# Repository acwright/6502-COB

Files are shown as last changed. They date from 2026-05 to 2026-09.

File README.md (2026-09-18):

6502-COB
========

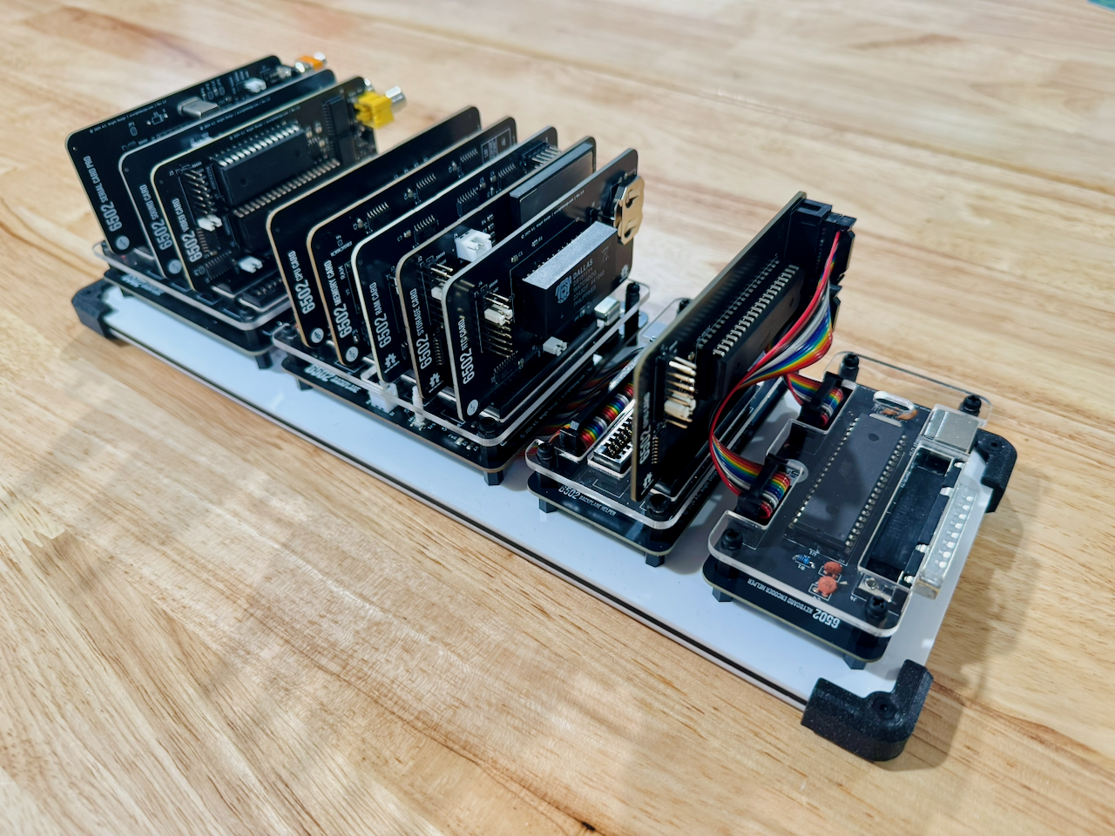
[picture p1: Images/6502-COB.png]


An **AC6502** retro-style 8-bit computer based on the **65C02** microprocessor.

> 📖 **Guide:** [AC6502 Documentation](https://acwright.github.io/6502-DOCS/) — the user's and programmer's guide for the whole family.
> See [COB's page in the family appendix](https://acwright.github.io/6502-DOCS/family/cob).

---

## Table of Contents

- [Overview](#overview)
- [Architecture](#architecture)
- [Systems](#systems)
- [Software](#software)
- [Hardware](#hardware)
  - [Backplanes](#backplanes)
  - [Cards](#cards)
  - [Helpers](#helpers)
- [Firmware](#firmware)
  - [KEH Controller](#keh-controller)
  - [PS2 Keyboard Controller](#ps2-keyboard-controller)
  - [STP Controller](#stp-controller)
- [CAD](#cad)
- [Production](#production)
- [Schematics](#schematics)
- [Libraries](#libraries)
- [Bill of Materials](#bill-of-materials)
  - [Backplane](#backplane)
  - [Backplane Helper](#backplane-helper)
  - [Backplane Pro](#backplane-pro)
  - [Blinkenlights Card](#blinkenlights-card)
  - [Breadboard Helper](#breadboard-helper)
  - [Clock Helper](#clock-helper)
  - [CPU Card](#cpu-card)
  - [CPU Card Pro](#cpu-card-pro)
  - [DB25 Helper](#db25-helper)
  - [GPIO Breadboard Helper](#gpio-breadboard-helper)
  - [GPIO Card](#gpio-card)
  - [GPIO Helper](#gpio-helper)
  - [Joystick Helper](#joystick-helper)
  - [Keyboard Encoder Helper](#keyboard-encoder-helper)
  - [Keyboard Helper](#keyboard-helper)
  - [LCD Board](#lcd-board)
  - [LCD Card](#lcd-card)
  - [Mega Helper](#mega-helper)
  - [Memory Card](#memory-card)
  - [Prototype Card](#prototype-card)
  - [PS2 Helper](#ps2-helper)
  - [RAM Card](#ram-card)
  - [RTC Card](#rtc-card)
  - [Serial Card](#serial-card)
  - [Serial Card Pro](#serial-card-pro)
  - [Sound Card](#sound-card)
  - [Storage Card](#storage-card)
  - [Storage Card Pro](#storage-card-pro)
  - [VERA Helper](#vera-helper)
  - [VGA Card](#vga-card)
  - [VGA Card Pro](#vga-card-pro)
  - [Video Card](#video-card)
  - [Video Card Pro](#video-card-pro)
- [Purchase](#purchase)
- [License](#license)

---

## Overview

The AC6502 ecosystem is a family of open-source, 65C02-based computers sharing a common architecture, memory map, and [BIOS](https://github.com/acwright/6502-BIOS). Each computer in the family is purpose-built for a different use case but runs the same software and firmware.

The **COB** (Computer on a Backplane) is a full-featured modular desktop computer. It features a real 65C02 CPU, a backplane architecture with expandable card slots, up to 544KB RAM, composite or VGA video output, CompactFlash or SD storage, a real-time clock, and support for PS/2 keyboards, matrix keyboards, and Atari 2600-compatible joysticks.

## Architecture

All AC6502 computers share:

- **CPU**: 65C02 (or accurate emulation)
- **Memory**: 32KB RAM + 32KB ROM, with optional banked RAM expansion
- **Memory Map**: Standardized across the ecosystem — zero page, stack, I/O space ($8000–$9FFF), system ROM, and interrupt vectors at $FFFA–$FFFF
- **Bus**: 16-bit address bus, 8-bit bidirectional data bus, standard 65C02 control signals (RW, PHI2, RESET, IRQ, NMI, RDY, SYNC)
- **BIOS**: A common [BIOS](https://github.com/acwright/6502-BIOS) provides the kernel, monitor, and BASIC interpreter across all systems

## Systems

| Project | Description |
|---|---|
| [6502-ACE](https://github.com/acwright/6502-ACE) | All-in-one Computer Experience — A single board computer |
| [6502-COB](https://github.com/acwright/6502-COB) | Computer On a Backplane — Modular desktop computer with expandable card slots (YOU ARE HERE) |
| [6502-DEV](https://github.com/acwright/6502-DEV) | Development Environment Vehicle — Emulation-based dev system |
| [6502-KIM](https://github.com/acwright/6502-KIM) | Keypad Input Monitor - KIM-1 inspired minimal computer |
| [6502-VCS](https://github.com/acwright/6502-VCS) | Video Computer System — Cartridge-based retro gaming console |

## Software

| Project | Description |
|---|---|
| [6502-BIOS](https://github.com/acwright/6502-BIOS) | The shared BIOS (kernel, monitor, BASIC) for all AC6502 computers |
| [6502-EMULATOR](https://github.com/acwright/6502-EMULATOR) | Emulator for the whole family — desktop app, browser build, and a command line for scripted runs |
| [6502-PRG](https://github.com/acwright/6502-PRG) | Template project for writing assembly language programs |
| [6502-CRT](https://github.com/acwright/6502-CRT) | Template project for writing assembly language cartridges |
| [6502-ASM](https://github.com/acwright/6502-ASM) | Assembly language example programs and demos |
| [6502-BAS](https://github.com/acwright/6502-BAS) | BASIC program listings |
| [6502-WOZMON](https://github.com/acwright/6502-WOZMON) | Wozmon as a standalone ROM |
| [6502-NOP](https://github.com/acwright/6502-NOP) | An all-NOP ROM, for probing a board during bring-up |
| [6502-DOCS](https://github.com/acwright/6502-DOCS) | The documentation site — the guide, the printable reference cards, branding and label artwork |
| [cffs](https://github.com/acwright/cffs) | Builds CompactFlash disk images for the BIOS filesystem |
| [bastok](https://github.com/acwright/bastok) | Tokenizes BASIC listings into `.prg` images, and back |
| [bin2woz](https://github.com/acwright/bin2woz) | Converts a binary into a Wozmon serial upload |

## Hardware

This repository contains KiCad 7.0+ PCB designs for the backplanes, cards, and helpers that make up the COB system.

### Backplanes

**`Hardware/Backplane/`** — Passive backplane providing 5 card slots with full bus interconnect across all slots.

**`Hardware/Backplane Pro/`** — Enhanced backplane with integrated clock generation, reset circuitry, and power distribution plus 5 card slots. Rev 1.1 moves to entirely through-hole components and adds an onboard power switch and DC barrel jack input.

**`Hardware/Backplane Helper/`** — Adds additional card slots to expand the total backplane configuration up to 12 slots.

### Cards

**`Hardware/CPU Card/`** — Hosts the 65C02 CPU in a card form factor for backplane-based COB systems.

**`Hardware/CPU Card Pro/`** — Hosts a 65816 16-bit CPU (backward-compatible with 65C02). *(Untested)*

**`Hardware/Memory Card/`** — Provides 32KB SRAM and 32KB EEPROM with address decoding logic for COB systems using the CPU Card.

**`Hardware/RAM Card/`** — 512KB banked RAM expansion organized as two 256KB banks with 256 × 1KB windows each.

**`Hardware/RTC Card/`** — Real-time clock via Dallas DS1511Y with battery backup and 256 bytes of battery-backed SRAM.

**`Hardware/GPIO Card/`** — General-purpose I/O via 65C22 VIA supporting keyboards, joysticks, timers, and custom devices.

**`Hardware/Serial Card/`** — RS-232 serial communication via 65C51 ACIA and MAX232 level shifter.
Female DB-9 wired as **DCE**, so a straight-through cable reaches a PC. `DCD` and `DSR` are tied to
ground; `DTR` is not connected. The `CTS EN` jumper (J4) picks whether the ACIA's `CTS` comes from
ground or from the cable — **ground is the default**, which leaves the transmitter always free to
send.

**`Hardware/Serial Card Pro/`** — Enhanced serial card with full modem control signals (DTR, DCD, DSR).
Male DB-9 wired as **DTE**, like a PC, so reaching a laptop needs a **null-modem** cable — unlike the
plain Serial Card. `CTS`, `DSR` and `DTR` always reach the cable; the `DCD EN` jumper picks ground or
the cable for `DCD` — **ground is the default**.

**The handshake lines are not decoration.** On a real R6551, measured on a KIM in 2026: `CTS` high
stops the transmitter dead, and `DCD` high stops the receiver and the arriving byte is lost. A card
jumpered to take either from the cable, plugged into something that does not assert them, looks like
a dead board — no banner, no echo — until the line comes back. Ground is the default for exactly
that reason.

**`Hardware/VGA Card/`** — VGA 640×480 video output via Raspberry Pi Pico running [Pico9918](https://github.com/visrealm/pico9918) with TMS9918A-compatible graphics modes.

**`Hardware/VGA Card Pro/`** — Fully programmable VGA output using Pi Pico with custom firmware. *(Untested)*

**`Hardware/Video Card/`** — Composite video output via TMS9918A Video Display Processor with 16KB video RAM.

**`Hardware/Video Card Pro/`** — Enhanced composite video card. *(Untested)*

**`Hardware/Sound Card/`** — 3-voice SID audio output via ARMSID module with RCA line-level output.

**`Hardware/Storage Card/`** — CompactFlash storage interface supporting up to 128GB via IDE-compatible protocol.

**`Hardware/Storage Card Pro/`** — SD card (up to 32GB) and 16MB onboard SPI flash storage interface. *(Untested, experimental — the stock BIOS has no driver for it; see [STP Controller](#stp-controller))*

**`Hardware/LCD Card/`** — 16×2 character LCD display via 65C22 VIA in 4-bit or 8-bit mode.

**`Hardware/Blinkenlights Card/`** — Visual bus monitoring with LEDs showing address bus (16), data bus (8), and control signals (8) in real time.

**`Hardware/Prototype Card/`** — Blank prototyping area with integrated breadboard and full bus access headers.

### Helpers

**`Hardware/Keyboard Encoder Helper/`** — ATmega1284p-based dual keyboard encoder supporting PS/2 keyboard and 8×8 matrix keyboard simultaneously via 65C22 VIA.

**`Hardware/PS2 Helper/`** — ATmega328p-based PS/2 keyboard bridge that drives an MT8808 analog crosspoint switch to emulate a matrix keyboard. Its output is a raw 8×8 matrix and feeds the matrix inputs of a Keyboard Encoder Helper, which is what talks to the 65C22 VIA — not the VIA directly.

**`Hardware/Keyboard Helper/`** — 64-key matrix keyboard with Atari 2600-compatible joystick support.

**`Hardware/GPIO Helper/`** — 8 buttons and 8 LEDs for testing and debugging GPIO Card connections.

**`Hardware/GPIO Breadboard Helper/`** — Breadboard interface adapter for the GPIO Card.

**`Hardware/Joystick Helper/`** — Atari 2600-style dual joystick connector and interface board.

**`Hardware/Clock Helper/`** — Manual clock control providing single-step, free-run, and halt modes for debugging real CPU systems.

**`Hardware/DB25 Helper/`** — GPIO to DB25 connector adapter for external device interfacing.

**`Hardware/Breadboard Helper/`** — Exposes the full AC6502 bus to a breadboard for prototyping and experimentation.

**`Hardware/Mega Helper/`** — Arduino Mega 2560 interface adapter for the AC6502 bus.

**`Hardware/LCD Board/`** — 320×240 TFT LCD display (ILI9341) interfaced via 65C22 VIA. *(Untested)*

**`Hardware/VERA Helper/`** — VERA FPGA video module adapter for the AC6502 bus.

## Firmware

This repository contains [PlatformIO](https://platformio.org/)-based firmware for the COB system's microcontroller helpers.

### KEH Controller
`Firmware/KEH Controller/`

Firmware for the ATmega1284p on the Keyboard Encoder Helper. Provides:

- Simultaneous PS/2 keyboard and 8×8 matrix keyboard scanning
- ASCII conversion with modifier key support (Shift, Ctrl)
- Buffered, debounced input handling
- Parallel I/O to the AC6502 bus via 65C22 VIA

See [Firmware/KEH Controller/README.md](./Firmware/KEH%20Controller/README.md) for setup and usage instructions.

### PS2 Keyboard Controller
`Firmware/PS2 Keyboard Controller/`

Firmware for the ATmega328p on the PS2 Helper. Provides:

- Interrupt-driven PS/2 keyboard scan code reading
- MT8808 analog crosspoint switch matrix control
- Make/break detection and extended scan code support
- Function key emulation via FN key combinations

The MT8808 closes row/column contacts in place of physical key switches, so this
card connects to the **matrix inputs of a Keyboard Encoder Helper**, not to a
65C22 VIA. The encoder does the scanning and ASCII conversion; wired straight to
a VIA the card produces nothing, as the BIOS has no matrix-scanning code.

See [Firmware/PS2 Keyboard Controller/README.md](./Firmware/PS2%20Keyboard%20Controller/README.md) for setup and usage instructions.

### STP Controller
`Firmware/STP Controller/`

Firmware for the ATmega328p on the Storage Card Pro. Provides:

- Memory-mapped SPI controller for 6502 bus access
- Support for SD card, 16MB SPI flash, and external SPI devices
- Dual-speed SPI (4 MHz normal operation, 400 kHz initialization)
- PHI2-synchronized interface for reliable 6502 communication

⚠️ **Experimental.** The Storage Card Pro is not part of the default I/O set the
BIOS probes for, and no COB machine is built around it today. The BIOS storage
slot expects eight True IDE CompactFlash registers at `$8C00–$8C07`; this card
presents two SPI registers instead, so a stock BIOS reports `NO DEVICE` for every
storage path. Using it needs a modified BIOS or software that drives the two
registers directly.

See [Firmware/STP Controller/README.md](./Firmware/STP%20Controller/README.md) for setup and usage instructions.

## CAD
`CAD/`

3D-printable enclosure parts and laser-cut top panels for the COB system.

## Production
`Production/`

JLCPCB-ready Gerber files and BOM/CPL for PCB fabrication and assembly.

## Schematics
`Schematics/`

PDF schematics for each board.

## Libraries
`Libraries/`

Shared KiCad symbol and footprint libraries used across all AC6502 hardware projects.

## Bill of Materials

### Backplane

| Reference | Qty | Value | Description | DigiKey | Mouser |
|---|-----|---|---|---|---|
| J1–J5 | 5 | 6502 Card Connector | Card Edge 2×20 | [A31723-ND](https://www.digikey.com/en/products/filter?keywords=A31723-ND) | [571-5-5530843-4](https://www.mouser.com/ProductDetail/571-5-5530843-4) |
| J6, J7 | 2 | 6502 Bus | Bus Connector 2×20 | [732-5401-ND](https://www.digikey.com/en/products/filter?keywords=732-5401-ND) | |

### Backplane Helper

| Reference | Qty | Value | Description | DigiKey | Mouser |
|---|-----|---|---|---|---|
| J1, J2 | 2 | 6502 Card Connector | Card Edge 2×20 | [A31723-ND](https://www.digikey.com/en/products/filter?keywords=A31723-ND) | [571-5-5530843-4](https://www.mouser.com/ProductDetail/571-5-5530843-4) |
| J3 | 1 | 6502 Bus | Bus Connector 2×20 | [732-5401-ND](https://www.digikey.com/en/products/filter?keywords=732-5401-ND) | |

### Backplane Pro

#### Rev 1.1

| Reference | Qty | Value | Description | Mouser |
|---|-----|---|---|---|
| C1, C3 | 2 | 10uF | Polarized capacitor | |
| C2 | 1 | 100nF | Unpolarized capacitor | |
| D1 | 1 | LED | Power LED 3mm | |
| J1 | 1 | 5V DC | DC Barrel Jack | [640-DCJ200-10-A-K1-K](https://www.mouser.com/ProductDetail/640-DCJ200-10-A-K1-K) |
| J2–J4, J7, J8 | 5 | 6502 Card Connector | Card Edge 2×20 | [571-5-5530843-4](https://www.mouser.com/ProductDetail/571-5-5530843-4) |
| J5 | 1 | CLOCK ENBL SW | Pin Header 1×2 | |
| J6 | 1 | RESET SW | Pin Header 1×2 | |
| J9 | 1 | 6502 Bus | Bus Connector 2×20 | |
| JP1 | 1 | Solder Jumper | Solder Jumper 2-pole | |
| Q1 | 1 | 2N3904 | NPN Transistor TO-92 | |
| R1 | 1 | 330 | Resistor | |
| R2 | 1 | 1M | Resistor | |
| R3 | 1 | 47k | Resistor | |
| R4 | 1 | 10k | Resistor | |
| R5 | 1 | 1k | Resistor | |
| SW1 | 1 | POWER | SPDT Power Switch | [612-400MSP1R6BLKM6QE](https://www.mouser.com/ProductDetail/612-400MSP1R6BLKM6QE) |
| SW2 | 1 | RESET | Tact Push Button 5mm | |
| U1 | 1 | LM555 | Timer SOIC-8 | |
| X1 | 1 | OCXO-14 | Crystal Oscillator DIP-14 | |

#### Rev 1.0

| Reference | Qty | Value | Description | LCSC | DigiKey | Mouser |
|---|-----|---|---|---|---|---|
| C1, C3–C14 | 13 | 100nF | Unpolarized capacitor | [C49678](https://www.lcsc.com/search?q=C49678) | | |
| C2 | 1 | 10uF | Polarized capacitor | [C7171](https://www.lcsc.com/search?q=C7171) | | |
| D1 | 1 | 1N5819 | Schottky Diode SOD-323F | [C191023](https://www.lcsc.com/search?q=C191023) | | |
| D2 | 1 | LED | LED 0805 | [C2297](https://www.lcsc.com/search?q=C2297) | | |
| J1 | 1 | PWR_SW | JST XH 1×2 | | [455-2247-ND](https://www.digikey.com/en/products/filter?keywords=455-2247-ND) | |
| J2 | 1 | USB-C | USB 2.0 Type-C Receptacle | [C2988369](https://www.lcsc.com/search?q=C2988369) | | |
| J3 | 1 | RESET_SW | JST XH 1×2 | | [455-2247-ND](https://www.digikey.com/en/products/filter?keywords=455-2247-ND) | |
| J4 | 1 | CLOCK_ENBL_SW | JST XH 1×2 | | [455-2247-ND](https://www.digikey.com/en/products/filter?keywords=455-2247-ND) | |
| J5–J9 | 5 | 6502 Card Connector | Card Edge 2×20 | | [A31723-ND](https://www.digikey.com/en/products/filter?keywords=A31723-ND) | [571-5-5530843-4](https://www.mouser.com/ProductDetail/571-5-5530843-4) |
| J10 | 1 | 6502 Bus | Bus Connector 2×20 | | | |
| Q1 | 1 | SS8050 | NPN Transistor SOT-23 | [C2150](https://www.lcsc.com/search?q=C2150) | | |
| R1 | 1 | 1M | Resistor | [C17514](https://www.lcsc.com/search?q=C17514) | | |
| R2 | 1 | 47k | Resistor | [C17713](https://www.lcsc.com/search?q=C17713) | | |
| R3 | 1 | 1k | Resistor | [C17513](https://www.lcsc.com/search?q=C17513) | | |
| R4 | 1 | 10k | Resistor | [C17414](https://www.lcsc.com/search?q=C17414) | | |
| R5, R6 | 2 | 5.1k | Resistor | [C27834](https://www.lcsc.com/search?q=C27834) | | |
| R7 | 1 | 330 | Resistor | [C17630](https://www.lcsc.com/search?q=C17630) | | |
| SW1 | 1 | Reset | Push Button | [C318884](https://www.lcsc.com/search?q=C318884) | | |
| U1 | 1 | LM555xM | Timer SOIC-8 | [C7593](https://www.lcsc.com/search?q=C7593) | | |
| X1 | 1 | OCXO-14 | Crystal Oscillator DIP-14 | | | |

### Blinkenlights Card

| Reference | Qty | Value | Description | LCSC |
|---|-----|---|---|---|
| C1–C4 | 4 | 100nF | Unpolarized capacitor | [C49678](https://www.lcsc.com/search?q=C49678) |
| D1–D25 | 25 | LED | LED 0805 | [C2297](https://www.lcsc.com/search?q=C2297) |
| D26, D27 | 2 | LED | LED 0805 | [C2295](https://www.lcsc.com/search?q=C2295) |
| D28–D30 | 3 | LED | LED 0805 | [C2296](https://www.lcsc.com/search?q=C2296) |
| D31, D32 | 2 | LED | LED 0805 | [C2293](https://www.lcsc.com/search?q=C2293) |
| R1–R32 | 32 | 330 | Resistor | [C17630](https://www.lcsc.com/search?q=C17630) |
| U1, U2, U4 | 3 | 74HC573 | 8-bit Latch SOIC-20 | [C5608](https://www.lcsc.com/search?q=C5608) |
| U3 | 1 | 74HC04 | Hex Inverter SOIC-14 | [C5590](https://www.lcsc.com/search?q=C5590) |

### Breadboard Helper

| Reference | Qty | Value | Description | DigiKey |
|---|-----|---|---|---|
| J1 | 1 | 6502 Bus | Bus Connector 2×20 | [732-5401-ND](https://www.digikey.com/en/products/filter?keywords=732-5401-ND) |
| J2, J3 | 2 | Pin Header | Pin Header 1×20 | |

### Clock Helper

| Reference | Qty | Value | Description |
|---|-----|---|---|
| C1 | 1 | 100nF | Capacitor |
| D1, D2 | 2 | LED | LED 3mm |
| J1 | 1 | IO | Pin Header 1×5 |
| R1–R5 | 5 | 1k | Resistor |
| R6–R8 | 3 | 330 | Resistor |
| SW1, SW2 | 2 | XKB5858-Z | DPDT Toggle Switch |
| SW3 | 1 | XKB5858-W | DPDT Toggle Switch |
| U1 | 1 | 74HC74 | Dual D Flip-flop DIP-14 |

### CPU Card

| Reference | Qty | Value | Description | LCSC |
|---|-----|---|---|---|
| C1 | 1 | 100nF | Unpolarized capacitor | [C49678](https://www.lcsc.com/search?q=C49678) |
| J2 | 1 | Pin Header | Pin Header 1×2 | |
| J3 | 1 | EXP | Pin Header 2×5 | |
| R1–R6 | 6 | 10k | Resistor | [C2930231](https://www.lcsc.com/search?q=C2930231) |
| U1 | 1 | 65C02 | CPU DIP-40 | |

#### Revision History

**Rev 1.1**

- Pull-up resistors changed from 1kΩ to 10kΩ.

**Rev 1.0**

- Initial release.

### CPU Card Pro

| Reference | Qty | Value | Description | LCSC |
|---|-----|---|---|---|
| C1–C4 | 4 | 100nF | Unpolarized capacitor | [C49678](https://www.lcsc.com/search?q=C49678) |
| J2 | 1 | BANK ADDR | Pin Header 2×5 | |
| J3 | 1 | EXP | Pin Header 2×4 | |
| R1–R6 | 6 | 1k | Resistor | [C17513](https://www.lcsc.com/search?q=C17513) |
| U1 | 1 | 65C816 | CPU DIP-40 | |
| U2 | 1 | 74HC00 | Quad NAND SOIC-14 | [C5586](https://www.lcsc.com/search?q=C5586) |
| U3 | 1 | 74HC245 | Octal Bus Transceiver TSSOP-20 | [C5626](https://www.lcsc.com/search?q=C5626) |
| U4 | 1 | 74HC573 | 8-bit Latch SOIC-20 | [C5608](https://www.lcsc.com/search?q=C5608) |

### DB25 Helper

| Reference | Qty | Value | Description | DigiKey |
|---|-----|---|---|---|
| J1 | 1 | PORT A | GPIO Connector 2×6 | |
| J2 | 1 | PORT B | GPIO Connector 2×6 | |
| J3 | 1 | KEYBOARD | DB-25 Connector (Male) | [609-1505-ND](https://www.digikey.com/en/products/filter?keywords=609-1505-ND) |

### GPIO Breadboard Helper

| Reference | Qty | Value | Description |
|---|-----|---|---|
| J1 | 1 | PORT A | GPIO Connector 2×6 |
| J2 | 1 | PORT A | Pin Header 1×12 |
| J3 | 1 | PORT B | Pin Header 1×12 |
| J4 | 1 | PORT B | GPIO Connector 2×6 |

### GPIO Card

| Reference | Qty | Value | Description | LCSC |
|---|-----|---|---|---|
| C1, C2 | 2 | 100nF | Unpolarized capacitor | [C49678](https://www.lcsc.com/search?q=C49678) |
| D1 | 1 | Schottky Diode | Schottky Diode DO-35 | |
| J2 | 1 | IO SELECT | Pin Header 2×8 | |
| J3 | 1 | PORT A | GPIO Connector 2×6 | |
| J4 | 1 | PORT B | GPIO Connector 2×6 | |
| U1 | 1 | 74HC138 | Decoder SOIC-16 | [C5602](https://www.lcsc.com/search?q=C5602) |
| U2 | 1 | 65C22 | VIA DIP-40 | |

### GPIO Helper

| Reference | Qty | Value | Description | DigiKey |
|---|-----|---|---|---|
| D1–D8 | 8 | LED | LED 3mm | |
| J1 | 1 | PORT A | GPIO Connector 2×6 | |
| J2 | 1 | PORT B | GPIO Connector 2×6 | |
| R1–R8 | 8 | 1k | Resistor | |
| R9–R16 | 8 | 330 | Resistor | |
| SW1–SW8 | 8 | Push Button | Push Button 6mm | [2223-TS02-66-50-BK-160-LCR-D-ND](https://www.digikey.com/en/products/filter?keywords=2223-TS02-66-50-BK-160-LCR-D-ND) |

### Joystick Helper

| Reference | Qty | Value | Description | DigiKey |
|---|-----|---|---|---|
| J1 | 1 | PORT | GPIO Connector 2×6 | |
| J2 | 1 | DB-9 Male | DB-9 Connector (Male) | [609-1481-ND](https://www.digikey.com/en/products/filter?keywords=609-1481-ND) |
| R1–R8 | 8 | 1k | Resistor | |

### Keyboard Encoder Helper

| Reference | Qty | Value | Description | DigiKey |
|---|-----|---|---|---|
| C1, C4 | 2 | 100nF | Capacitor | |
| C2, C3 | 2 | 22pF | Capacitor | |
| J1 | 1 | PORT B | GPIO Connector 2×6 | |
| J2 | 1 | PORT A | GPIO Connector 2×6 | |
| J3 | 1 | PS/2 KEYBOARD | 6-pin Mini-DIN | |
| J4 | 1 | KEYBOARD | DB-25 Connector (Male) | [609-1505-ND](https://www.digikey.com/en/products/filter?keywords=609-1505-ND) |
| R1 | 1 | 1k | Resistor | |
| U1 | 1 | ATmega1284-P | MCU DIP-40 | |
| Y1 | 1 | 16 MHz | Crystal HC49-U | [3155-16M20P2/49US-ND](https://www.digikey.com/en/products/filter?keywords=3155-16M20P2/49US-ND) |

### Keyboard Helper

| Reference | Qty | Value | Description | DigiKey |
|---|-----|---|---|---|
| J1, J2 | 2 | JOYSTICK | DB-9 Connector (Male) | [609-1481-ND](https://www.digikey.com/en/products/filter?keywords=609-1481-ND) |
| J3, J4 | 2 | JOYSTICK | GPIO Connector 2×6 | |
| J5, J6 | 2 | PORT | GPIO Connector 2×6 | |
| J7 | 1 | KEYBOARD | DB-25 Connector (Male) | [609-1505-ND](https://www.digikey.com/en/products/filter?keywords=609-1505-ND) |
| R1–R16 | 16 | 1k | Resistor | |
| SW1–SW67 | 67 | Cherry MX | Key Switch | |

### LCD Board

| Reference | Qty | Value | Description |
|---|-----|---|---|
| C1–C4 | 4 | 100nF | Capacitor |
| D1, D2 | 2 | Schottky Diode | Schottky Diode DO-35 |
| J1 | 1 | 6502 Bus | Bus Connector 2×20 |
| J2 | 1 | IO SELECT | Pin Header 2×8 |
| J3 | 1 | HVSYNC | Pin Header 1×1 |
| R1 | 1 | 10k | Resistor |
| U1 | 1 | 65C22 | VIA DIP-40 |
| U2 | 1 | Adafruit 2.8" TFT | TFT LCD Module |
| U3 | 1 | 74HC138 | Decoder DIP-16 |

### LCD Card

| Reference | Qty | Value | Description | LCSC |
|---|-----|---|---|---|
| C1, C2 | 2 | 100nF | Unpolarized capacitor | [C49678](https://www.lcsc.com/search?q=C49678) |
| D1 | 1 | Schottky Diode | Schottky Diode DO-35 | |
| J2 | 1 | GPIO | Pin Header 1×7 | |
| J3 | 1 | IO SELECT | Pin Header 2×8 | |
| R1 | 1 | R | Resistor | |
| U1 | 1 | 65C22 | VIA DIP-40 | |
| U2 | 1 | LCD-16X2 | 16×2 Character LCD | |
| U3 | 1 | 74HC138 | Decoder SOIC-16 | [C5602](https://www.lcsc.com/search?q=C5602) |
| VR1 | 1 | 10k | Potentiometer | |

### Mega Helper

| Reference | Qty | Value | Description |
|---|-----|---|---|
| A1 | 1 | Arduino Mega 2560 | Arduino Mega 2560 R3 Shield |
| J1 | 1 | 6502 Bus | Bus Connector 2×20 |

### Memory Card

| Reference | Qty | Value | Description | LCSC |
|---|-----|---|---|---|
| C1–C5 | 5 | 100nF | Unpolarized capacitor | [C49678](https://www.lcsc.com/search?q=C49678) |
| J2 | 1 | Pin Header | Pin Header 2×2 | |
| J3 | 1 | Pin Header | Pin Header 1×2 | |
| R1, R2 | 2 | 1k | Resistor | [C17513](https://www.lcsc.com/search?q=C17513) |
| U1, U2, U5 | 3 | 74HC00 | Quad NAND SOIC-14 | [C5586](https://www.lcsc.com/search?q=C5586) |
| U3 | 1 | AS6C62256 | SRAM DIP-28 | |
| U4 | 1 | AT28C256 | EEPROM DIP-28 | |

### Prototype Card

| Reference | Qty | Value | Description | LCSC |
|---|-----|---|---|---|
| C1–C3 | 3 | 100nF | Unpolarized capacitor | [C49678](https://www.lcsc.com/search?q=C49678) |
| J2 | 1 | Bus Header | Pin Socket 2×20 | |
| J3 | 1 | EXP | Pin Header 2×4 | |
| U1 | 1 | 74HC138 | Decoder SOIC-16 | [C5602](https://www.lcsc.com/search?q=C5602) |

### PS2 Helper

| Reference | Qty | Value | Description |
|---|-----|---|---|
| C1–C3 | 3 | 100nF | Disc Capacitor |
| C4, C5 | 2 | 22pF | Disc Capacitor |
| J1 | 1 | PORT A | GPIO Connector 2×6 |
| J2 | 1 | PORT B | GPIO Connector 2×6 |
| J3 | 1 | PS/2 | Mini-DIN 6-pin |
| J4 | 1 | JOYSTICK | GPIO Connector 2×6 |
| R1–R9 | 9 | 1k | Resistor |
| U1 | 1 | MT8808 | Analog Matrix Switch DIP-28 |
| U2 | 1 | ATmega328 | MCU DIP-28 |
| Y1 | 1 | 16 MHz | Crystal |

### RAM Card

| Reference | Qty | Value | Description | LCSC |
|---|-----|---|---|---|
| C1–C7 | 7 | 100nF | Unpolarized Capacitor | [C49678](https://www.lcsc.com/search?q=C49678) |
| J2 | 1 | LATCH EN | Pin Header 1×2 | |
| J3 | 1 | Conn_02x08 | Pin Header 2×8 | |
| J4 | 1 | BANK ADDR | Pin Header 2×5 | |
| R1, R2 | 2 | 10k | Resistor | [C17414](https://www.lcsc.com/search?q=C17414) |
| U1 | 1 | AS6C4008 | SRAM DIP-32 | |
| U2 | 1 | 74HC573 | Octal Latch SOIC-20 | [C5608](https://www.lcsc.com/search?q=C5608) |
| U3, U6 | 2 | 74HC00 | Quad NAND SOIC-14 | [C5586](https://www.lcsc.com/search?q=C5586) |
| U4 | 1 | 74HC21 | Dual 4-input AND SOIC-14 | [C75398](https://www.lcsc.com/search?q=C75398) |
| U5 | 1 | 74HC30 | 8-input NAND SOIC-14 | [C19818870](https://www.lcsc.com/search?q=C19818870) |
| U7 | 1 | 74HC138 | Decoder SOIC-16 | [C5602](https://www.lcsc.com/search?q=C5602) |

### RTC Card

| Reference | Qty | Value | Description | LCSC | DigiKey |
|---|-----|---|---|---|---|
| BT1 | 1 | BAT-HLD-001-THM | Coin Cell Battery Holder | | |
| C1–C3 | 3 | 100nF | Unpolarized Capacitor | [C49678](https://www.lcsc.com/search?q=C49678) | |
| D1 | 1 | Schottky Diode | Schottky Diode DO-35 | | |
| J2 | 1 | AUX | Pin Header 1×6 | | |
| J3 | 1 | INT Select | Pin Header 1×3 | | |
| J4 | 1 | Conn_02x08 | Pin Header 2×8 | | |
| R1 | 1 | 1k | Resistor | [C17513](https://www.lcsc.com/search?q=C17513) | |
| U1 | 1 | DS1511Y | RTC DIP-28 | | [DS1511Y+-ND](https://www.digikey.com/en/products/filter?keywords=DS1511Y+-ND) |
| U2, U3 | 2 | 74HC138 | Decoder SOIC-16 | [C5602](https://www.lcsc.com/search?q=C5602) | |

### Serial Card

| Reference | Qty | Value | Description | LCSC | DigiKey |
|---|-----|---|---|---|---|
| C1, C6, C8 | 3 | 100nF | Unpolarized Capacitor | [C49678](https://www.lcsc.com/search?q=C49678) | |
| C2–C5 | 4 | 1uF | Unpolarized Capacitor | [C28323](https://www.lcsc.com/search?q=C28323) | |
| C7 | 1 | 22pF | Unpolarized Capacitor | [C1804](https://www.lcsc.com/search?q=C1804) | |
| D1 | 1 | Schottky Diode | Schottky Diode DO-35 | | |
| J2 | 1 | DB9 FEMALE (DCE) | DB-9 Connector (Female) | | [609-1487-ND](https://www.digikey.com/en/products/filter?keywords=609-1487-ND) |
| J3 | 1 | Conn_02x08 | Pin Header 2×8 | | |
| J4 | 1 | CTS EN | Pin Header 1×3 | | |
| R1 | 1 | 1M | Resistor | [C103906](https://www.lcsc.com/search?q=C103906) | |
| U1 | 1 | MAX232 | RS-232 Driver/Receiver | [C59824](https://www.lcsc.com/search?q=C59824) | |
| U2 | 1 | 74HC138 | Decoder SOIC-16 | [C5602](https://www.lcsc.com/search?q=C5602) | |
| U3 | 1 | 6551 | ACIA DIP-28 | | |
| Y1 | 1 | 1.8432 MHz | Crystal | | |

### Serial Card Pro

| Reference | Qty | Value | Description | LCSC | DigiKey |
|---|-----|---|---|---|---|
| C1, C2, C11, C13 | 4 | 100nF | Unpolarized Capacitor | [C49678](https://www.lcsc.com/search?q=C49678) | |
| C3–C10 | 8 | 1uF | Unpolarized Capacitor | [C28323](https://www.lcsc.com/search?q=C28323) | |
| C12 | 1 | 22pF | Unpolarized Capacitor | [C1804](https://www.lcsc.com/search?q=C1804) | |
| D1 | 1 | Schottky Diode | Schottky Diode DO-35 | | |
| J2 | 1 | DB9 MALE (DTE) | DB-9 Connector (Male) | | [609-1481-ND](https://www.digikey.com/en/products/filter?keywords=609-1481-ND) |
| J3 | 1 | Conn_02x08 | Pin Header 2×8 | | |
| J4 | 1 | DCD Select | Pin Header 1×3 | | |
| R1 | 1 | 1M | Resistor | [C103906](https://www.lcsc.com/search?q=C103906) | |
| U1, U2 | 2 | MAX232 | RS-232 Driver/Receiver | [C59824](https://www.lcsc.com/search?q=C59824) | |
| U3 | 1 | 74HC138 | Decoder SOIC-16 | [C5602](https://www.lcsc.com/search?q=C5602) | |
| U4 | 1 | 6551 | ACIA DIP-28 | | |
| Y1 | 1 | 1.8432 MHz | Crystal | | |

### Sound Card

| Reference | Qty | Value | Description | LCSC | DigiKey |
|---|-----|---|---|---|---|
| C1, C2 | 2 | 2.2nF | Unpolarized Capacitor | [C28260](https://www.lcsc.com/search?q=C28260) | |
| C3, C5 | 2 | 100nF | Unpolarized Capacitor | [C49678](https://www.lcsc.com/search?q=C49678) | |
| C4 | 1 | 1uF | Unpolarized Capacitor | [C28323](https://www.lcsc.com/search?q=C28323) | |
| J2 | 1 | VDD | JST XH 1×2 | | |
| J3 | 1 | AUDIO | RCA Connector | | [PJRAN1X1U02X](https://www.digikey.com/en/products/detail/switchcraft-inc/PJRAN1X1U02X/1832412) |
| J5 | 1 | Conn_02x08 | Pin Header 2×8 | | |
| R1 | 1 | 1k | Resistor | [C17513](https://www.lcsc.com/search?q=C17513) | |
| U1 | 1 | 6581 | SID Chip DIP-28 | | |
| U2 | 1 | 74HC138 | Decoder SOIC-16 | [C5602](https://www.lcsc.com/search?q=C5602) | |

### Storage Card

| Reference | Qty | Value | Description | LCSC |
|---|-----|---|---|---|
| C1, C2 | 2 | 100nF | Unpolarized Capacitor | [C49678](https://www.lcsc.com/search?q=C49678) |
| D1 | 1 | LED | Activity LED 0805 | [C2297](https://www.lcsc.com/search?q=C2297) |
| J2 | 1 | Conn_02x08 | Pin Header 2×8 | |
| J3 | 1 | Compact Flash | CompactFlash Connector | [C444350](https://www.lcsc.com/search?q=C444350) |
| J4 | 1 | ACT LED | JST XH 1×2 | |
| R1–R4 | 4 | 1k | Resistor | [C17513](https://www.lcsc.com/search?q=C17513) |
| R5, R6 | 2 | 330 | Resistor | [C17630](https://www.lcsc.com/search?q=C17630) |
| U1 | 1 | 74HC00 | Quad NAND SOIC-14 | [C5586](https://www.lcsc.com/search?q=C5586) |
| U2 | 1 | 74HC138 | Decoder SOIC-16 | [C5602](https://www.lcsc.com/search?q=C5602) |

### Storage Card Pro

| Reference | Qty | Value | Description | LCSC | DigiKey |
|---|-----|---|---|---|---|
| C1–C4, C7, C8 | 6 | 100nF | Unpolarized Capacitor | [C49678](https://www.lcsc.com/search?q=C49678) | |
| C5, C6 | 2 | 22pF | Disc Capacitor | [C107114](https://www.lcsc.com/search?q=C107114) | |
| C9, C10 | 2 | 1uF | Unpolarized Capacitor | [C28323](https://www.lcsc.com/search?q=C28323) | |
| D1 | 1 | LED | Activity LED 0805 | [C2297](https://www.lcsc.com/search?q=C2297) | |
| J1 | 1 | ACT LED | JST XH 1×2 | | |
| J3 | 1 | SPI | Pin Header 1×6 | | |
| J4 | 1 | SD CARD | SD Card Connector | [C569097](https://www.lcsc.com/search?q=C569097) | |
| J5 | 1 | Conn_02x08 | Pin Header 2×8 | | |
| R1, R2 | 2 | 330 | Resistor | [C17630](https://www.lcsc.com/search?q=C17630) | |
| R3, R4 | 2 | 1k | Resistor | [C17513](https://www.lcsc.com/search?q=C17513) | |
| U1 | 1 | TXS0108EPW | Level Shifter TSSOP-20 | [C17206](https://www.lcsc.com/search?q=C17206) | |
| U2 | 1 | ATmega328 | MCU DIP-28 | | |
| U3 | 1 | W25Q128JVS | Flash Memory SOIC-8 | [C97521](https://www.lcsc.com/search?q=C97521) | |
| U4 | 1 | 74HC138 | Decoder SOIC-16 | [C5602](https://www.lcsc.com/search?q=C5602) | |
| U5 | 1 | LP2985-3.3 | LDO Regulator 3.3V SOT-23-5 | [C95414](https://www.lcsc.com/search?q=C95414) | |
| Y1 | 1 | 16 MHz | Crystal | | [3155-16M20P2/49US-ND](https://www.digikey.com/en/products/filter?keywords=3155-16M20P2/49US-ND) |

### VERA Helper

| Reference | Qty | Value | Description | DigiKey |
|---|-----|---|---|---|
| C1, C2 | 2 | 100nF | Disc Capacitor | |
| D1 | 1 | Schottky Diode | Schottky Diode DO-35 | |
| J1 | 1 | 6502 Bus | Bus Connector 2×20 | |
| J2 | 1 | VERA Module | Pin Header 2×12 | |
| J3 | 1 | Audio L | RCA Connector | [PJRAN1X1U02X](https://www.digikey.com/en/products/detail/switchcraft-inc/PJRAN1X1U02X/1832412) |
| J4 | 1 | Audio R | RCA Connector | [PJRAN1X1U03X](https://www.digikey.com/en/products/detail/switchcraft-inc/PJRAN1X1U03X/1832413) |
| J5 | 1 | INT Select | Pin Header 1×3 | |
| J6 | 1 | Conn_02x08 | Pin Header 2×8 | |
| U1, U2 | 2 | 74HC138 | Decoder DIP-16 | |

### VGA Card

| Reference | Qty | Value | Description | LCSC |
|---|-----|---|---|---|
| C1, C2 | 2 | 100nF | Unpolarized Capacitor | [C49678](https://www.lcsc.com/search?q=C49678) |
| D1 | 1 | Schottky Diode | Schottky Diode DO-35 | |
| J2 | 1 | INT Select | Pin Header 1×3 | |
| J3 | 1 | Conn_02x08 | Pin Header 2×8 | |
| U1 | 1 | Pico9918A | VDP Module DIP-40 | |
| U2, U3 | 2 | 74HC138 | Decoder SOIC-16 | [C5602](https://www.lcsc.com/search?q=C5602) |

### VGA Card Pro

| Reference | Qty | Value | Description | LCSC |
|---|-----|---|---|---|
| C1–C6 | 6 | 100nF | Unpolarized Capacitor | [C49678](https://www.lcsc.com/search?q=C49678) |
| D1 | 1 | Schottky Diode | Schottky Diode DO-35 | |
| J2 | 1 | VGA | DB-15 VGA Connector (Female) | |
| J3 | 1 | INT Select | Pin Header 1×3 | |
| J4 | 1 | Conn_02x08 | Pin Header 2×8 | |
| Q1 | 1 | BSS138 | N-Channel MOSFET SOT-23 | [C78284](https://www.lcsc.com/search?q=C78284) |
| R1, R2, R4, R7 | 4 | 1k | Resistor | [C17513](https://www.lcsc.com/search?q=C17513) |
| R3, R6 | 2 | 2.2k | Resistor | [C17520](https://www.lcsc.com/search?q=C17520) |
| R5, R8 | 2 | 470 | Resistor | [C17710](https://www.lcsc.com/search?q=C17710) |
| R9 | 1 | 820 | Resistor | [C17837](https://www.lcsc.com/search?q=C17837) |
| R10 | 1 | 390 | Resistor | [C17655](https://www.lcsc.com/search?q=C17655) |
| R11, R12 | 2 | 22 | Resistor | [C17561](https://www.lcsc.com/search?q=C17561) |
| U1 | 1 | SN74LVC4245APWR | Octal Bus Transceiver TSSOP-24 | [C7859](https://www.lcsc.com/search?q=C7859) |
| U2 | 1 | 74LVC245 | Octal Bus Transceiver TSSOP-20 | [C6082](https://www.lcsc.com/search?q=C6082) |
| U3 | 1 | Raspberry Pi Pico | MCU Module | |
| U4 | 1 | 74HC138 | Decoder SOIC-16 | [C5602](https://www.lcsc.com/search?q=C5602) |
| U5 | 1 | 74LVC138 | Decoder SOIC-16 | [C6061](https://www.lcsc.com/search?q=C6061) |

### Video Card

| Reference | Qty | Value | Description | LCSC | Mouser | DigiKey |
|---|-----|---|---|---|---|---|
| C1, C2 | 2 | 32pF | Disc Capacitor | [C107114](https://www.lcsc.com/search?q=C107114) | | |
| C3–C10 | 8 | 100nF | Unpolarized Capacitor | [C49678](https://www.lcsc.com/search?q=C49678) | | |
| D1 | 1 | Schottky Diode | Schottky Diode DO-35 | | | |
| FB1 | 1 | BLM41PG600SN1L | Ferrite Bead 1806 | [C85844](https://www.lcsc.com/search?q=C85844) | | |
| J1 | 1 | INT Select | Pin Header 1×3 | | | |
| J3 | 1 | Conn_02x08 | Pin Header 2×8 | | | |
| J4 | 1 | VIDEO | RCA Connector | | | [PJRAN1X1U04X](https://www.digikey.com/en/products/detail/switchcraft-inc/PJRAN1X1U04X/969899) |
| Q1 | 1 | 2N4401 | NPN BJT TO-92 | | | |
| R1 | 1 | 470 | Resistor | [C17710](https://www.lcsc.com/search?q=C17710) | | |
| R2 | 1 | 75 | Resistor | [C17820](https://www.lcsc.com/search?q=C17820) | | |
| U1 | 1 | TMS9918A | VDP DIP-40 | | | |
| U2, U5, U6 | 3 | 74HCT574 | 8-bit Register SOIC-20 | [C6001](https://www.lcsc.com/search?q=C6001) | | |
| U3, U4 | 2 | 74HC138 | Decoder SOIC-16 | [C5602](https://www.lcsc.com/search?q=C5602) | | |
| U7 | 1 | AS6C62256 | SRAM DIP-28 | | | |
| U8 | 1 | 74HCT04 | Hex Inverter SO-14 | [C672096](https://www.lcsc.com/search?q=C672096) | | |
| Y1 | 1 | 10.738635 MHz | Crystal | | [774-MP107-E](https://www.mouser.com/ProductDetail/774-MP107-E) | |

### Video Card Pro

| Reference | Qty | Value | Description | LCSC | Mouser | DigiKey |
|---|-----|---|---|---|---|---|
| C1, C2 | 2 | 20pF | Disc Capacitor | [C105173](https://www.lcsc.com/search?q=C105173) | | |
| C3–C10 | 8 | 100nF | Unpolarized Capacitor | [C49678](https://www.lcsc.com/search?q=C49678) | | |
| D1 | 1 | Schottky Diode | Schottky Diode DO-35 | | | |
| FB1 | 1 | BLM41PG600SN1L | Ferrite Bead 1806 | [C85844](https://www.lcsc.com/search?q=C85844) | | |
| J1 | 1 | VIDEO | RCA Connector | | | [PJRAN1X1U04X](https://www.digikey.com/en/products/detail/switchcraft-inc/PJRAN1X1U04X/969899) |
| J2 | 1 | SERIAL | Pin Header 1×4 | | | |
| J3 | 1 | INT Select | Pin Header 1×3 | | | |
| J5 | 1 | Conn_02x08 | Pin Header 2×8 | | | |
| Q1 | 1 | 2N4401 | NPN BJT TO-92 | | | |
| R1, R2 | 2 | 4.7k | Resistor | | | |
| R3 | 1 | 470 | Resistor | [C17710](https://www.lcsc.com/search?q=C17710) | | |
| R4 | 1 | 75 | Resistor | [C17820](https://www.lcsc.com/search?q=C17820) | | |
| R5 | 1 | 1k | Resistor | | | |
| U1, U4 | 2 | 74HC157 | Quad 2-to-1 Mux SOIC-16 | [C6823](https://www.lcsc.com/search?q=C6823) | | |
| U2, U5 | 2 | 74HC166 | Shift Register SOIC-16 | [C473363](https://www.lcsc.com/search?q=C473363) | | |
| U3 | 1 | ATmega1284-P | MCU DIP-40 | | | |
| U6 | 1 | 74HC138 | Decoder SOIC-16 | [C5602](https://www.lcsc.com/search?q=C5602) | | |
| VR1, VR2 | 2 | 10k | Potentiometer | | | |
| Y1 | 1 | 14.31818 MHz | Crystal | | [774-MP107-E](https://www.mouser.com/ProductDetail/774-MP107-E) | |

## Purchase

I have a few PCBs available on Tindie for those interested in building their own AC6502 system without ordering from a fab directly.



## License

Hardware designs are released under the [CERN Open Hardware Licence Version 2 – Permissive](https://ohwr.org/cern_ohl_p_v2.txt).  
Firmware is released under the MIT License — [KEH Controller](./Firmware/KEH%20Controller/LICENSE), [PS2 Keyboard Controller](./Firmware/PS2%20Keyboard%20Controller/LICENSE), [STP Controller](./Firmware/STP%20Controller/LICENSE).

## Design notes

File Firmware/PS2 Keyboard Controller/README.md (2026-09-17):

# PS2 Keyboard Controller

## Overview

This firmware runs on an ATmega328/ATmega328P microcontroller and acts as a bridge between a PS/2 keyboard and a custom keyboard matrix interface. It reads PS/2 scan codes from a standard PS/2 keyboard and translates them to control an MT8808 analog crosspoint switch, closing the same row/column contacts a physical key switch would.

> ⚠️ **This card feeds a keyboard encoder, not a VIA directly.** The MT8808
> output is a *raw 8×8 matrix* — it takes the place of the key switches, not of
> the encoder that scans them. Wire the PS2 Helper's PORT A / PORT B headers to
> the **matrix inputs of a Keyboard Encoder Helper** (see
> [KEH Controller](../KEH%20Controller/README.md)), which does the scanning,
> debouncing and ASCII conversion, and hands a finished byte plus a `CB1` strobe
> to the 65C22 VIA.
>
> Wired straight to a VIA this card produces nothing. The BIOS has no
> matrix-scanning code anywhere; its keyboard path expects a completed ASCII byte
> on PORT B with a `CB1` strobe, which is what the KEH provides and this card
> does not.

## Features

- **PS/2 Keyboard Interface**: Reads scan codes from PS/2 keyboards using interrupt-driven communication
- **Make/Break Detection**: Handles both key press (make) and key release (break) events
- **Extended Scan Codes**: Supports extended PS/2 scan codes (E0 prefix) for special keys
- **Function Key Emulation**: Maps F1-F10 function keys to FN + number key combinations
- **Buffered Input**: Uses a 16-byte circular buffer to prevent scan code loss
- **MT8808 Control**: Drives an 8×8 analog crosspoint switch matrix via 3-bit X/Y addressing
- **Matrix Emulation**: Presents itself to a keyboard encoder as a physical 8×8 key matrix, not as a byte-wide port

## Hardware Requirements

### Microcontroller
- ATmega328 or ATmega328P (DIP28 package)
- 16 MHz crystal oscillator recommended for accurate timing

### External Components
- **MT8808**: 8×8 analog crosspoint switch IC
- **PS/2 Keyboard**: Standard PS/2 keyboard with clock and data lines
- **Keyboard encoder**: The MT8808 matrix output (PORT A = rows, PORT B = columns)
  connects to the matrix inputs of a Keyboard Encoder Helper running
  [KEH Controller](../KEH%20Controller/README.md). The encoder scans this matrix
  and is what talks to the 65C22 VIA — the crosspoint switch never drives the VIA
  itself.

### Pin Mapping

| Function | ATmega328 Pin | Arduino Pin |
|---|---|---|
| PS2 CLK  | PD2 (INT0) | D2 |
| PS2 DATA | PD3 (INT1) | D3 |
| AX0 | PC0 (A0) | A0/D14 |
| AX1 | PC1 (A1) | A1/D15 |
| AX2 | PC2 (A2) | A2/D16 |
| AY0 | PC3 (A3) | A3/D17 |
| AY1 | PC4 (A4) | A4/D18 |
| AY2 | PC5 (A5) | A5/D19 |
| DATA | PB3 | D11 |
| STROBE | PB4 | D12 |
| RESET | PB5 | D13 |

## Keyboard Matrix Layout

The firmware maps PS/2 scan codes to an 8×8 matrix layout:

```
      PB0    PB1    PB2    PB3    PB4    PB5    PB6    PB7
PA0:  `      1      2      3      4      5      6      7
PA1:  8      9      0      -      =      BS     ESC    TAB
PA2:  q      w      e      r      t      y      u      i
PA3:  o      p      [      ]      \      INS    CAPS   a
PA4:  s      d      f      g      h      j      k      l
PA5:  ;      '      ENTER  DEL    SHIFT  z      x      c
PA6:  v      b      n      m      ,      .      /      UP
PA7:  CTRL   GUI    ALT    SPACE  FN     LEFT   DOWN   RIGHT
```

### Special Keys
- **Backspace**: 0x08
- **Escape**: 0x1B
- **Tab**: 0x09
- **Insert**: 0x1A
- **Delete**: 0x7F
- **Enter**: 0x0D
- **Arrow Keys**: UP (0x1E), LEFT (0x1C), DOWN (0x1F), RIGHT (0x1D)
- **Function Keys**: F1-F10 mapped as FN + number keys 1-0

## How It Works

### PS/2 Communication Protocol

The firmware uses interrupt-driven PS/2 communication:

1. **Interrupt Handler**: Triggered on falling edge of PS/2 CLK line
2. **Data Reception**: Reads 11-bit frames (1 start, 8 data, 1 parity, 1 stop)
3. **Parity Checking**: Validates odd parity; discards invalid frames
4. **Buffering**: Stores valid scan codes in a 16-byte circular buffer
5. **Timeout Handling**: Resets state machine if >250ms between clock pulses

### Scan Code Translation

The main loop processes buffered scan codes:

1. **Prefix Detection**: Handles E0 (extended) and F0 (break) prefixes
2. **Extended Keys**: Maps navigation keys (arrows, insert, delete) and modifier keys
3. **Make/Break**: Sets matrix switches high (1) for key press, low (0) for key release
4. **Function Keys**: Simultaneously activates FN key + number key positions

### MT8808 Matrix Control

The `writeMatrix()` function controls the crosspoint switch:

1. Sets 3-bit X address (columns PB0-PB7)
2. Sets 3-bit Y address (rows PA0-PA7)
3. Sets DATA line (1 = close switch, 0 = open switch)
4. Pulses STROBE to latch the command
5. Each operation takes ~3ms with delays for signal stability

## Build Instructions

### Prerequisites

1. **PlatformIO**: Install PlatformIO IDE or PlatformIO Core
   ```bash
   # Install PlatformIO Core (if not using IDE)
   pip install platformio
   ```

2. **TL866 Programmer** (optional): For uploading via minipro
   ```bash
   # macOS
   brew install minipro
   
   # Linux
   sudo apt-get install minipro
   ```

### Building the Firmware

#### Using PlatformIO IDE

1. Open the project folder in VS Code with PlatformIO extension
2. Select the environment (atmega328p or atmega328)
3. Click **Build** from the PlatformIO toolbar (or press `Ctrl+Alt+B`)

#### Using PlatformIO Core

```bash
# Navigate to project directory
cd "/Users/acwright/Developer/6502/Firmware/PS2 Keyboard Controller"

# Build for ATmega328P
pio run -e atmega328p

# Build for ATmega328
pio run -e atmega328

# Clean build files
pio run --target clean
```

The compiled firmware will be located at:
- `.pio/build/atmega328p/firmware.hex` (for ATmega328P)
- `.pio/build/atmega328/firmware.hex` (for ATmega328)

### Build Environments

#### atmega328p
- **Platform**: Atmel AVR
- **Board**: ATmega328P
- **Framework**: Arduino
- **Clock**: 16 MHz (default)

#### atmega328
- **Platform**: Atmel AVR
- **Board**: ATmega328 (no "P" variant)
- **Framework**: Arduino
- **Clock**: 16 MHz (default)

### Dependencies

The firmware requires the following library (automatically installed by PlatformIO):
- **CircularBuffer** v1.4.0 by Roberto Lo Giacco

## Upload Instructions

### Using TL866 Programmer (minipro)

The project is configured to use a TL866 programmer by default:

```bash
# Upload to ATmega328P
pio run -e atmega328p --target upload

# Upload to ATmega328
pio run -e atmega328 --target upload
```

This command will:
1. Write the compiled firmware to the chip
2. Program the fuse bits from `fuses.cfg`

Lock bits are **not** programmed — the upload command passes `--fuses` only.

### Manual Upload with AVRdude

If using a different programmer:

```bash
# Using USBasp
avrdude -c usbasp -p m328p -U flash:w:.pio/build/atmega328p/firmware.hex:i

# Using Arduino as ISP
avrdude -c avrisp -p m328p -P /dev/ttyUSB0 -b 19200 \
        -U flash:w:.pio/build/atmega328p/firmware.hex:i
```

### Fuse Configuration

The `fuses.cfg` file contains the following settings:

```
lfuse = 0xFF  (Low power crystal oscillator 8.0-16.0 MHz, max startup time)
hfuse = 0xFF  (SPIEN enabled, bootloader disabled)
efuse = 0xFF  (Brown-out detection disabled)
lock  = 0xFF  (No memory lock — unprogrammed, never written)
```

**Note**: `lfuse = 0xFF` puts `CKSEL3:0` at `1111`, which selects the *Low Power*
crystal oscillator (8.0–16.0 MHz) — the right setting for the PS2 Helper's 16 MHz
crystal (`Y1`). Full Swing is a different setting (`CKSEL3:1 = 011`) and is not
used here.

**Note**: Lock bits are left unprogrammed on all of these boards. The upload
command writes fuses only (`--fuses`, no `--lock`), so the `lock` line above is
recorded for reference and never programmed.

## Configuration

### Adjusting the Buffer Size

To change the circular buffer size, modify the `BUFFER_SIZE` definition in [src/main.cpp](src/main.cpp):

```cpp
#define BUFFER_SIZE 16  // Change to desired size (must be power of 2)
```

### Customizing Key Mappings

Key mappings are defined in the `ps2ToMatrix()` function. To change a key mapping:

1. Find the PS/2 scan code in the switch statement
2. Modify the `writeMatrix(x, y, data)` call with new coordinates

Example - remapping the 'A' key from (7,3) to (4,2):

```cpp
case 0x1C:      // A
  writeMatrix(0x4, 0x2, release ? 0x0 : 0x1);  // Changed from (0x3, 0x7)
  break;
```

## Troubleshooting

### PS/2 Keyboard Not Responding
- Check PS/2 CLK and DATA connections
- Verify pull-up resistors on PS/2 lines (typically 10kΩ)
- Ensure PS/2 keyboard is receiving 5V power

### Keys Not Registering
- Verify MT8808 connections and power supply
- Check 3-bit address lines (AX0-AX2, AY0-AY2)
- Test DATA and STROBE signals with oscilloscope
- Ensure RESET line properly initializes MT8808

### No Keys Reach the Computer at All
- Check that the MT8808 output goes to a **keyboard encoder's matrix inputs**,
  not to a VIA. Wired straight to a VIA the card is silent — nothing scans the
  matrix. See the note in [Overview](#overview).
- Verify the encoder's matrix side is enabled (`CB2` low on the KEH)

### Incorrect Key Mapping
- Verify scan code mapping in `ps2ToMatrix()` function
- Check physical matrix wiring to the encoder's PORT A / PORT B
- Use serial debugging to monitor received scan codes

### Build Errors
- Ensure CircularBuffer library is installed
- Verify PlatformIO platform and framework are up to date
- Check that all required tools are in PATH

## Technical Details

### Timing Specifications

- **PS/2 Clock Frequency**: 10-16.7 kHz (typical)
- **PS/2 Timeout**: 250ms between clock pulses
- **Matrix Write Delay**: 1ms per signal transition
- **Total Key Event Time**: ~3ms per key press/release

### Memory Usage

- **Flash**: ~4KB (program memory)
- **SRAM**: ~200 bytes (including buffer)
- **EEPROM**: Not used

### Interrupt Safety

The firmware uses `CIRCULAR_BUFFER_INT_SAFE` to ensure thread-safe buffer operations between the interrupt handler and main loop.

## License

See the LICENSE file in the project root for licensing information.

## Author

A.C. Wright

## Version History

- **1.0.0**: Initial release with PS/2 to matrix translation

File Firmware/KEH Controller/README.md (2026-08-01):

# KEH Controller

## Overview

The KEH (Keyboard Encoder Helper) Controller is firmware for the ATMega1284P microcontroller that provides dual keyboard input support for 6502-based computer systems. It can simultaneously handle both PS/2 keyboard input and custom keyboard matrix input, converting keypresses to ASCII codes and outputting them through a 6522 VIA (Versatile Interface Adapter) interface.

## Features

- **Dual Input Support**: Handles both PS/2 keyboards and 8x8 keyboard matrix simultaneously
- **ASCII Conversion**: Converts PS/2 scancodes and matrix keypresses to ASCII characters
- **Always Uppercase Letters**: Letters are always output as uppercase ASCII regardless of modifiers
- **Modifier Keys**: Shift (symbols/numbers only) and Ctrl (control codes)
- **Buffered Input**: Uses circular buffers to prevent data loss during rapid typing
- **Debounced Matrix Scanning**: Hardware debouncing for reliable matrix keyboard operation
- **Enable/Disable Control**: Independent enable signals for PS/2 and matrix inputs
- **Shared Joystick Ports**: Releases PORT A / PORT B when disabled so the 6502 can read the two Atari 2600-compatible joysticks that share those ports

## Hardware Connections

### ATMega1284P Pin Assignments

#### VIA PORT A (Pins 24-31)
Used for row scanning (matrix mode) or ASCII output (PS/2 mode):
- PA0 (Pin 24) - VIA_PA0 / Row 0 / Data Bit 0
- PA1 (Pin 25) - VIA_PA1 / Row 1 / Data Bit 1
- PA2 (Pin 26) - VIA_PA2 / Row 2 / Data Bit 2
- PA3 (Pin 27) - VIA_PA3 / Row 3 / Data Bit 3
- PA4 (Pin 28) - VIA_PA4 / Row 4 / Data Bit 4
- PA5 (Pin 29) - VIA_PA5 / Row 5 / Data Bit 5
- PA6 (Pin 30) - VIA_PA6 / Row 6 / Data Bit 6
- PA7 (Pin 31) - VIA_PA7 / Row 7 / Data Bit 7

#### VIA PORT B (Pins 0-7)
Used for column scanning (matrix mode) or ASCII output (matrix output):
- PB0 (Pin 0) - VIA_PB0 / Column 0 / Data Bit 0
- PB1 (Pin 1) - VIA_PB1 / Column 1 / Data Bit 1
- PB2 (Pin 2) - VIA_PB2 / Column 2 / Data Bit 2
- PB3 (Pin 3) - VIA_PB3 / Column 3 / Data Bit 3
- PB4 (Pin 4) - VIA_PB4 / Column 4 / Data Bit 4
- PB5 (Pin 5) - VIA_PB5 / Column 5 / Data Bit 5
- PB6 (Pin 6) - VIA_PB6 / Column 6 / Data Bit 6
- PB7 (Pin 7) - VIA_PB7 / Column 7 / Data Bit 7

#### Control Signals
- Pin 8 (VIA_CA1) - PS/2 Data Ready strobe (output)
- Pin 9 (VIA_CA2) - PS/2 Enable (input, active low)
- Pin 10 (PS2CLK) - PS/2 Clock input
- Pin 11 (PS2DATA) - PS/2 Data input
- Pin 12 (VIA_CB1) - Matrix Data Ready strobe (output)
- Pin 13 (VIA_CB2) - Matrix Enable (input, active low)

### PS/2 Keyboard Interface

Connect a PS/2 keyboard to:
- **CLK**: Pin 10 (PS2CLK)
- **DATA**: Pin 11 (PS2DATA)
- **VCC**: +5V
- **GND**: Ground

### Keyboard Matrix Interface

The firmware supports an 8x8 keyboard matrix (64 keys maximum):
- **Rows**: Connected to PA0-PA7 (Pins 24-31)
- **Columns**: Connected to PB0-PB7 (Pins 0-7)

Each key connects a row to a column when pressed. The matrix is scanned with rows driven low and columns read with pull-ups.

### Joystick Interface

PORT A and PORT B are shared between this encoder and two Atari 2600-compatible
joysticks. The Keyboard Encoder Helper has no DB-9 connectors of its own — the
sticks arrive on the same 2×6 box headers that carry the VIA ports (`J1` PORT B,
`J2` PORT A), or across the `J4` DB-25 keyboard cable. Three helper boards reach
those lines:

- **Keyboard Helper** — the usual path. Its `J7` DB-25 takes the whole keyboard
  cable from KEH's `J4`, and the two DB-9s it carries (`J1` JOYSTICK A, `J2`
  JOYSTICK B) are those same port lines brought back out, with the 1kΩ pull-ups
  (`R1`–`R16`) fitted. Its `J3`/`J4` 2×6 headers are the same two sticks again.
- **Joystick Helper** — converts a single port header to a DB-9 with the 1kΩ
  pull-ups fitted, which is where Atari 2600 compatibility comes from.
- **GPIO Helper** — not a stick, but its `J1` PORT A side is eight push buttons
  to ground behind 1kΩ pull-ups, so it stands in for one electrically while
  testing.

The BIOS reads the two sticks through those same ports:

| BIOS routine | BASIC | VIA port | KEH header | Encoder released by |
|---|---|---|---|---|
| `ReadJoystick1` (`$A048`) | `JOY(1)` | PORT B | `J1` | `CB2` high — matrix encoder off |
| `ReadJoystick2` (`$A04B`) | `JOY(2)` | PORT A | `J2` | `CA2` high — PS/2 encoder off |

> Note the naming trap: the Keyboard Helper's *JOYSTICK A* connector is PORT A,
> which is `JOY(2)`, and *JOYSTICK B* is PORT B, which is `JOY(1)`.

Each read returns the port raw, as a bitmask:

```
Bit:  7   6   5   4   3   2   1   0
      R   L   D   U   Y   X   B   A
```

The ports are **active low** — every line is pulled high and grounded by the
stick's switch — so a held button reads `0` and an untouched stick reads `$FF`.

This is the firmware's obligation in the joystick path: when `CA2` or `CB2`
goes high, it releases the corresponding port within 100 µs so the 6502 can
read the stick directly — the same arrangement a C64 has with a CIA port.
`disablePS2()` releases PORT A and `disableMatrix()` releases PORT B, both by
returning the pins to `INPUT_PULLUP` rather than bare `INPUT`. That matters
here in particular, since a KEH port can legitimately have no external
pull-ups fitted at all — see the helper board list above.

The BIOS reads a stick as `KBDisable` → settle → read the port directly →
`KBEnable`. Nothing is transmitted over the shared lines, so there is nothing
for one stick to corrupt on the other's behalf — **both sticks read correctly
even when held at the same time.** An earlier design had the encoder push
joystick state to the 6502 as control bytes over the keyboard channel instead;
that could not report a held button on the port it was reporting over, and was
abandoned. See
[BIOS `PLAN.md` §2](https://github.com/acwright/6502-BIOS/blob/main/PLAN.md)
for the full account.

**Measured release latency: to be measured later.** This is the figure the
BIOS's `KBDisable` settle wait is sized against. Cycle-counting the compiled
firmware puts the worst-case code path at ~17 µs against a 100 µs budget, but
that excludes a PS/2 interrupt landing in the window and says nothing about how
long the bus takes to charge through a pull-up, so the published number comes
from a scope. See [PLAN.md](../../PLAN.md).

## Keyboard Matrix Layout

```
       PB0    PB1    PB2    PB3    PB4    PB5    PB6    PB7
PA0:    `      1      2      3      4      5      6      7
PA1:    8      9      0      -      =      BS     ESC    TAB
PA2:    Q      W      E      R      T      Y      U      I
PA3:    O      P      [      ]      \      INS    CAPS   A
PA4:    S      D      F      G      H      J      K      L
PA5:    ;      '    ENTER   DEL   SHIFT    Z      X      C
PA6:    V      B      N      M      ,      .      /      UP
PA7:  CTRL   MENU    ALT   SPACE   FN    LEFT   DOWN  RIGHT
```

**Special Keys:**
- BS = Backspace (0x08)
- ESC = Escape (0x1B)
- TAB = Tab (0x09)
- INS = Insert (0x1A)
- DEL = Delete (0x7F)
- ENTER = Enter (0x0D)
- Arrow keys: UP (0x1E), LEFT (0x1C), DOWN (0x1F), RIGHT (0x1D)

**Ignored Keys:**
- Caps Lock, Menu/GUI, Alt, Fn — produce no output and track no state

## Operation Modes

### PS/2 Mode
When VIA_CA2 (Pin 9) is pulled LOW:
- PS/2 keyboard is enabled
- Scancodes are converted to ASCII
- Output appears on PORT A (PA0-PA7)
- VIA_CA1 pulses low when data is ready

### Matrix Mode
When VIA_CB2 (Pin 13) is pulled LOW:
- Matrix keyboard is enabled
- Matrix is scanned every 10ms
- Keys are debounced (stable for 2 scans)
- Output appears on PORT B (PB0-PB7)
- VIA_CB1 pulses low when data is ready

### Dual Mode
Both keyboards can operate simultaneously if both enable signals are active.

### Joystick Reads
When an enable signal goes HIGH the firmware releases that port so the joystick
sharing it can be read by the 6502 — see [Joystick Interface](#joystick-interface).

## ASCII Character Mapping

### Modifier Priority

1. **Ctrl** — If held, produce control code. Shift is ignored.
2. **Shift** — If held (no Ctrl), produce shifted symbol. Letters unaffected.
3. **Base** — No modifier: produce base ASCII (letters always uppercase).

### Control Characters (Ctrl+Key)

- Ctrl+2 = 0x00 (NUL)
- Ctrl+A-Z = 0x01-0x1A
- Ctrl+[ = 0x1B (ESC)
- Ctrl+\ = 0x1C (FS)
- Ctrl+] = 0x1D (GS)
- Ctrl+6 = 0x1E (RS)
- Ctrl+- = 0x1F (US)

### Shifted Symbols

Shift only affects number and symbol keys (not letters):

| Base | Shifted | | Base | Shifted |
|---|---|-|---|---|
| 1 → ! | 2 → @ | | 3 → # | 4 → $ |
| 5 → % | 6 → ^ | | 7 → & | 8 → * |
| 9 → ( | 0 → ) | | - → _ | = → + |
| [ → { | ] → } | | \ → \| | ; → : |
| ' → " | , → < | | . → > | / → ? |
| ` → ~ | | | | |

### Printable Characters

Letters are always uppercase (A-Z). Numbers, symbols, space, and navigation keys follow standard ASCII.

## Build Instructions

### Prerequisites

1. **Install PlatformIO**
   ```bash
   # Using pip
   pip install platformio
   
   # Or install PlatformIO IDE extension for VS Code
   ```

2. **Install MiniPro Programmer Software** (for uploading)
   ```bash
   # macOS (using Homebrew)
   brew install minipro
   
   # Linux
   sudo apt-get install minipro
   
   # Or build from source: https://gitlab.com/DavidGriffith/minipro
   ```

### Building the Firmware

1. **Navigate to the project directory:**
   ```bash
   cd "Firmware/KEH Controller"
   ```

2. **Build the firmware:**
   ```bash
   # Build for ATMega1284P (default)
   pio run -e atmega1284p
   
   # Or build for ATMega1284
   pio run -e atmega1284
   ```

3. **Build output:**
   The compiled firmware will be located at:
   ```
   .pio/build/atmega1284p/firmware.hex
   ```

### Uploading the Firmware

The project uses a MiniPro TL866 programmer for uploading.

1. **Connect the MiniPro programmer** to your ATMega1284P chip

2. **Upload firmware and fuses:**
   ```bash
   # Upload to ATMega1284P
   pio run -e atmega1284p -t upload
   
   # Or upload to ATMega1284
   pio run -e atmega1284 -t upload
   ```

3. **Manual upload (if needed):**
   ```bash
   # Flash the program
   minipro -p "ATMEGA1284P@DIP40" -c code -w .pio/build/atmega1284p/firmware.hex
   
   # Flash the fuses
   minipro -p "ATMEGA1284P@DIP40" -c config -w fuses.cfg --fuses
   ```

## Fuse Configuration

The `fuses.cfg` file contains the ATMega1284P fuse settings:

```properties
lfuse = 0xff   # Low fuse
hfuse = 0xff   # High fuse  
efuse = 0xff   # Extended fuse
lock = 0xff    # Lock bits (unprogrammed, not written)
```

**Fuse Settings:**
- **Low Fuse (0xFF)**: Low power crystal oscillator (8.0–16.0 MHz) for the
  on-board 16 MHz crystal (`Y1`), slowly-rising-power start-up (16K CK + 65 ms),
  no clock divide (CKDIV8 off), clock output disabled
- **High Fuse (0xFF)**: Default settings
- **Extended Fuse (0xFF)**: Default settings
- **Lock Bits (0xFF)**: No memory lock protection

> **Note**: The low fuse selects a *crystal* oscillator, which is what this board
> needs — the Keyboard Encoder Helper carries a 16 MHz HC49-U crystal across
> XTAL1/XTAL2. Full Swing is a different setting (`CKSEL3:1 = 011`) and is not
> used here. The ACE board's `AB Controller` runs from a full-can oscillator
> module instead and therefore uses the *external clock* setting
> (`lfuse = 0xE0`); the two are not interchangeable.

> **Note**: Lock bits are left unprogrammed on all of these boards. The upload
> command writes fuses only (`--fuses`, no `--lock`), so the `lock` line above is
> recorded for reference and never programmed.

⚠️ **Warning**: Incorrect fuse settings can brick your microcontroller. Verify fuse values are appropriate for your hardware configuration before programming.

## Dependencies

The firmware requires the following library (automatically installed by PlatformIO):

- **CircularBuffer** (v1.4.0+) by Roberto Lo Giacco
  - Provides interrupt-safe circular buffers for keyboard data

## Project Structure

```
KEH Controller/
├── platformio.ini          # PlatformIO configuration
├── fuses.cfg              # AVR fuse configuration
├── src/
│   └── main.cpp           # Main firmware source code
├── include/               # Header files (if any)
├── lib/                   # Local libraries
└── test/                  # Unit tests
```

## Troubleshooting

### Build Issues

**Problem**: PlatformIO not found
```bash
# Solution: Install or update PlatformIO
pip install -U platformio
```

**Problem**: Library dependency errors
```bash
# Solution: Clean and rebuild
pio run -t clean
pio run
```

### Upload Issues

**Problem**: MiniPro not found
```bash
# Solution: Ensure minipro is installed and in PATH
which minipro
```

**Problem**: Chip not detected
- Check that the chip is properly seated in the programmer
- Verify you're using the correct chip model (ATMEGA1284P vs ATMEGA1284)
- Check for proper power supply to the programmer

### Runtime Issues

**Problem**: No keyboard response
- Verify enable signals (CA2/CB2) are at correct logic levels
- Check PS/2 clock and data connections
- Verify matrix keyboard connections
- Ensure VIA interface connections are correct

**Problem**: `JOY(1)`/`JOY(2)` return keystrokes or a stuck value
- Confirm the BIOS is v1.5 or later — older BIOS reads the port before the
  encoder has released it (see [Joystick Interface](#joystick-interface))
- Verify the stick's pull-ups are present (the Keyboard Helper and Joystick
  Helper carry them; a bare box-header connection does not)

**Problem**: Incorrect characters output
- Check for proper pull-up resistors on PS/2 lines
- Verify keyboard matrix wiring matches the defined layout
- Test with a known-good PS/2 keyboard

## License

See the main repository LICENSE file for licensing information.

## Contributing

This firmware is part of the 6502 computer project. Contributions and improvements are welcome through the main repository.

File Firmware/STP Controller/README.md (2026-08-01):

# STP Controller

An SPI Controller Peripheral for 6502-based computer systems. This firmware runs on an ATmega328P microcontroller and acts as a memory-mapped I/O device, providing the 6502 CPU with access to SPI peripherals including SD cards, Flash memory, and external SPI devices.

> ⚠️ **Experimental — the stock BIOS cannot see this card.** It is not part of
> the default I/O set the BIOS probes for, and no COB machine is built around it
> today.
>
> The BIOS's storage slot is IO 4 at `$8C00–$8C07`: eight registers of 8-bit True
> IDE CompactFlash — data, error/feature, sector count, four LBA bytes, and
> status/command. The boot probe checks BSY/RDY and issues Set Features (`$EF`).
> This card presents two registers instead (`DATA` at offset 0, `CTRL` at offset
> 1), so it answers nothing that probe expects: `HW_CF` stays clear and every
> storage path reports `NO DEVICE` (BASIC) or `I/O ERROR` (Monitor).
>
> Using it needs an SPI/SD driver that does not exist in the
> [BIOS](https://github.com/acwright/6502-BIOS) today — either a modified BIOS or
> software that drives the two registers directly.

## Features

- **Memory-Mapped I/O Interface**: Two registers accessible from 6502 address space (DATA and CTRL)
- **Multiple SPI Devices**: Support for up to 3 SPI slave devices via chip select lines
  - CS0: SD Card
  - CS1: Flash Memory
  - CS2: External SPI Header
- **Dual Clock Speeds**: 
  - Fast mode: 4 MHz (normal operation)
  - Slow mode: 400 kHz (SD card initialization)
- **Auto-Transmit Mode**: Automatically send dummy bytes when reading data, useful for consecutive reads
- **Status Monitoring**: Real-time monitoring of BUSY, Card Detect (CD), and Write Protect (WP) flags
- **6502 Synchronization**: PHI2-synchronized interrupt-driven interface for reliable communication

## Hardware Overview

### Microcontroller
- **MCU**: ATmega328P @ DIP28 package
- **Architecture**: AVR 8-bit
- **Framework**: Arduino

### Pin Connections

| Pin Group | ATmega328P Pins | Function |
|---|---|---|
| **6502 Data Bus** | PD0-PD7 (D0-D7) | Bidirectional 8-bit data bus |
| **6502 Control** | A0 (RS0) | Register select (0=DATA, 1=CTRL) |
| | A1 (PHI2) | 6502 clock - triggers interrupt |
| | A2 (CSB) | Chip select (active low) |
| | A3 (RWB) | Read/Write signal |
| **SD Card Status** | A4 (CD) | Card detect input (active low) |
| | A5 (WP) | Write protect input (active low) |
| **SPI Interface** | 11 (MOSI) | SPI Master Out Slave In |
| | 12 (MISO) | SPI Master In Slave Out |
| | 13 (SCK) | SPI Clock |
| **Chip Selects** | 8 (CS0) | SD Card chip select |
| | 9 (CS1) | Flash Memory chip select |
| | 10 (CS2) | External SPI header chip select |

## Register Map

The STP Controller presents two 8-bit registers to the 6502:

### DATA Register ($0)
**Address Offset**: 0  
**Access**: Read/Write

| Bit 7-0 | Description |
|---|---|
| DATA[7:0] | SPI data byte to transmit or last received byte |

**Write Operation**: Initiates an SPI transfer with the written byte  
**Read Operation**: Returns the last received SPI byte. If AUTO-TX is enabled, automatically starts a new transfer with dummy byte $FF

### CTRL Register ($1)
**Address Offset**: 1  
**Access**: Read/Write (some bits read-only)

| Bit | Name | R/W | Description |
|-----|---|-----|---|
| 7 | BUSY | R | SPI transfer in progress (1=busy, 0=idle) |
| 6 | CD | R | SD Card detected (1=card present, 0=no card) |
| 5 | WP | R | Write protect status (1=protected, 0=writable) |
| 4 | SS1 | R/W | Slave select bit 1 |
| 3 | SS0 | R/W | Slave select bit 0 |
| 2 | AUTO-TX | R/W | Auto-transmit on read (1=enabled, 0=disabled) |
| 1 | SLOW CLK | R/W | SPI clock speed (1=400kHz, 0=4MHz) |
| 0 | SELECT | R/W | Enable chip select (1=active, 0=inactive) |

**Slave Select Encoding** (SS1:SS0):
- `00`: CS0 - SD Card
- `01`: CS1 - Flash Memory
- `10`: CS2 - External SPI Header
- `11`: Reserved (no device selected)

## Building the Firmware

### Prerequisites

1. **PlatformIO**: Install PlatformIO Core or PlatformIO IDE
   ```bash
   # Via pip
   pip install platformio
   
   # Or via Homebrew (macOS)
   brew install platformio
   ```

2. **MiniPro Programmer**: Required for uploading firmware
   ```bash
   # macOS
   brew install minipro
   
   # Linux
   # Follow installation instructions at: https://gitlab.com/DavidGriffith/minipro
   ```

### Build Commands

```bash
# Build for ATmega328P (default)
pio run

# Build for ATmega328 (no 'P' variant)
pio run -e atmega328

# Clean build files
pio run --target clean

# Verbose build output
pio run -v
```

### Upload Firmware

The upload process programs both the firmware and fuse settings using a MiniPro programmer:

```bash
# Upload to ATmega328P
pio run --target upload

# Upload to ATmega328
pio run -e atmega328 --target upload
```

The upload command performs two operations:
1. Programs the compiled firmware to flash memory
2. Configures fuse bits from `fuses.cfg`

### Fuse Configuration

Fuse settings are defined in `fuses.cfg`:
```
lfuse = 0xFF  # Low power crystal oscillator 8.0-16.0 MHz, max startup time
hfuse = 0xFF  # High fuse
efuse = 0xFF  # Extended fuse
lock = 0xFF   # Lock bits (unprogrammed, not written)
```

**Note**: Lock bits are left unprogrammed on all of these boards. The upload
command writes fuses only (`--fuses`, no `--lock`), so the `lock` line above is
recorded for reference and never programmed.

**Note**: Verify fuse values match your hardware configuration before uploading. Incorrect fuse settings can brick your microcontroller.

## Usage Examples

### Example 1: Initialize SD Card

```assembly
; Set slow clock for SD card initialization
LDA #$03        ; SLOW_CLK=1, SELECT=1
STA CTRL        ; Enable CS0 (SD Card) with slow clock

; Send CMD0 (reset)
LDA #$40
JSR SPI_SEND
LDA #$00
JSR SPI_SEND
; ... (continue with initialization sequence)

; Switch to fast clock after initialization
LDA #$01        ; SLOW_CLK=0, SELECT=1
STA CTRL
```

### Example 2: Read Multiple Bytes with Auto-Transmit

```assembly
; Enable auto-transmit for faster consecutive reads
LDA #$05        ; AUTO_TX=1, SELECT=1
STA CTRL        ; CS0 active with auto-transmit

; First byte (manual trigger)
LDA #$FF
STA DATA        ; Start transfer

:WAIT1
LDA CTRL
AND #$80        ; Check BUSY flag
BNE :WAIT1

; Subsequent bytes (auto-triggered on read)
LDX #$00
:LOOP
LDA DATA        ; Reading DATA automatically sends next $FF
STA BUFFER,X    ; Store received byte
INX
CPX #$10        ; Read 16 bytes
BNE :LOOP

; Disable chip select
LDA #$00
STA CTRL
```

### Example 3: Select Flash Memory

```assembly
; Select Flash chip (CS1)
LDA #$09        ; SS1:SS0 = 01, SELECT=1
STA CTRL        ; Enable CS1 (Flash)

; Send command
LDA #$03        ; READ command
JSR SPI_SEND
; ... (continue with flash operations)
```

## Development Environment

This project is configured for development with:
- **Platform**: Atmel AVR
- **Framework**: Arduino
- **Board**: ATmega328P or ATmega328
- **Build System**: PlatformIO

## Project Structure

```
STP Controller/
├── src/
│   └── main.cpp          # Main firmware source
├── include/              # Header files (if any)
├── lib/                  # Project libraries
├── test/                 # Unit tests
├── platformio.ini        # PlatformIO configuration
├── fuses.cfg            # AVR fuse settings
├── SPI.txt              # SPI implementation notes
└── README.md            # This file
```

## Design Notes

The controller uses PHI2-synchronized interrupts to ensure proper timing with the 6502 bus. The data bus is configured as input with pull-ups by default and only switches to output mode when the 6502 performs a read operation.

SPI transfers are blocking and set the BUSY flag during operation. The 6502 software should check the BUSY flag before initiating new transfers.

The Card Detect (CD) and Write Protect (WP) inputs use internal pull-ups and are active-low, suitable for direct connection to SD card socket switches.

## References

- Inspired by the VERA SPI controller implementation (see `SPI.txt`)
- 6502 bus timing reference: [W65C02S Datasheet](http://www.westerndesigncenter.com/wdc/documentation/w65c02s.pdf)
- SD Card SPI Mode: [SD Specifications Part 1 Physical Layer Simplified Specification](https://www.sdcard.org/)

## License

See the main repository LICENSE file for details.

## Contributing

This is a personal project for a 6502-based computer system. Feel free to fork and adapt for your own hardware.

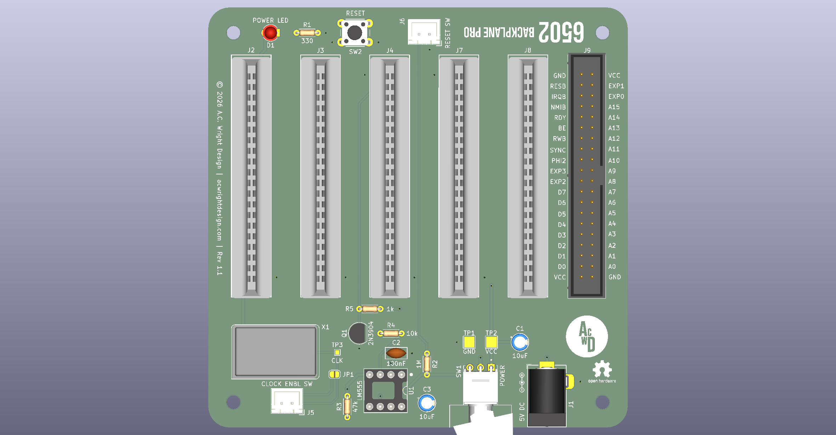
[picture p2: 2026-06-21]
CAD/Images/Backplane Pro/Rev 1.1/Front.png

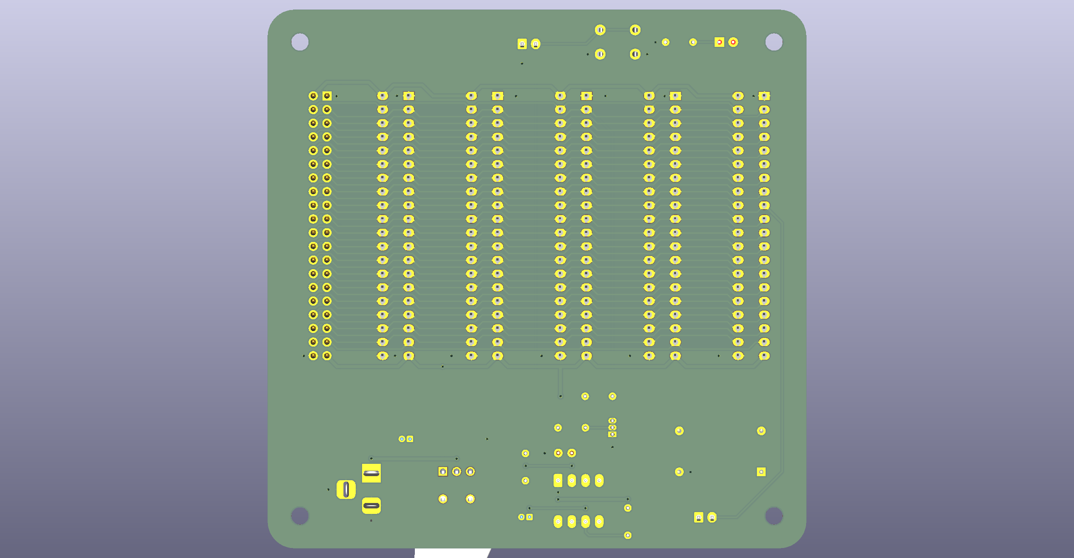
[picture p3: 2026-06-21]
CAD/Images/Backplane Pro/Rev 1.1/Back.png

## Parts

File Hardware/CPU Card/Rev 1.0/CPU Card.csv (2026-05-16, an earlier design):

Reference | Qty | Value | Description | Footprint | LCSC
C1 | 1 | 100nF | Unpolarized capacitor | Capacitor_SMD:C_0805_2012Metric | C49678
J2 | 1 | Conn_01x02 | Generic connector, single row, 01x02, script generated (kicad-library-utils/schlib/autogen/connector/) | Connector_PinHeader_2.54mm:PinHeader_1x02_P2.54mm_Vertical
J3 | 1 | EXP | Generic connector, double row, 02x05, odd/even pin numbering scheme (row 1 odd numbers, row 2 even numbers), script generated (kicad-library-utils/schlib/autogen/connector/) | Connector_PinHeader_2.54mm:PinHeader_2x05_P2.54mm_Vertical
R1,R2,R3,R4,R5,R6 | 6 | 1k | Resistor | Resistor_SMD:R_0805_2012Metric | C17513
U1 | 1 | 65C02 |  | Package_DIP:DIP-40_W15.24mm_Socket_LongPads

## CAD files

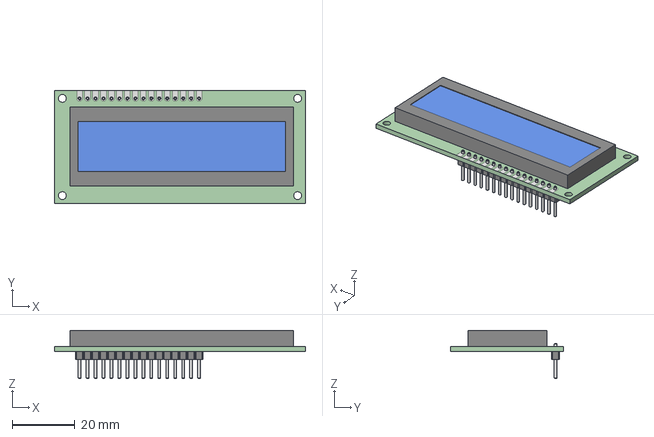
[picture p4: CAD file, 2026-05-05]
Models/LCD 16x2 HD44780 assembly.stp
80.0 x 36.0 x 15.3 mm
lcd 16_2 HD44780
dupont_pin_16

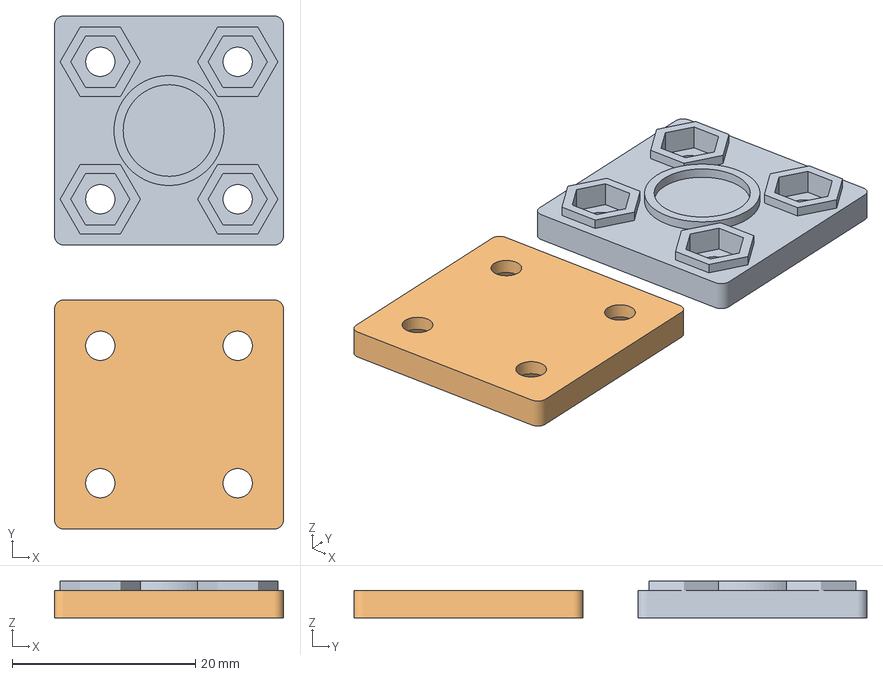
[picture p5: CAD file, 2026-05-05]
CAD/Bases/Center Support.3mf
25.0 x 56.0 x 4.00 mm
Center Support.stl
Center Support Retainer.stl

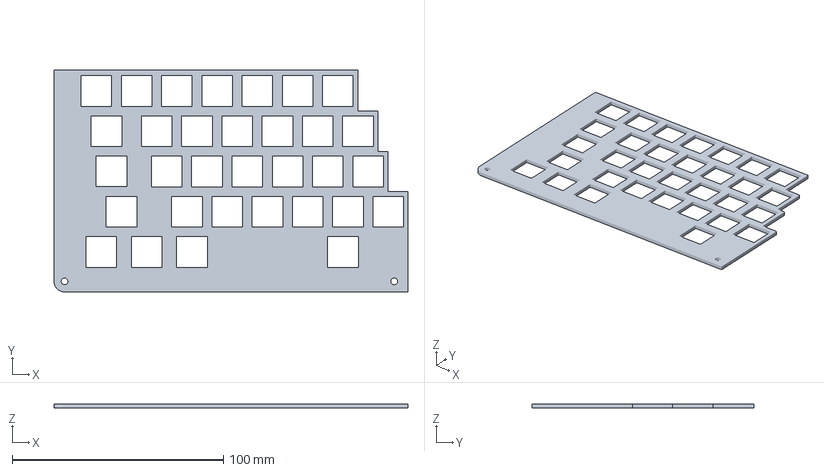
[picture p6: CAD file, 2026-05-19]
CAD/Jigs/Keyboard Helper Jig Left.3mf
167.5 x 105.0 x 2.00 mm

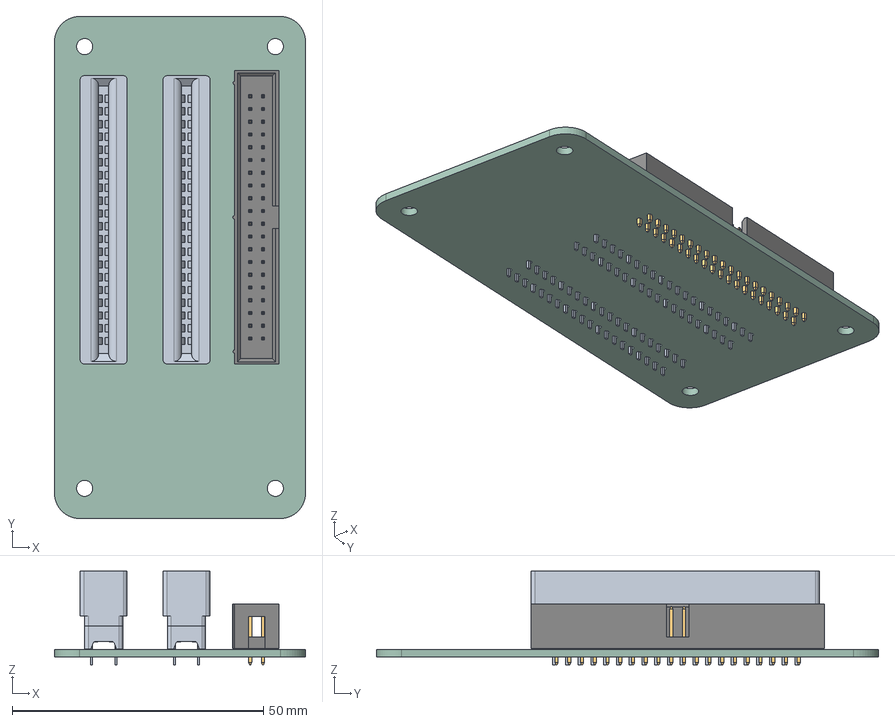
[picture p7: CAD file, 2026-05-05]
CAD/Models/Backplane Helper/Rev 1.0/Backplane Helper.step
50.0 x 100.0 x 18.7 mm
6120xx21621_PIN x 40
Backplane Helper_PCB

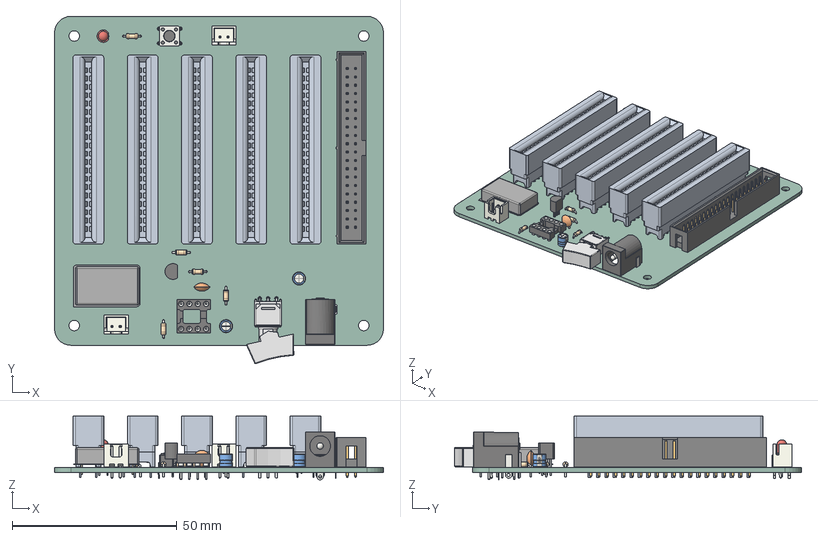
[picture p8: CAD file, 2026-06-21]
CAD/Models/Backplane Pro/Rev 1.1/Backplane Pro.step
100.0 x 105.6 x 19.4 mm
C-5-5530843-4 x 5
6120xx21621_PIN x 40
DIP_8_W762mm_Socket
JST_B2B_XH_A x 2
R_Axial_DIN0204_L36mm_D16mm_P508mm_Horizontal x 5
CP_Radial_D40mm_P150mm x 2
P:\E-Switch Secure\3D_MODELS_STP_FORMAT\400MSPxR6xxxM6xE.stp
LED_D3.0mm
TO-92_Inline_Narrow
BarrelJack_Horizontal
C_Disc_D50mm_W25mm_P250mm
SW_PUSH_6mm
Oscillator_DIP-14
Backplane Pro_PCB

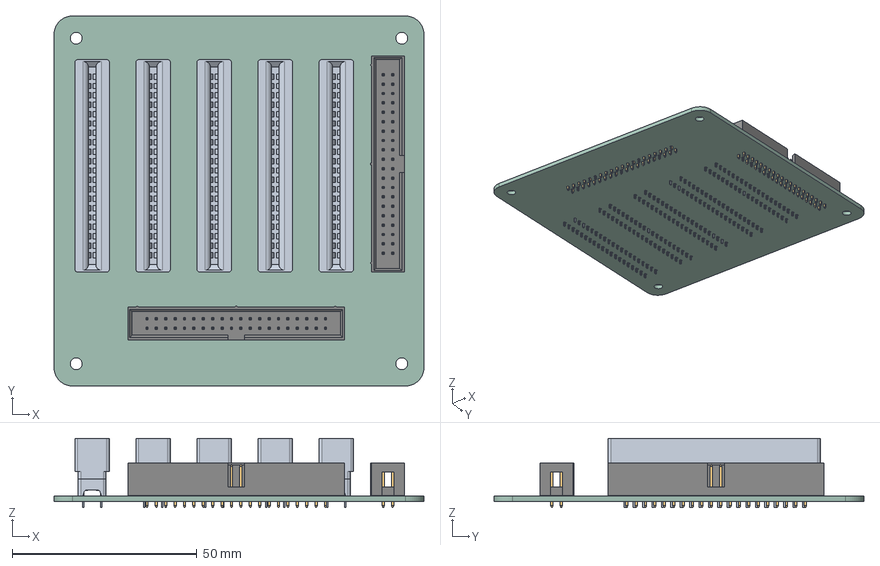
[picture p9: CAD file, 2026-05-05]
CAD/Models/Backplane/Rev 1.0/Backplane.step
100.0 x 100.0 x 18.7 mm
6120xx21621_PIN x 80
Backplane_PCB

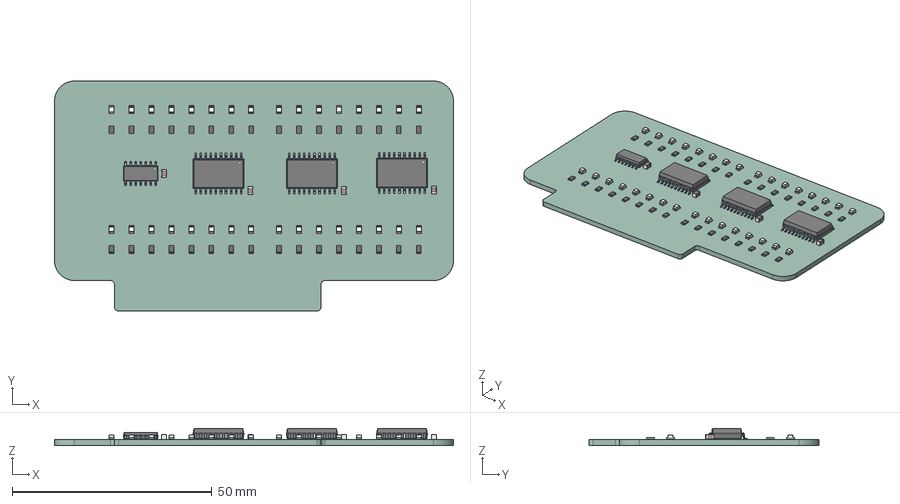
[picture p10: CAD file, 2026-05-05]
CAD/Models/Blinkenlights Card/Rev 1.0/Blinkenlights Card.step
100.0 x 57.6 x 4.34 mm
R_0805_2012Metric x 32
LED_0805_2012Metric x 32
C_0805_2012Metric x 4
SOIC-14_3.9x8.7mm_P1.27mm
SOIC-20W_7.5x12.8mm_P1.27mm x 3
Blinkenlights Card_PCB

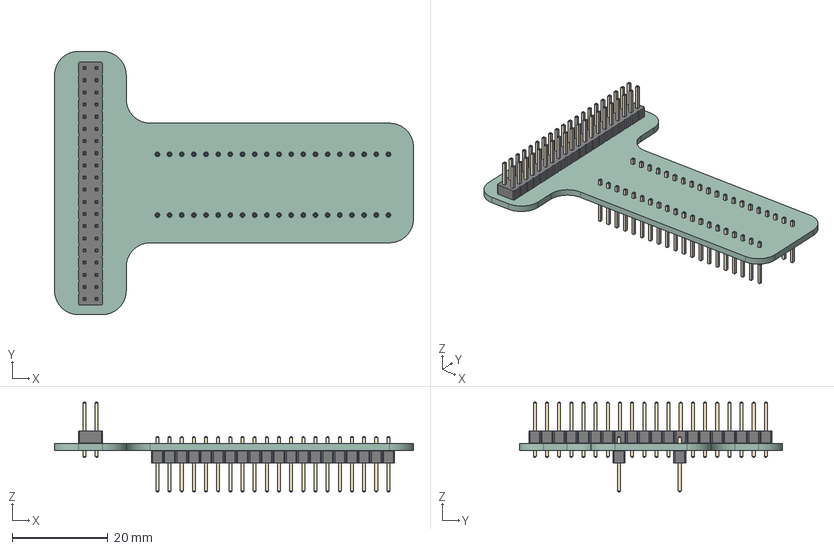
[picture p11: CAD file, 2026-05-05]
CAD/Models/Breadboard Helper/Rev 1.0/Breadboard Helper.step
75.0 x 55.0 x 18.8 mm
PinHeader_2x20_P2.54mm_Vertical
PinHeader_1x20_P2.54mm_Vertical x 2
Breadboard Helper_PCB

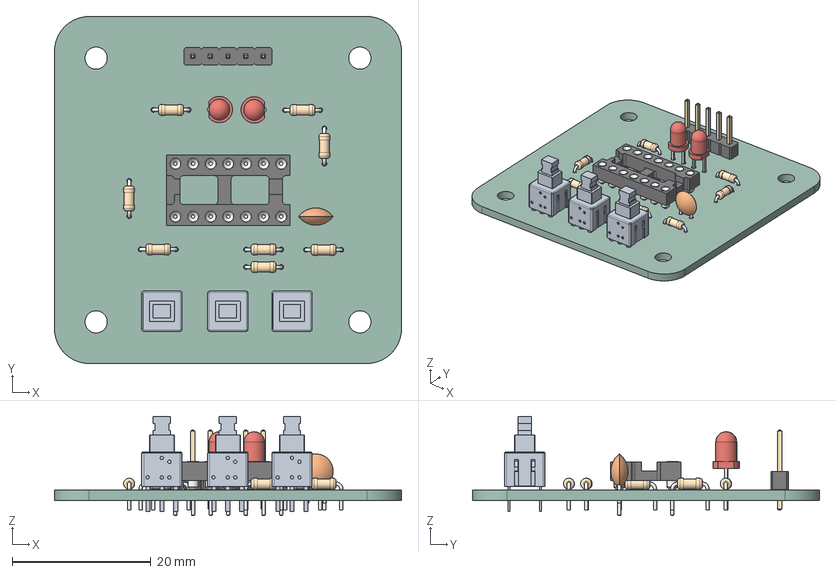
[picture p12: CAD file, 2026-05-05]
CAD/Models/Clock Helper/Rev 1.0/Clock Helper.step
50.0 x 50.0 x 14.3 mm
R_Axial_DIN0204_L3.6mm_D1.6mm_P5.08mm_Horizontal x 8
XKB5858 x 3
LED_D3.0mm x 2
C_Disc_D5.0mm_W2.5mm_P2.50mm
DIP-14_W7.62mm_Socket
PinHeader_1x05_P2.54mm_Vertical
Clock Helper_PCB

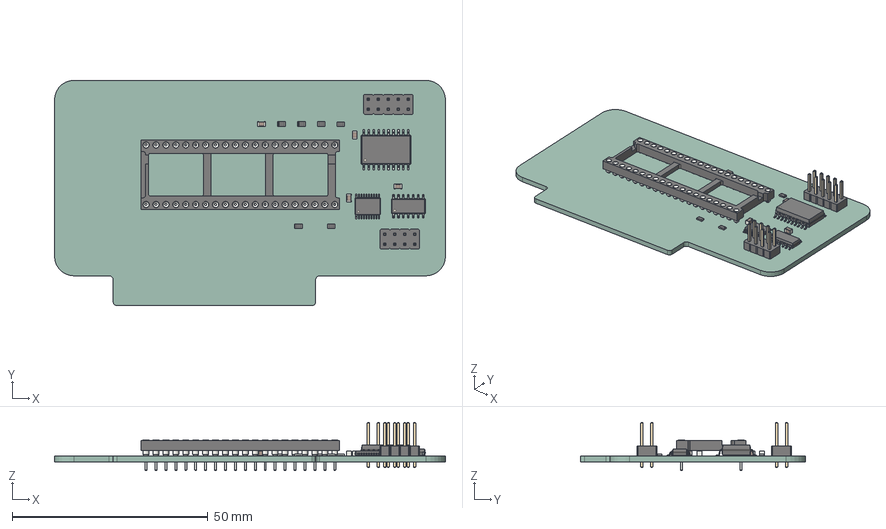
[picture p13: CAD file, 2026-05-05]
CAD/Models/CPU Card Pro/Rev 1.0/CPU Card Pro.step
100.0 x 57.6 x 12.3 mm
R_0805_2012Metric x 6
DIP-40_W15.24mm_Socket
C_0805_2012Metric x 4
SOIC-14_3.9x8.7mm_P1.27mm
PinHeader_2x05_P2.54mm_Vertical
SOIC-20W_7.5x12.8mm_P1.27mm
TSSOP-20_4.4x6.5mm_P0.65mm
PinHeader_2x04_P2.54mm_Vertical
CPU Card Pro_PCB

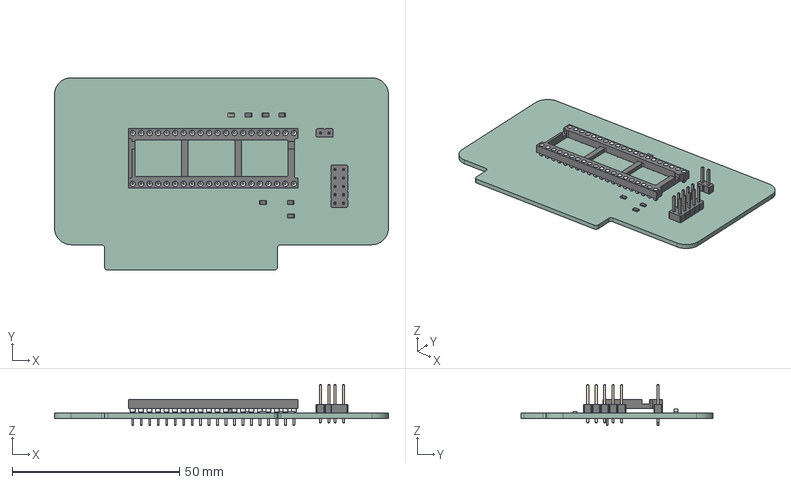
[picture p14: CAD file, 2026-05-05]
CAD/Models/CPU Card/Rev 1.1/CPU Card.step
100.0 x 57.6 x 12.3 mm
R_0805_2012Metric x 6
DIP-40_W15.24mm_Socket
C_0805_2012Metric
PinHeader_1x02_P2.54mm_Vertical
PinHeader_2x05_P2.54mm_Vertical
CPU Card_PCB

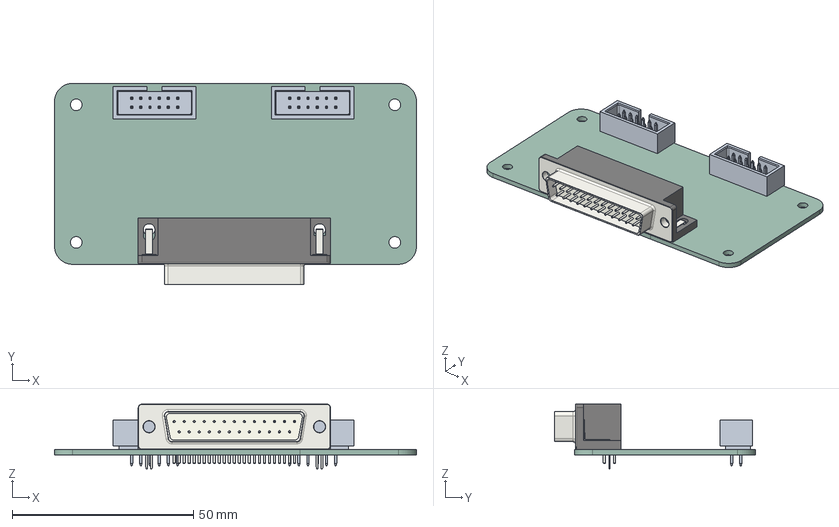
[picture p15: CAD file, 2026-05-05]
CAD/Models/DB25 Helper/Rev 1.0/DB25 Helper.step
100.0 x 55.6 x 17.9 mm
DSUB-25_Pins_Horizontal_P2.77x2.84mm_EdgePinOffset7.70mm_Housed_ MountingHolesOffset9.12mm
DB25 Helper_PCB

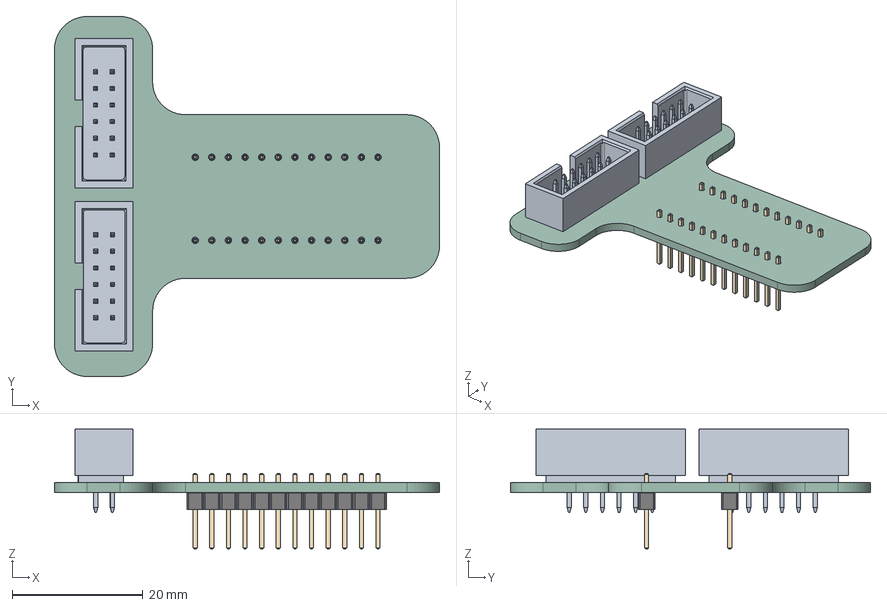
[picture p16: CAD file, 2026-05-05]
CAD/Models/GPIO Breadboard Helper/Rev 1.0/GPIO Breadboard Helper.step
58.8 x 55.0 x 18.3 mm
PinHeader_1x12_P2.54mm_Vertical x 2
GPIO Breadboard Helper_PCB

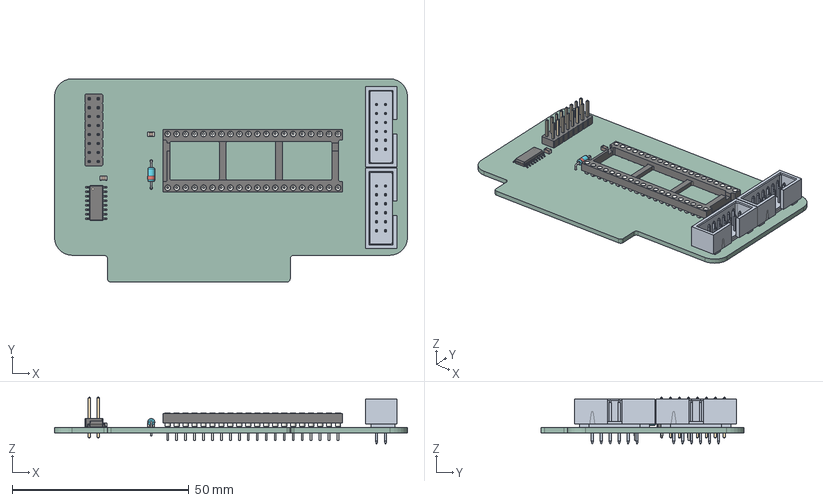
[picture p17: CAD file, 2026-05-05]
CAD/Models/GPIO Card/Rev 1.0/GPIO Card.step
100.0 x 57.6 x 13.2 mm
D_DO-35_SOD27_P7.62mm_Horizontal
SOIC-16_3.9x9.9mm_P1.27mm
DIP-40_W15.24mm_Socket
PinHeader_2x08_P2.54mm_Vertical
C_0805_2012Metric x 2
GPIO Card_PCB

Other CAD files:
CAD/Models/GPIO Helper/Rev 1.0/GPIO Helper.step
CAD/Models/Joystick Helper/Rev 1.0/Joystick Helper.step
CAD/Models/Keyboard Encoder Helper/Rev 1.0/Keyboard Encoder Helper.step
CAD/Models/Keyboard Helper/Rev 1.0/Keyboard Helper.step
CAD/Bases/Button.3mf
CAD/Bases/Button.stl
CAD/Bases/Center Support Retainer.stl
CAD/Bases/Center Support.stl
CAD/Bases/Corner.3mf
CAD/Bases/Corner.stl
CAD/Bases/Plate.stl
CAD/Jigs/Keyboard Helper Jig Left.stl
CAD/Jigs/Keyboard Helper Jig Right.3mf
CAD/Jigs/Keyboard Helper Jig Right.stl
CAD/Models/Backplane Pro/Rev 1.0/Backplane Pro.step
CAD/Models/LCD Board/Rev 1.0/LCD Board.step
CAD/Models/LCD Card/Rev 1.0/LCD Card.step
CAD/Models/Mega Helper/Rev 1.0/Mega Helper.step
CAD/Models/Memory Card/Rev 1.0/Memory Card.step
CAD/Models/PS2 Helper/Rev 1.0/PS2 Helper.step
CAD/Models/Prototype Card/Rev 1.0/Prototype Card.step
CAD/Models/RAM Card/Rev 1.0/RAM Card.step
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

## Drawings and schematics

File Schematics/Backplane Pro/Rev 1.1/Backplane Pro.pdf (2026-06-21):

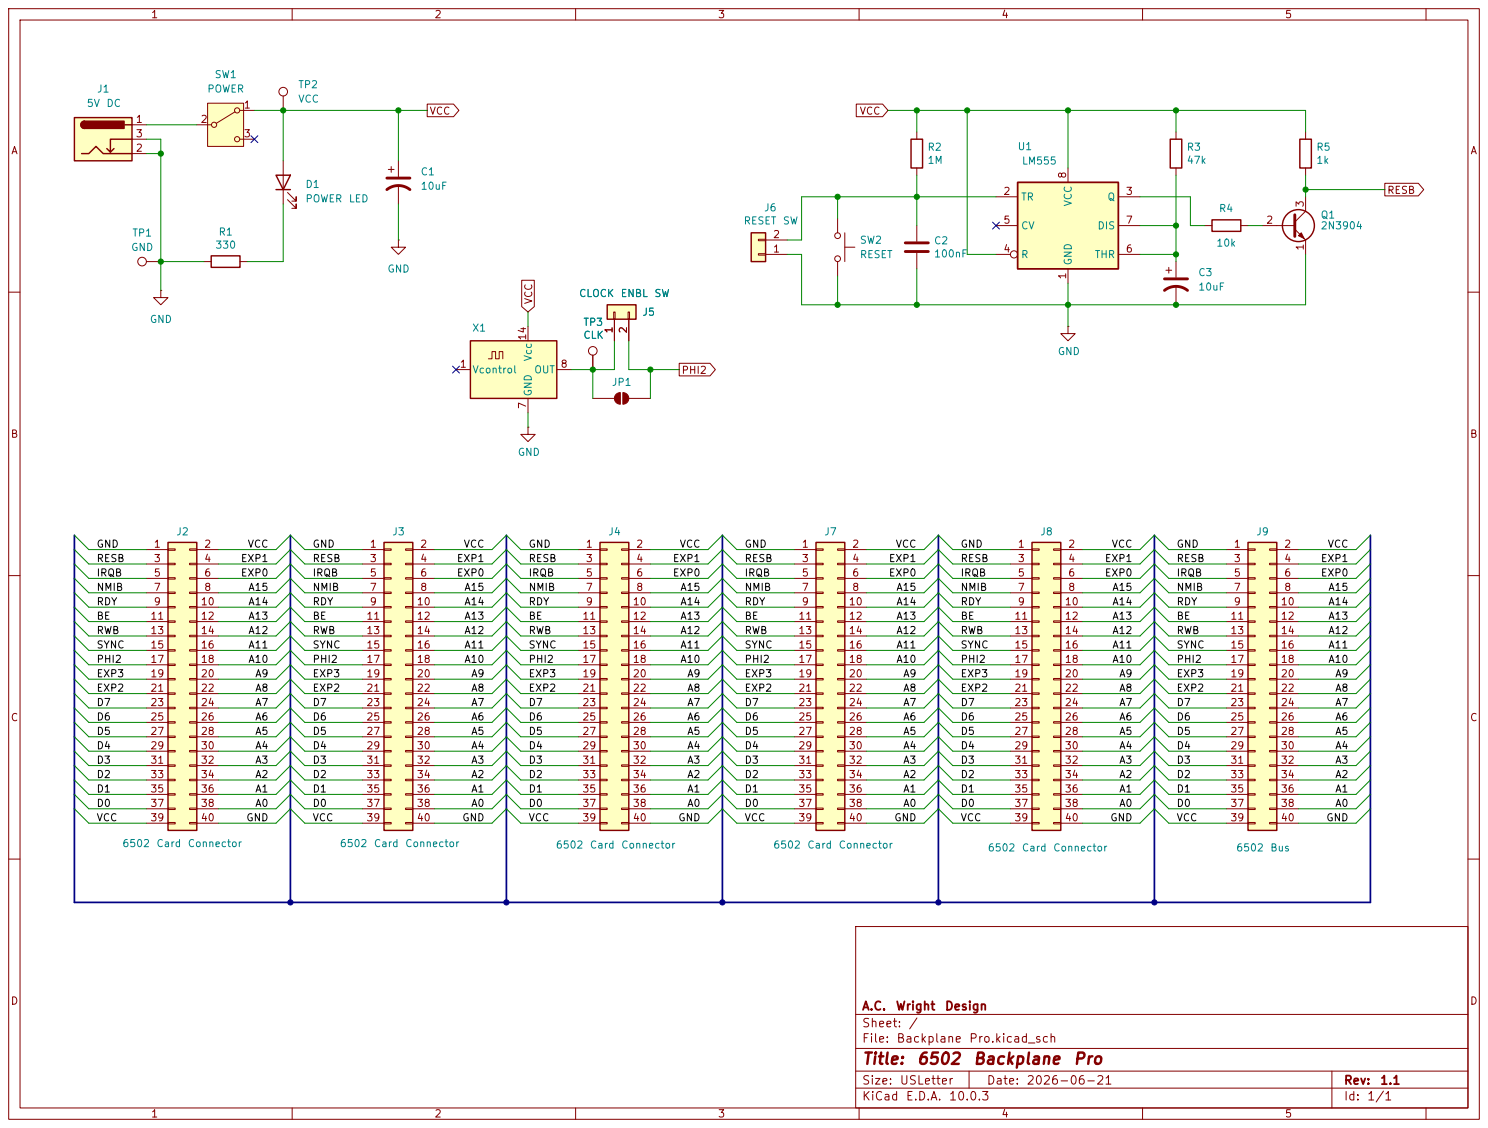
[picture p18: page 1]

Size: USLetter | Rev: 1.1
KiCad E.D.A. 10.0.3 | Id: 1/1

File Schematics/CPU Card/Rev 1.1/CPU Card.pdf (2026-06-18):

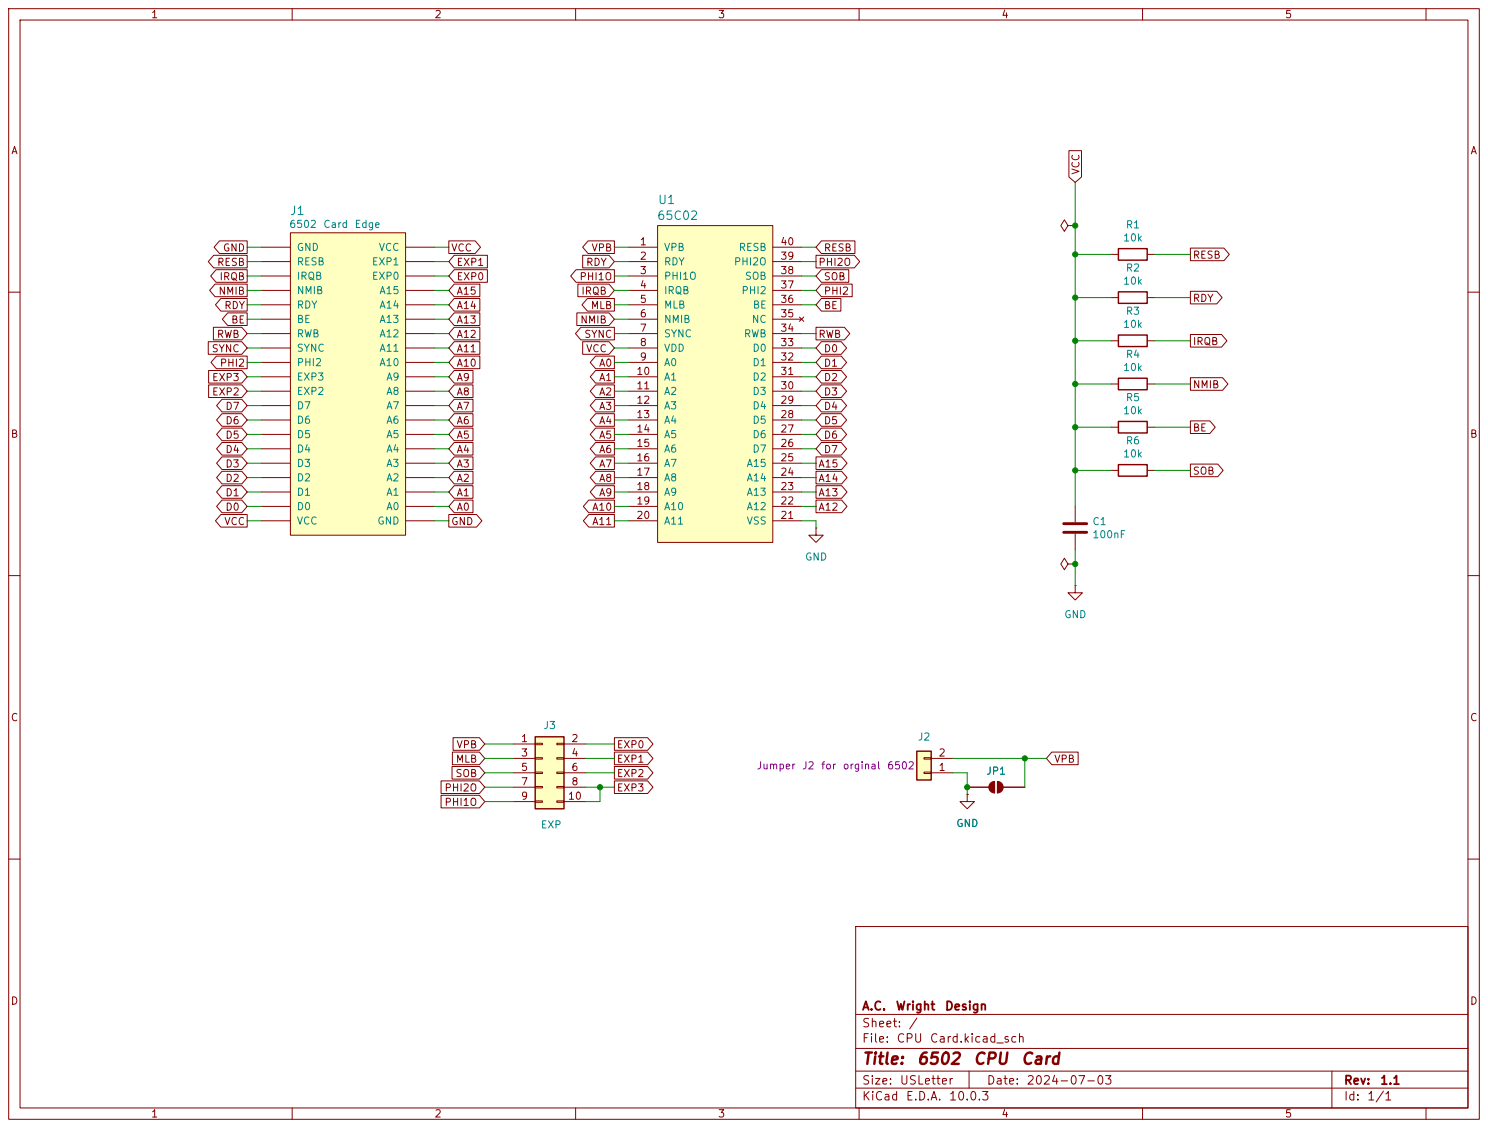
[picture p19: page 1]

Size: USLetter | Rev: 1.1
KiCad E.D.A. 10.0.3 | Id: 1/1

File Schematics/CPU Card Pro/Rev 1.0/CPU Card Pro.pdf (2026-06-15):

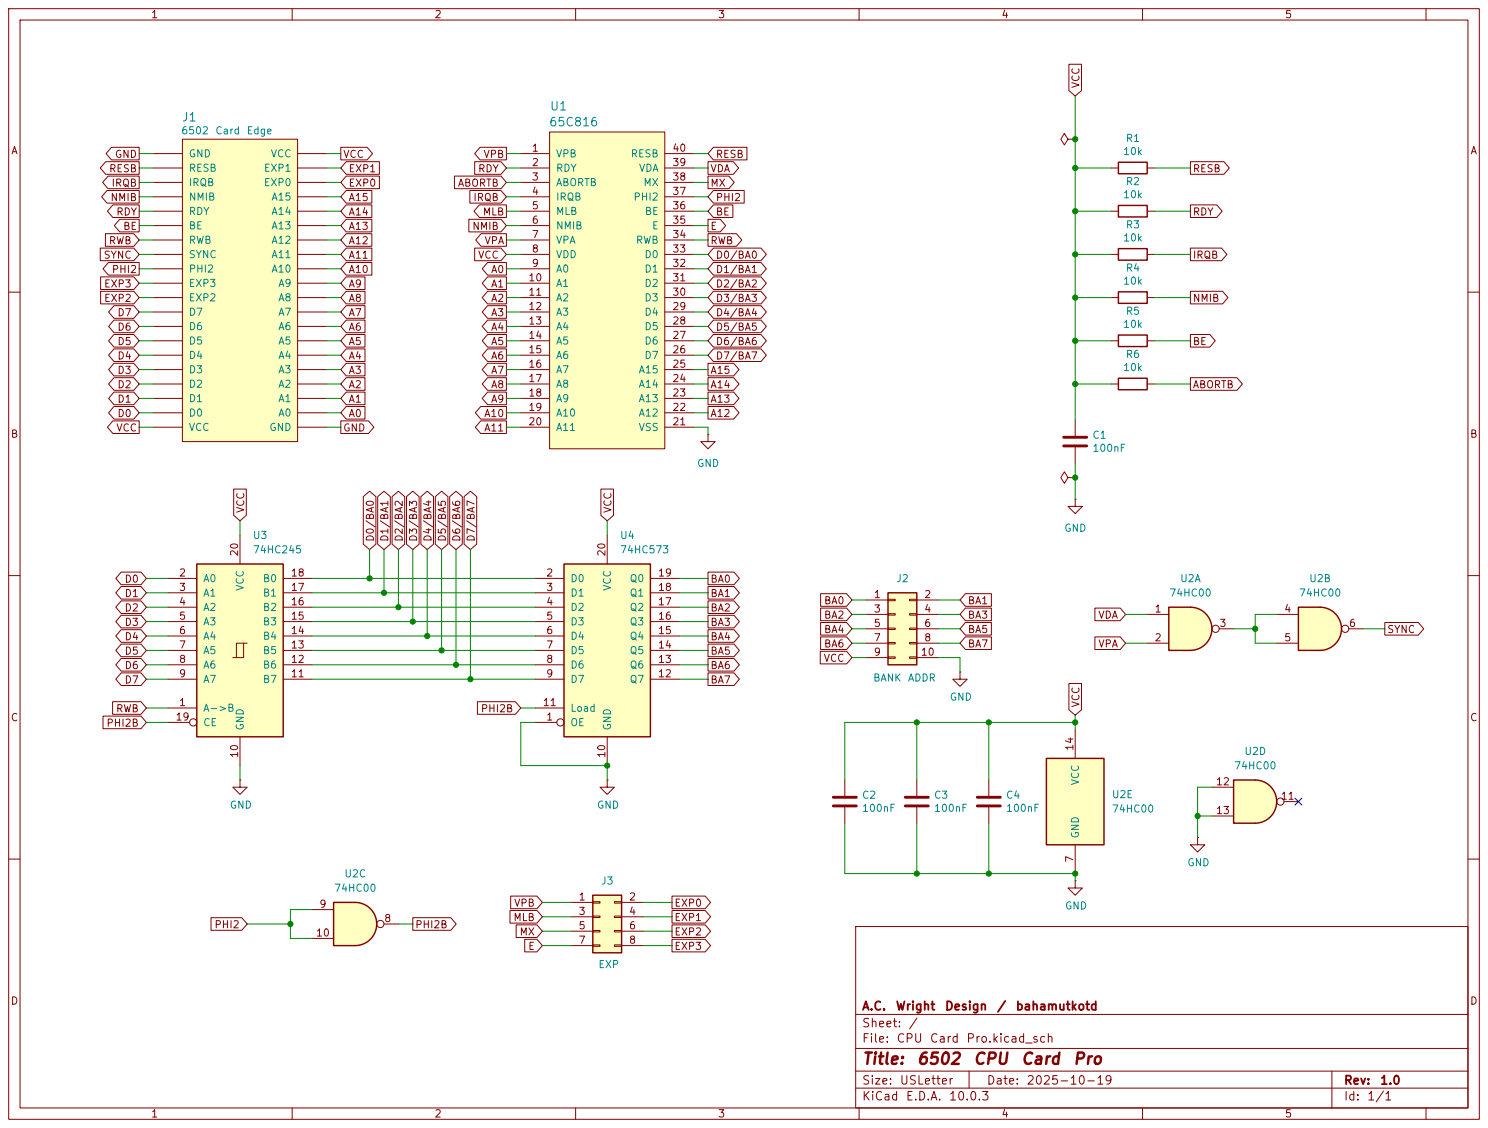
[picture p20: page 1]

A.C. Wright Design / bahamutkotd
Sheet: /
File: CPU Card Pro.kicad_sch
Title: 6502 CPU Card Pro

Size: USLetter | Rev: 1.0
KiCad E.D.A. 10.0.3 | Id: 1/1

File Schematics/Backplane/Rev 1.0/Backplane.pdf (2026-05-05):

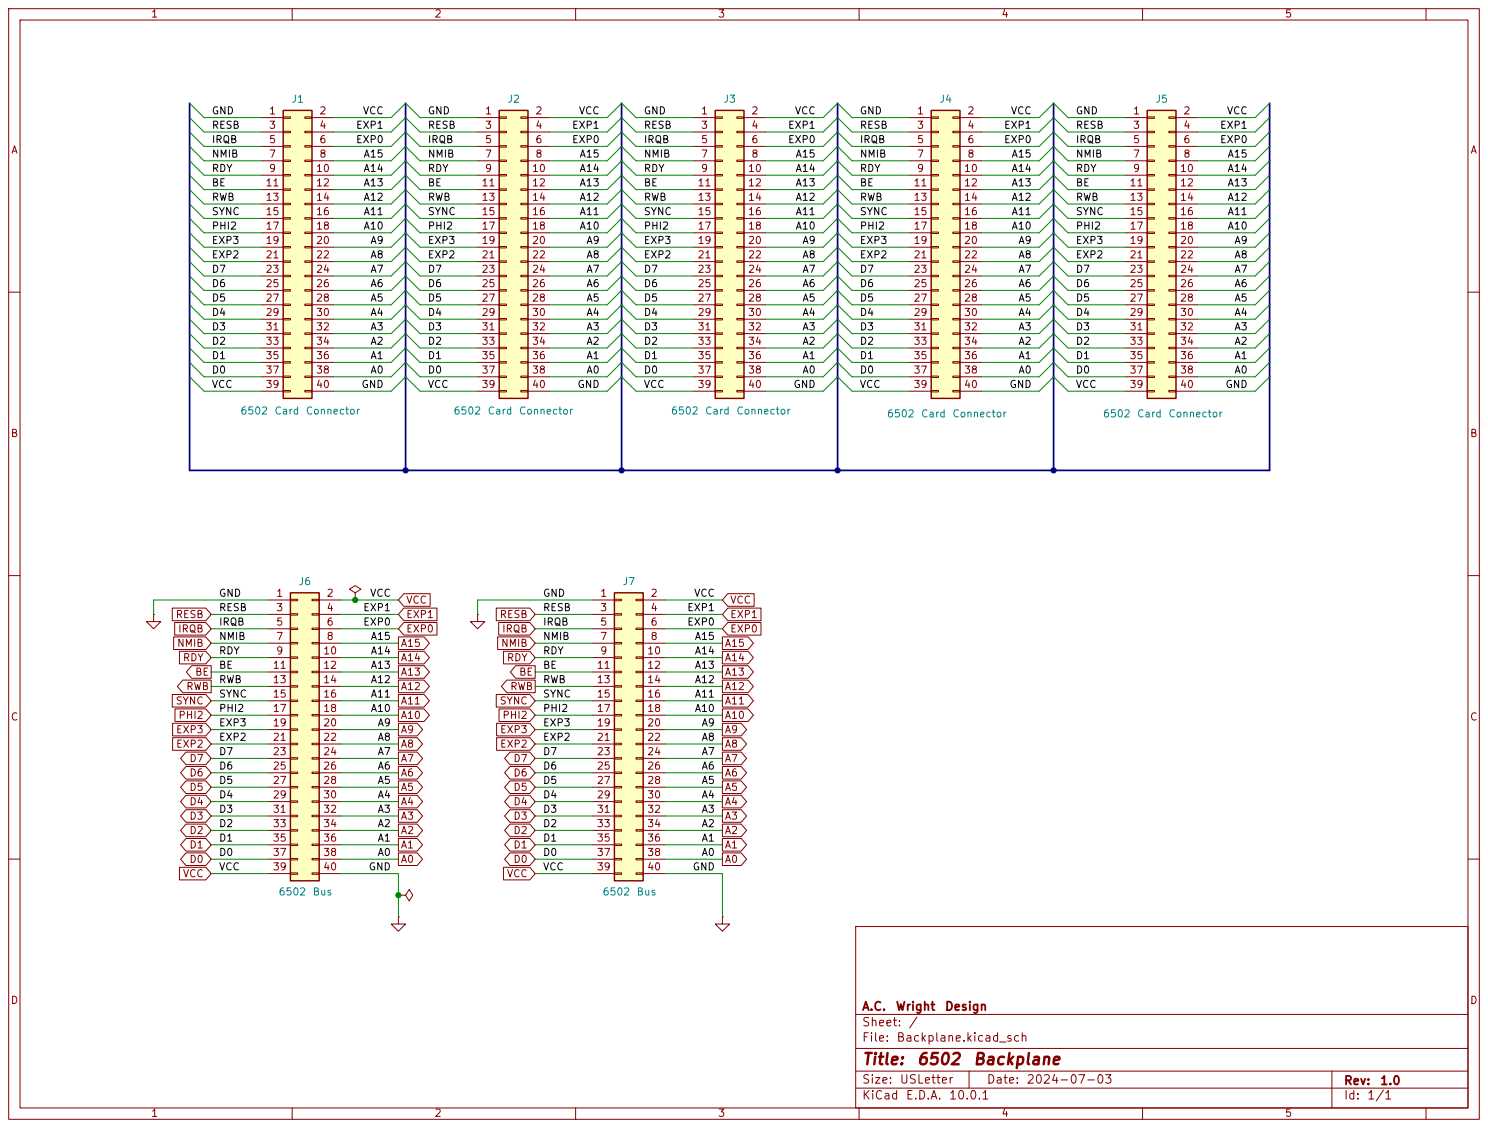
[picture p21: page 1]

Size: USLetter | Rev: 1.0
KiCad E.D.A. 10.0.1 | Id: 1/1

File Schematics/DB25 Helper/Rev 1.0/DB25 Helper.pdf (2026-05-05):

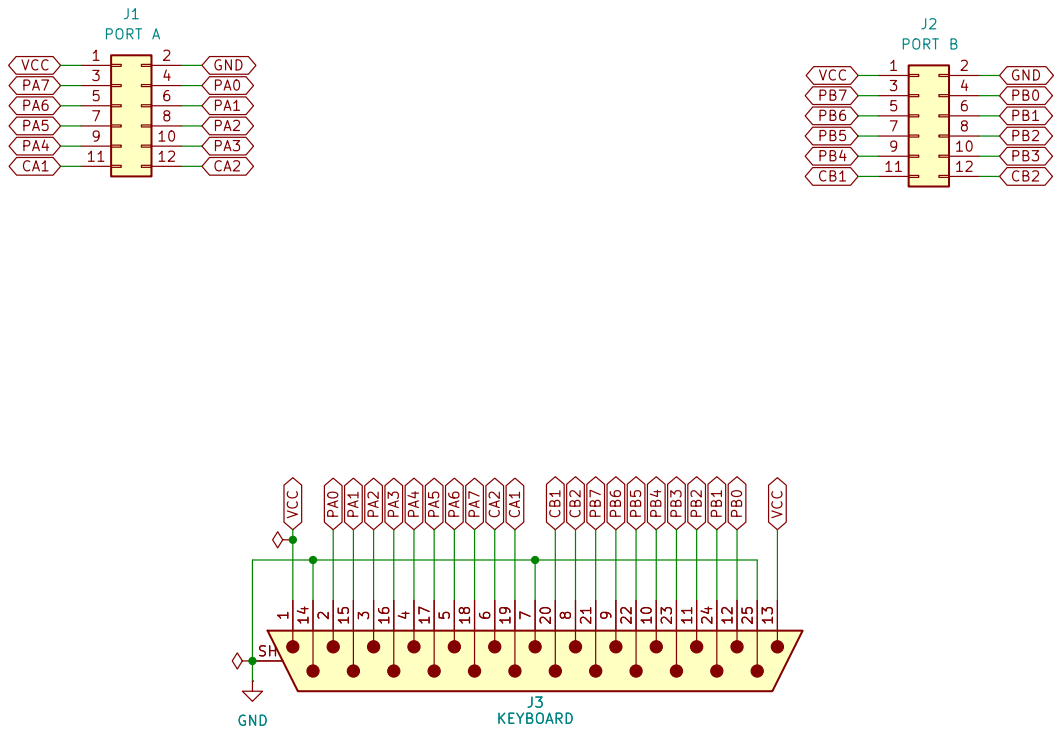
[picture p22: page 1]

Size: USLetter | Rev: 1.0
KiCad E.D.A. 10.0.1 | Id: 1/1

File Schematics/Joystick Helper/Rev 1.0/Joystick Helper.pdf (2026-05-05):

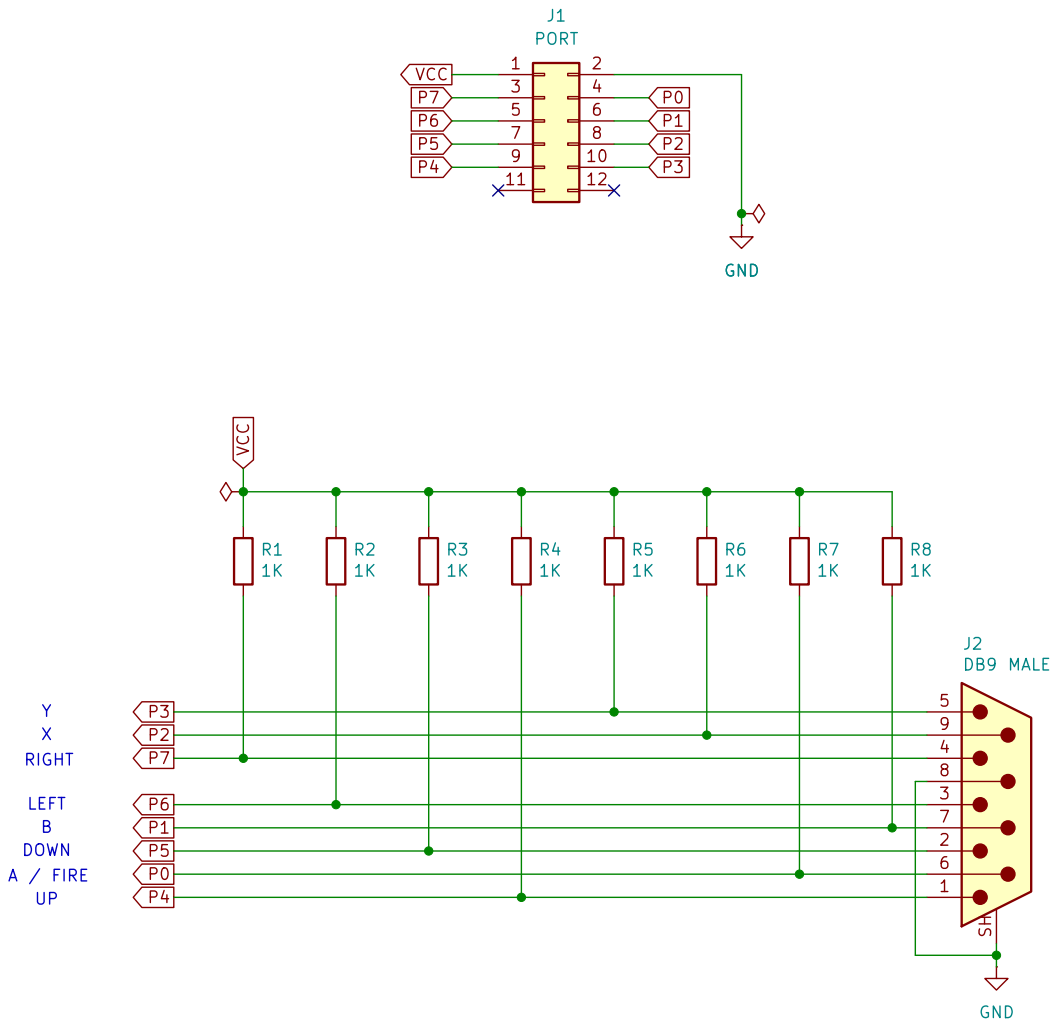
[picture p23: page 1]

Size: USLetter | Rev: 1.0
KiCad E.D.A. 10.0.1 | Id: 1/1

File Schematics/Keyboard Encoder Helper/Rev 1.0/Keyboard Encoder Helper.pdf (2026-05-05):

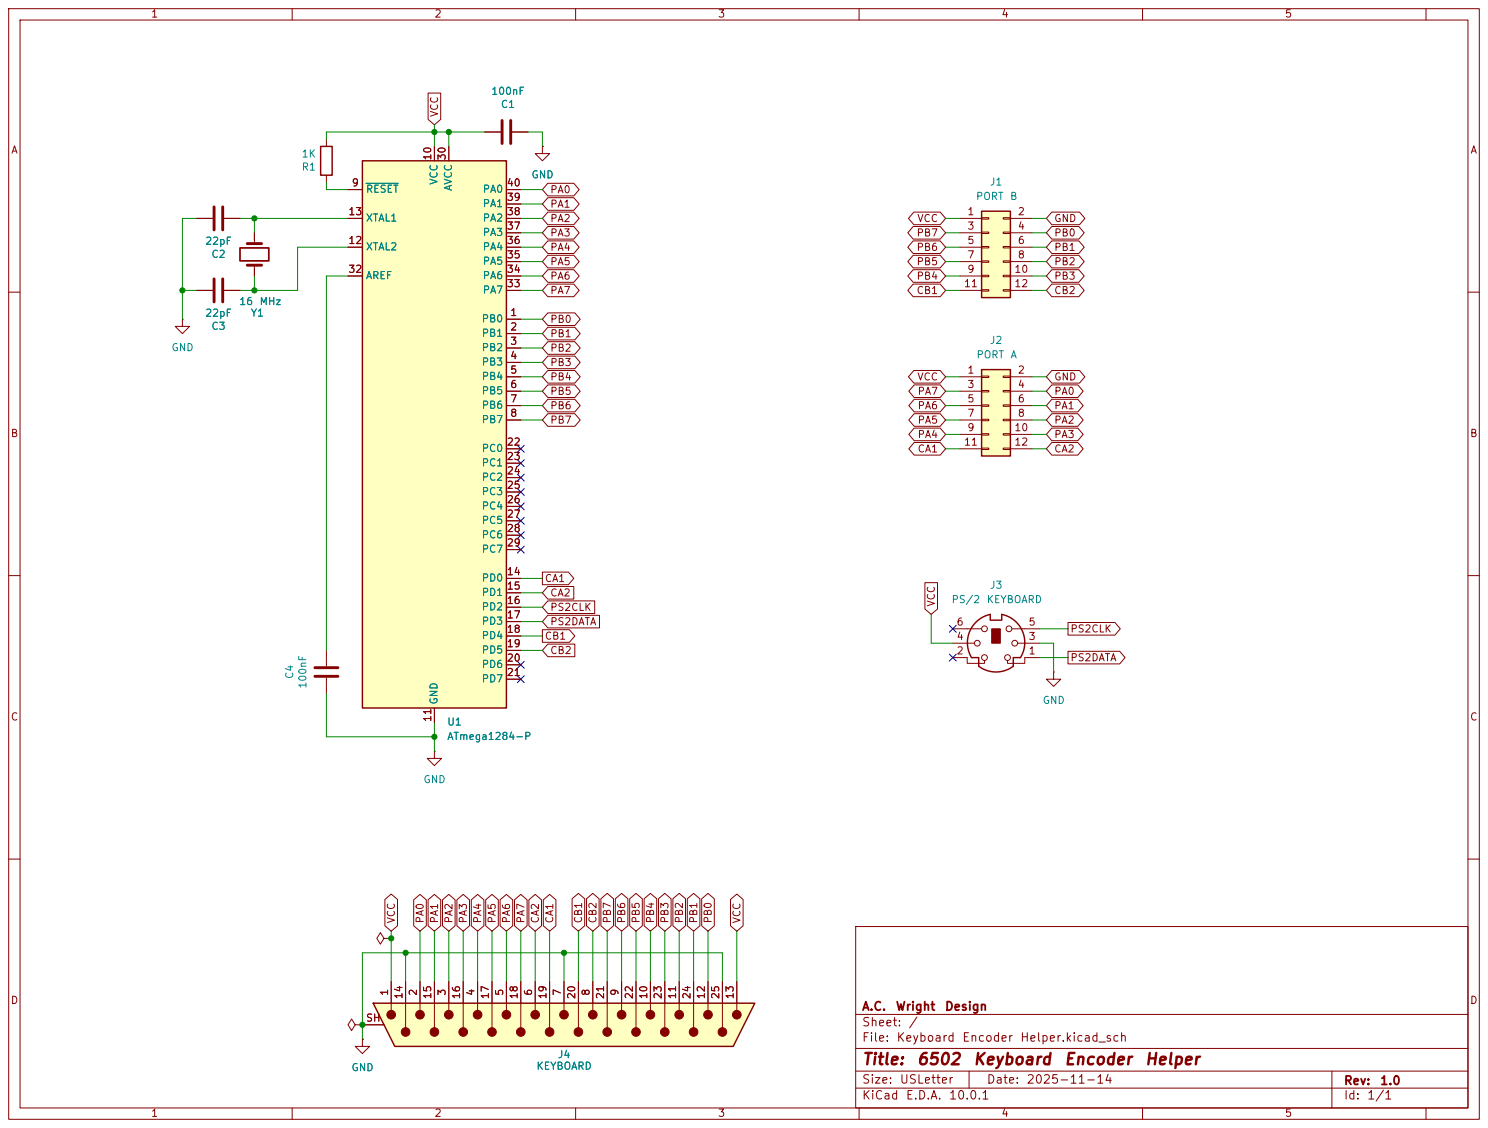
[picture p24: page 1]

Sheet: /
File: Keyboard Encoder Helper.kicad_sch
Title: 6502 Keyboard Encoder Helper

Size: USLetter | Rev: 1.0
KiCad E.D.A. 10.0.1 | Id: 1/1

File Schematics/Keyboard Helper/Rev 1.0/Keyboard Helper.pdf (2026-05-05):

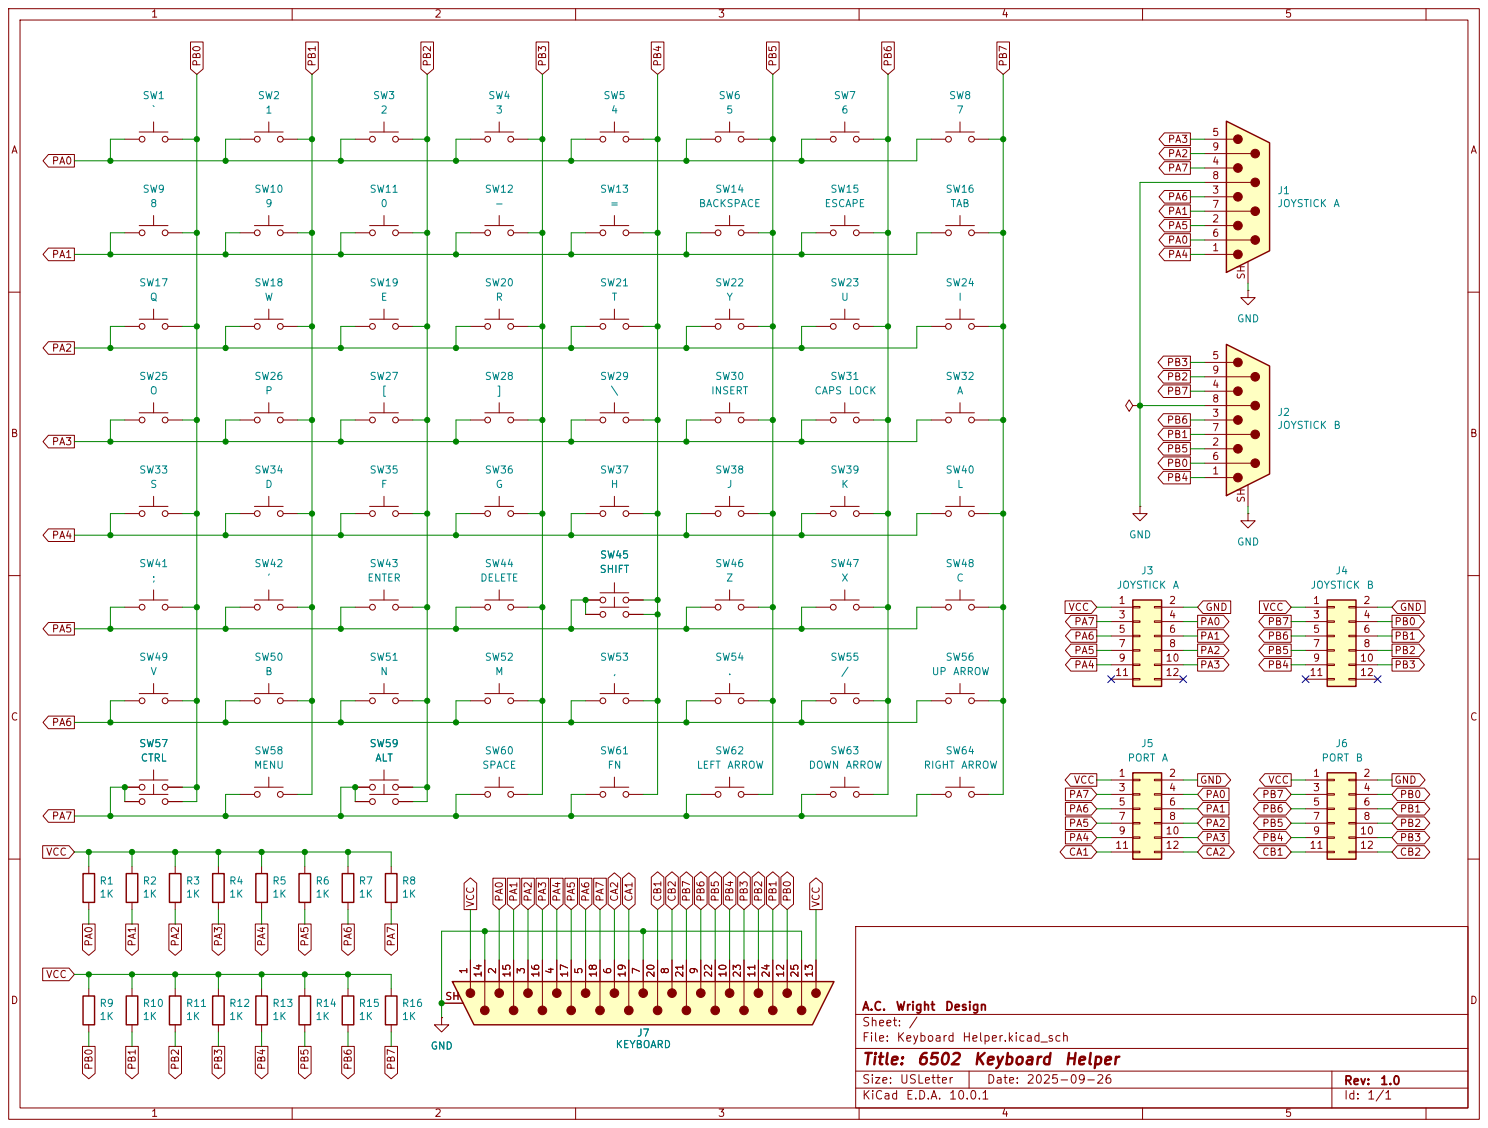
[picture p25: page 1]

Size: USLetter | Rev: 1.0
KiCad E.D.A. 10.0.1 | Id: 1/1

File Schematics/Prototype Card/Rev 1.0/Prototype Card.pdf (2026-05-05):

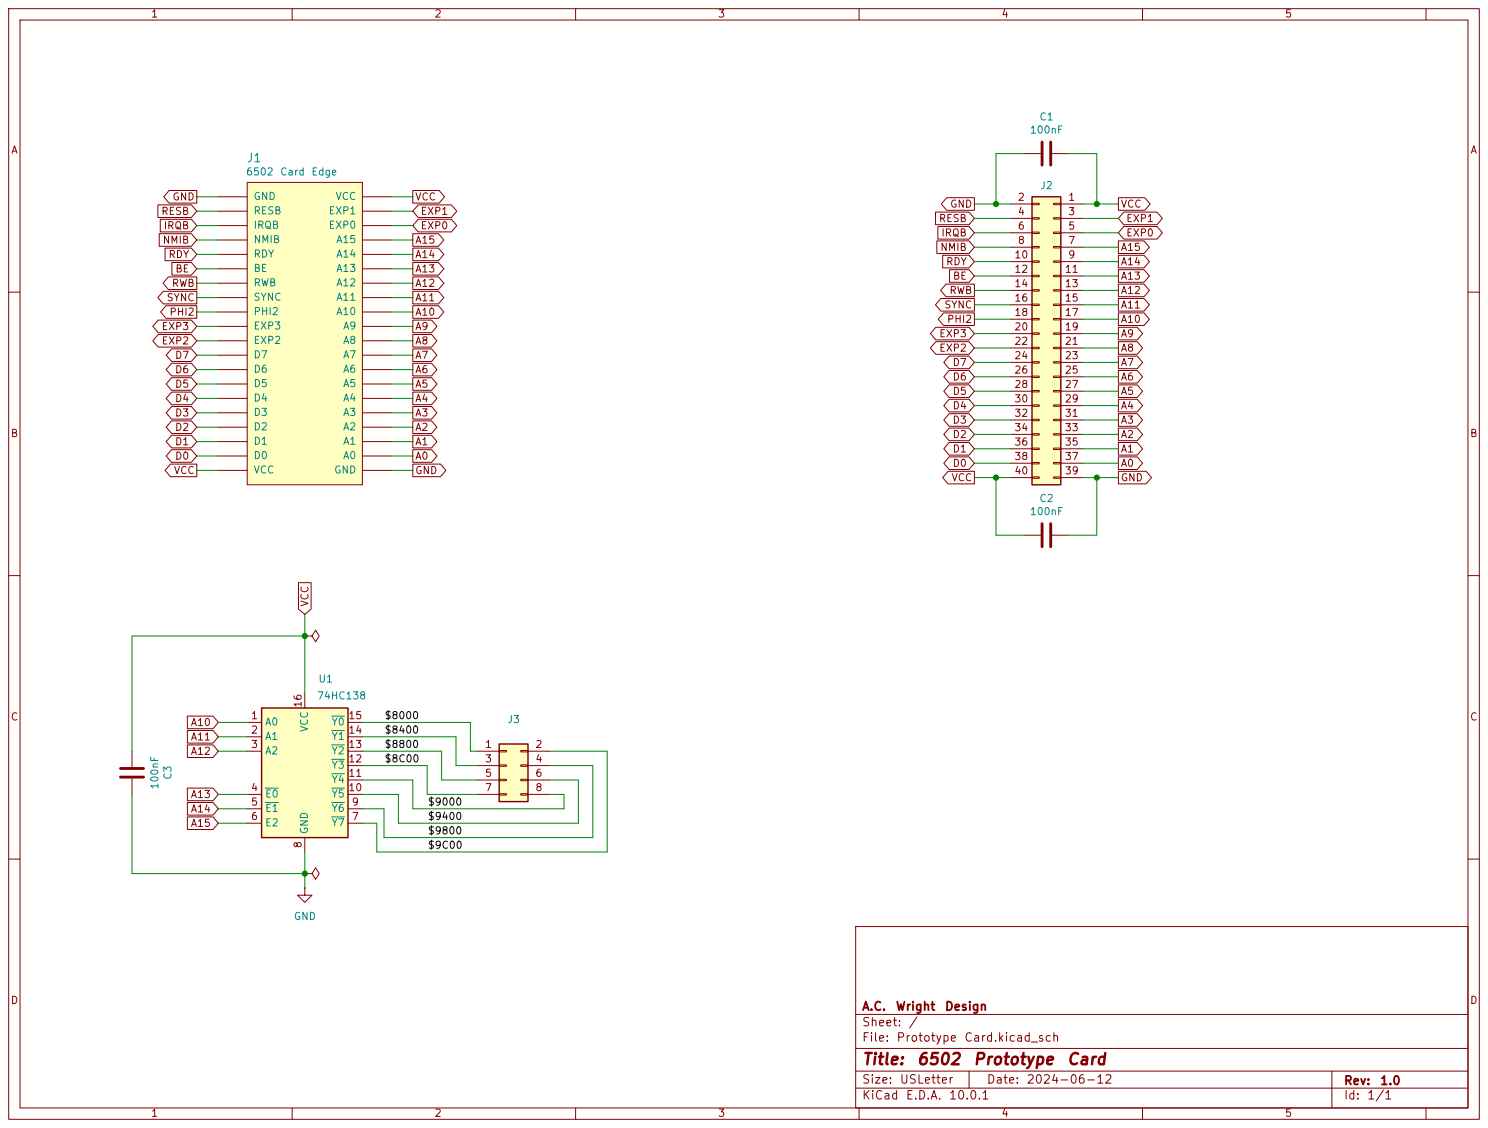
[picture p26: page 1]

Size: USLetter | Rev: 1.0
KiCad E.D.A. 10.0.1 | Id: 1/1

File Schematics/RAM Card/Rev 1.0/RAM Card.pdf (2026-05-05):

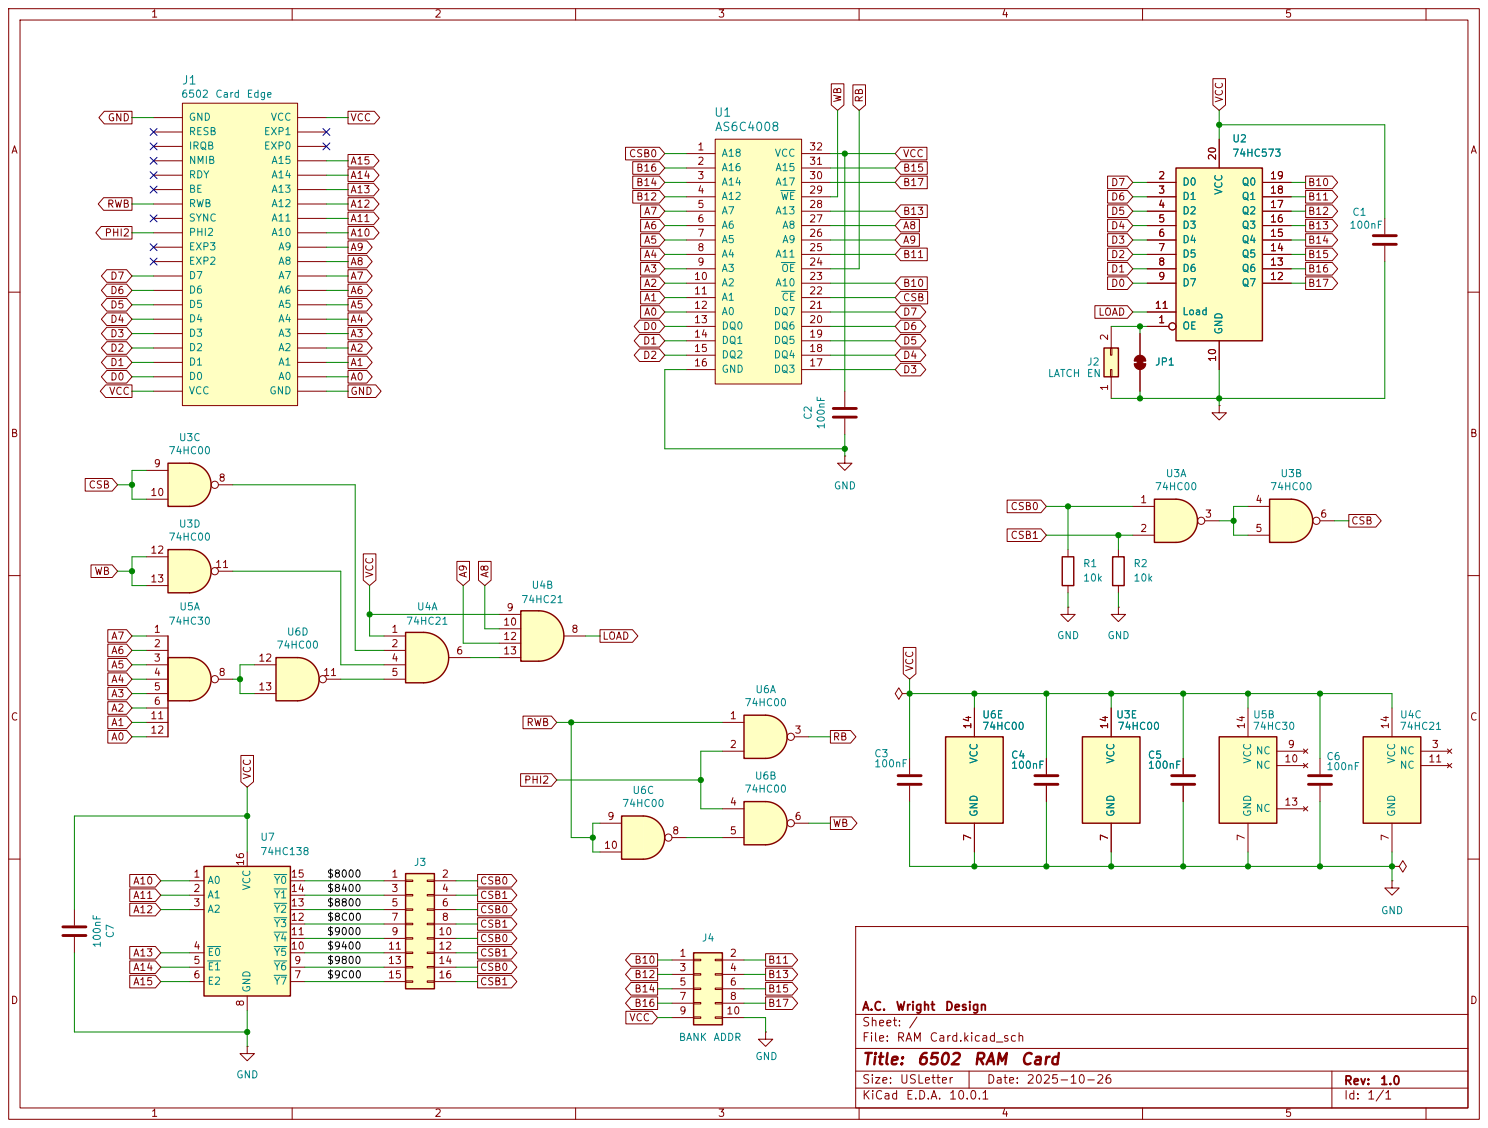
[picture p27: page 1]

7 NC 9 NC 10 NC 13 VCC 14U5B

Size: USLetter | Rev: 1.0
KiCad E.D.A. 10.0.1 | Id: 1/1

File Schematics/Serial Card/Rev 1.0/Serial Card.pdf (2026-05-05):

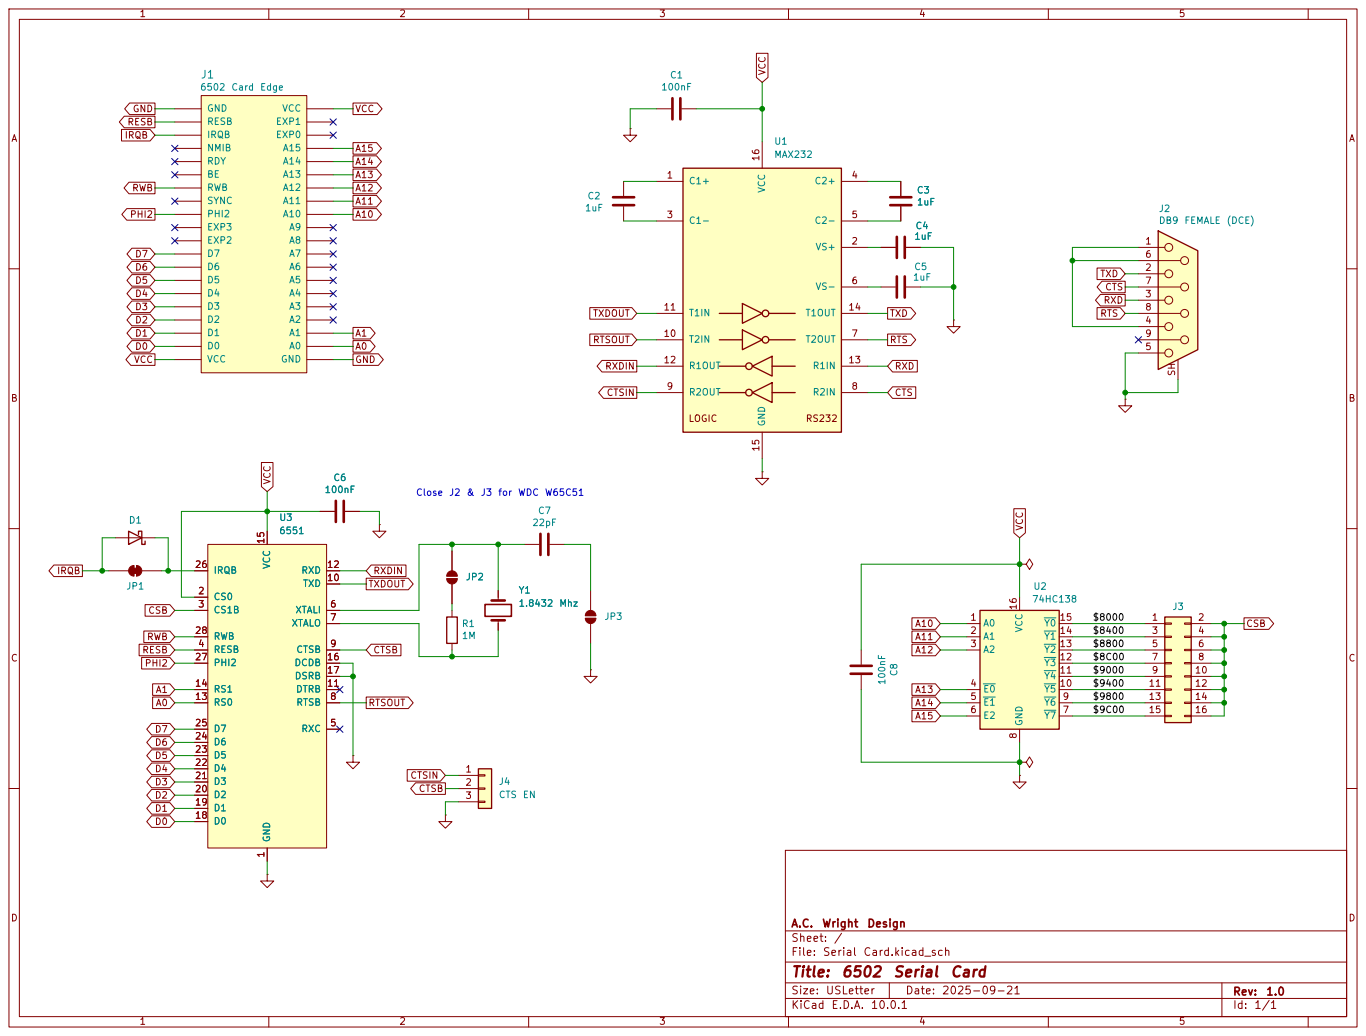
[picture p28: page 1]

$8800 5 | 6
$8C00 7 | 8
$9000 9 | 10
$9400 11 | 12

Size: USLetter | Rev: 1.0
KiCad E.D.A. 10.0.1 | Id: 1/1

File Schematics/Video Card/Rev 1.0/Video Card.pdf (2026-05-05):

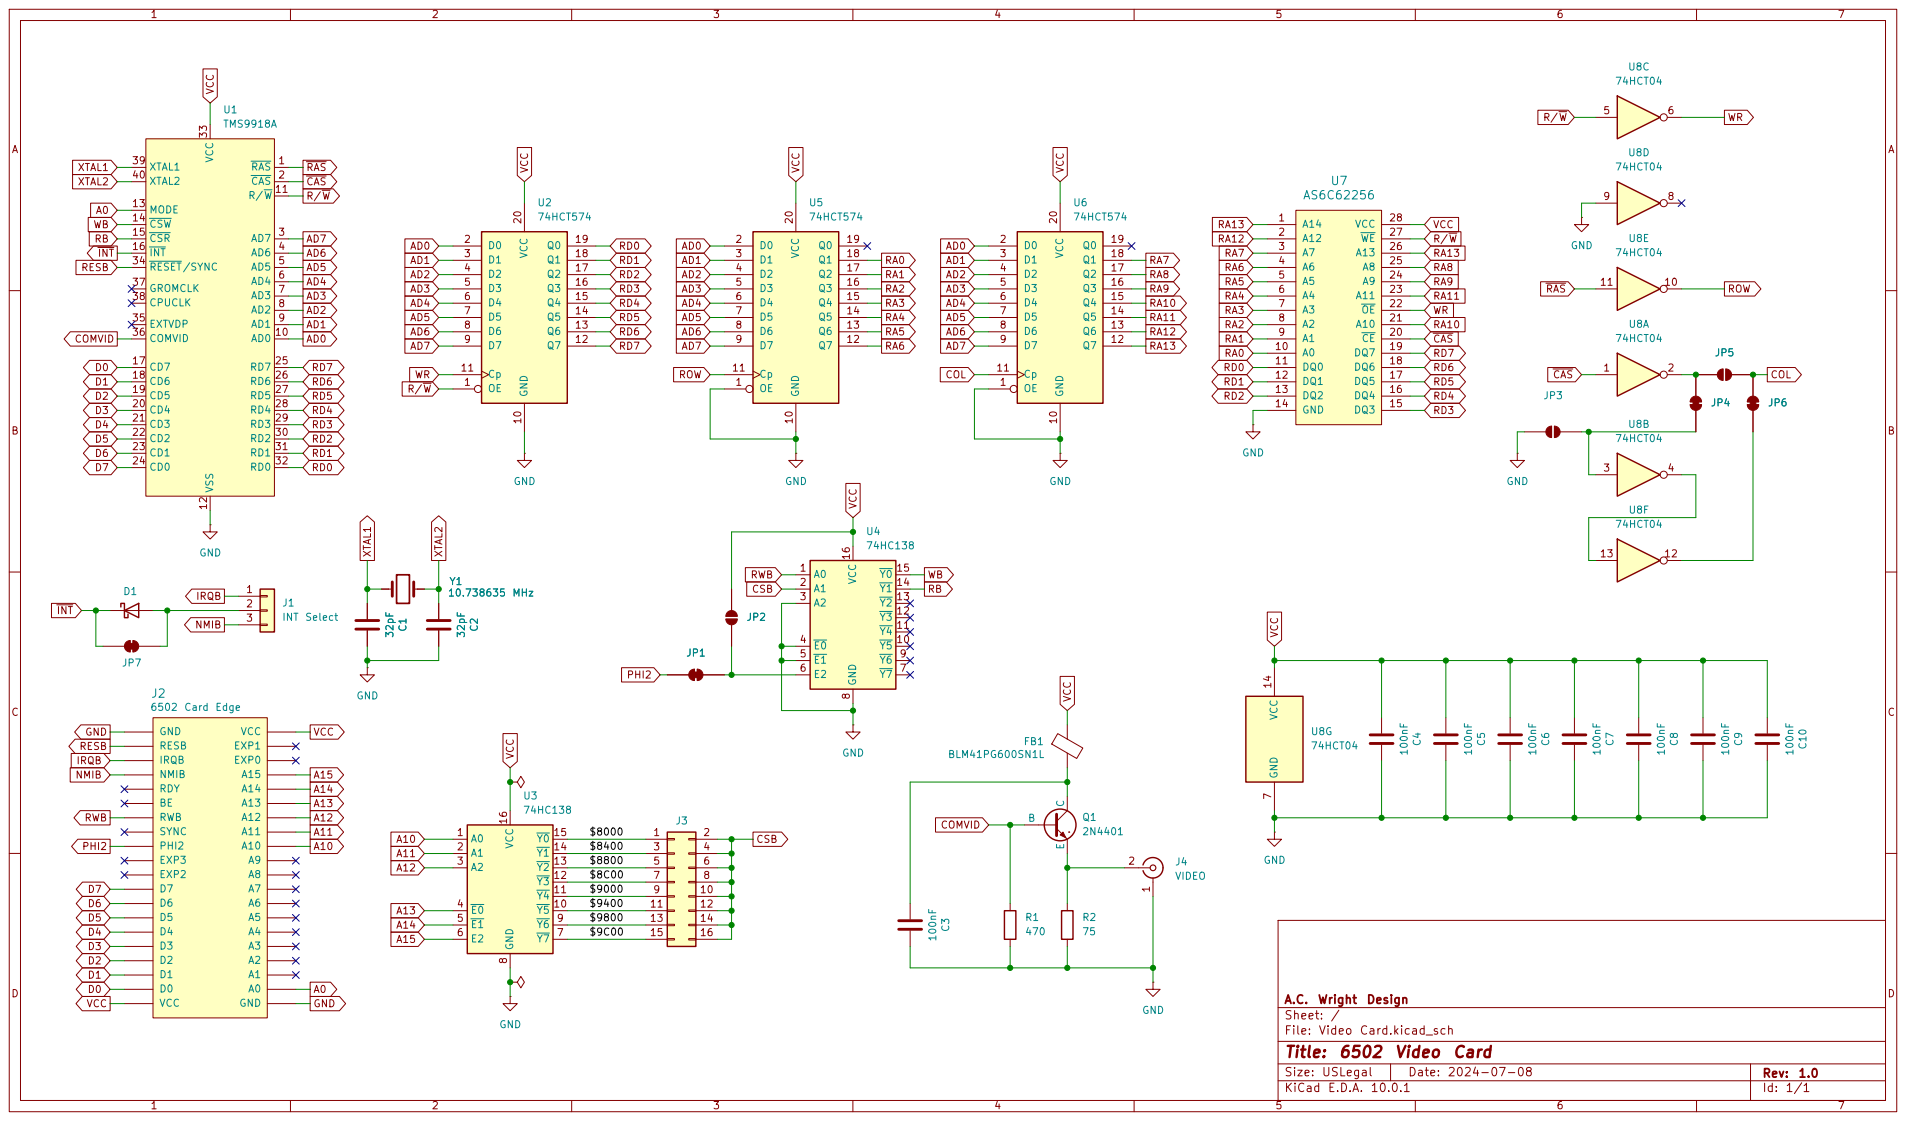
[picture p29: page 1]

11 VSS 12 MODE 13 CSW 14 CSR 15

EXTVDP 35 COMVID 36 GROMCLK 37 CPUCLK 38

$8400 3 | 4
$8800 5 | 6
$8C00 7 | 8
$9000 9 | 10
$9400 11 | 12

Size: USLegal | Rev: 1.0
KiCad E.D.A. 10.0.1 | Id: 1/1

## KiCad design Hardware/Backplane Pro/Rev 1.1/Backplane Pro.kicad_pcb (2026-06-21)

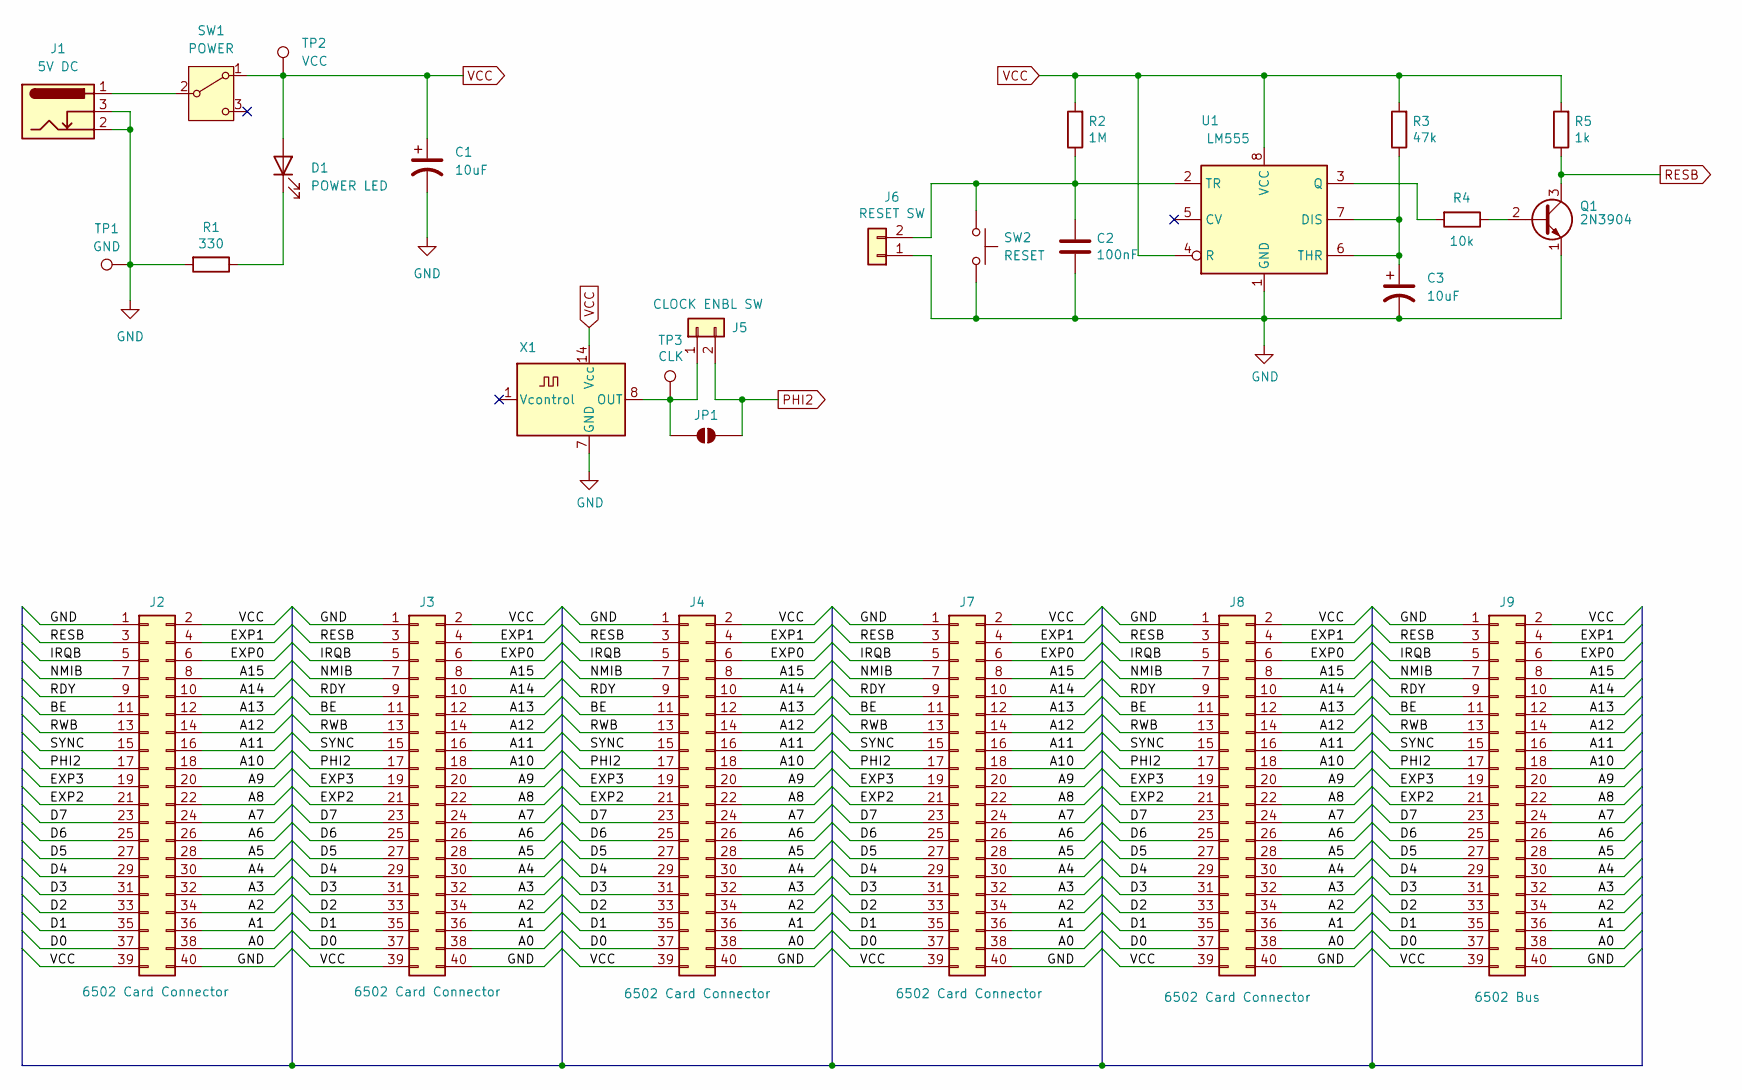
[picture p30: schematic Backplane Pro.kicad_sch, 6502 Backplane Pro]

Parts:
C1, C3: 10uF; CP_Radial_D4.0mm_P1.50mm
C2: 100nF; C_Disc_D5.0mm_W2.5mm_P2.50mm
D1: POWER LED; LED_D3.0mm; Digikey 732-5008-ND
J1: 5V DC; BarrelJack_Horizontal; Digikey 2073-DCJ200-10-A-K1-K-ND
J2, J3, J4, J7, J8: 6502 Card Connector; RHDR40W82P485X254_2X20_5740X93; Mouser 571-5-5530843-4
J5: CLOCK ENBL SW; JST_XH_B2B-XH-A_1x02_P2.50mm_Vertical; Digikey 455-2247-ND
J6: RESET SW; JST_XH_B2B-XH-A_1x02_P2.50mm_Vertical; Digikey 455-2247-ND
J9: 6502 Bus; 6502 Bus Connector
JP1: SolderJumper_2_Open; SolderJumper-2_P1.3mm_Open_RoundedPad1.0x1.5mm
Q1: 2N3904; TO-92_Inline
R1: 330; R_Axial_DIN0204_L3.6mm_D1.6mm_P5.08mm_Horizontal
R2: 1M; R_Axial_DIN0204_L3.6mm_D1.6mm_P5.08mm_Horizontal
R3: 47k; R_Axial_DIN0204_L3.6mm_D1.6mm_P5.08mm_Horizontal
R4: 10k; R_Axial_DIN0204_L3.6mm_D1.6mm_P5.08mm_Horizontal
R5: 1k; R_Axial_DIN0204_L3.6mm_D1.6mm_P5.08mm_Horizontal
SW1: POWER; SW_400MSP1R6BLKM6QE; Digikey EG4326-ND
SW2: RESET; SW_PUSH_6mm
TP1: GND; TestPoint_Pad_2.5x2.5mm
TP2: VCC; TestPoint_Pad_2.5x2.5mm
TP3: CLK; TestPoint_Pad_1.0x1.0mm
U1: LM555; DIP-8_W7.62mm_Socket_LongPads
X1: OCXO-14; Oscillator_DIP-14

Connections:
/A0: J2.38, J3.38, J4.38, J7.38, J8.38, J9.38
/A1: J2.36, J3.36, J4.36, J7.36, J8.36, J9.36
/A2: J2.34, J3.34, J4.34, J7.34, J8.34, J9.34
/A3: J2.32, J3.32, J4.32, J7.32, J8.32, J9.32
/A4: J2.30, J3.30, J4.30, J7.30, J8.30, J9.30
/A5: J2.28, J3.28, J4.28, J7.28, J8.28, J9.28
/A6: J2.26, J3.26, J4.26, J7.26, J8.26, J9.26
/A7: J2.24, J3.24, J4.24, J7.24, J8.24, J9.24
/A8: J2.22, J3.22, J4.22, J7.22, J8.22, J9.22
/A9: J2.20, J3.20, J4.20, J7.20, J8.20, J9.20
/A10: J2.18, J3.18, J4.18, J7.18, J8.18, J9.18
/A11: J2.16, J3.16, J4.16, J7.16, J8.16, J9.16
/A12: J2.14, J3.14, J4.14, J7.14, J8.14, J9.14
/A13: J2.12, J3.12, J4.12, J7.12, J8.12, J9.12
/A14: J2.10, J3.10, J4.10, J7.10, J8.10, J9.10
/A15: J2.8, J3.8, J4.8, J7.8, J8.8, J9.8
/BE: J2.11, J3.11, J4.11, J7.11, J8.11, J9.11
/D0: J2.37, J3.37, J4.37, J7.37, J8.37, J9.37
/D1: J2.35, J3.35, J4.35, J7.35, J8.35, J9.35
/D2: J2.33, J3.33, J4.33, J7.33, J8.33, J9.33
/D3: J2.31, J3.31, J4.31, J7.31, J8.31, J9.31
/D4: J2.29, J3.29, J4.29, J7.29, J8.29, J9.29
/D5: J2.27, J3.27, J4.27, J7.27, J8.27, J9.27
/D6: J2.25, J3.25, J4.25, J7.25, J8.25, J9.25
/D7: J2.23, J3.23, J4.23, J7.23, J8.23, J9.23
/EXP0: J2.6, J3.6, J4.6, J7.6, J8.6, J9.6
/EXP1: J2.4, J3.4, J4.4, J7.4, J8.4, J9.4
/EXP2: J2.21, J3.21, J4.21, J7.21, J8.21, J9.21
/EXP3: J2.19, J3.19, J4.19, J7.19, J8.19, J9.19
/IRQB: J2.5, J3.5, J4.5, J7.5, J8.5, J9.5
/NMIB: J2.7, J3.7, J4.7, J7.7, J8.7, J9.7
/RDY: J2.9, J3.9, J4.9, J7.9, J8.9, J9.9
/RWB: J2.13, J3.13, J4.13, J7.13, J8.13, J9.13
/SYNC: J2.15, J3.15, J4.15, J7.15, J8.15, J9.15
GND: C1.2, C2.2, C3.2, J1.2, J1.3, J2.1, J2.40, J3.1, J3.40, J4.1, J4.40, J6.1, J7.1, J7.40, J8.1, J8.40, J9.1, J9.40, Q1.1 (E), R1.2, SW2.2, TP1.1 (1_1), U1.1 (GND), X1.7 (GND)
unnamed: D1.1 (K), R1.1
unnamed: J5.1, JP1.1 (A), TP3.1 (1_1), X1.8 (OUT)
unnamed: C2.1, J6.2, R2.1, SW2.1, U1.2 (TR)
unnamed: Q1.2 (B), R4.1
unnamed: J1.1, SW1.2 (B)
unnamed: C3.1, R3.1, U1.6 (THR), U1.7 (DIS)
unnamed: R4.2, U1.3 (Q)
PHI2: J2.17, J3.17, J4.17, J5.2, J7.17, J8.17, J9.17, JP1.2 (B)
RESB: J2.3, J3.3, J4.3, J7.3, J8.3, J9.3, Q1.3 (C), R5.1
VCC: C1.1, D1.2 (A), J2.2, J2.39, J3.2, J3.39, J4.2, J4.39, J7.2, J7.39, J8.2, J8.39, J9.2, J9.39, R2.2, R3.2, R5.2, SW1.1 (A), TP2.1 (1_1), U1.4 (R), U1.8 (VCC), X1.14 (Vcc)

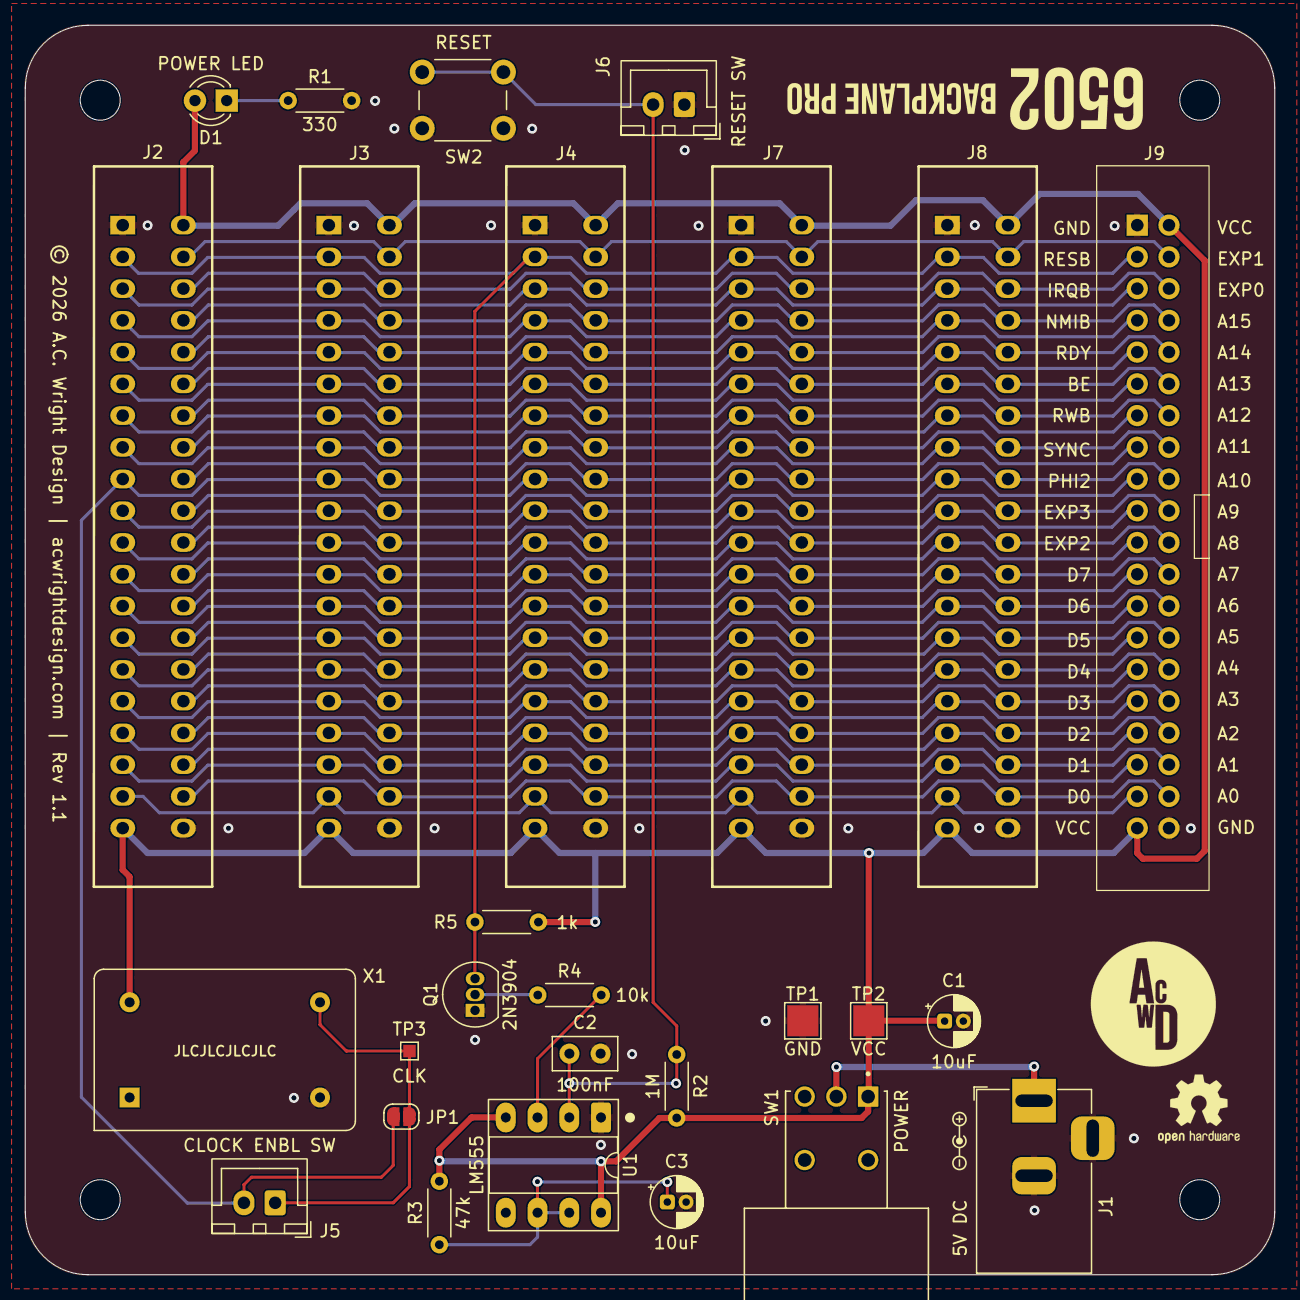
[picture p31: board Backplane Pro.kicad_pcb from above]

Board: 2 copper layers, 100.0 x 100.0 mm, 31 parts (0 on the bottom side), 45 nets.

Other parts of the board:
H1, H2, H3, H4: MountingHole; MountingHole_3.2mm_M3

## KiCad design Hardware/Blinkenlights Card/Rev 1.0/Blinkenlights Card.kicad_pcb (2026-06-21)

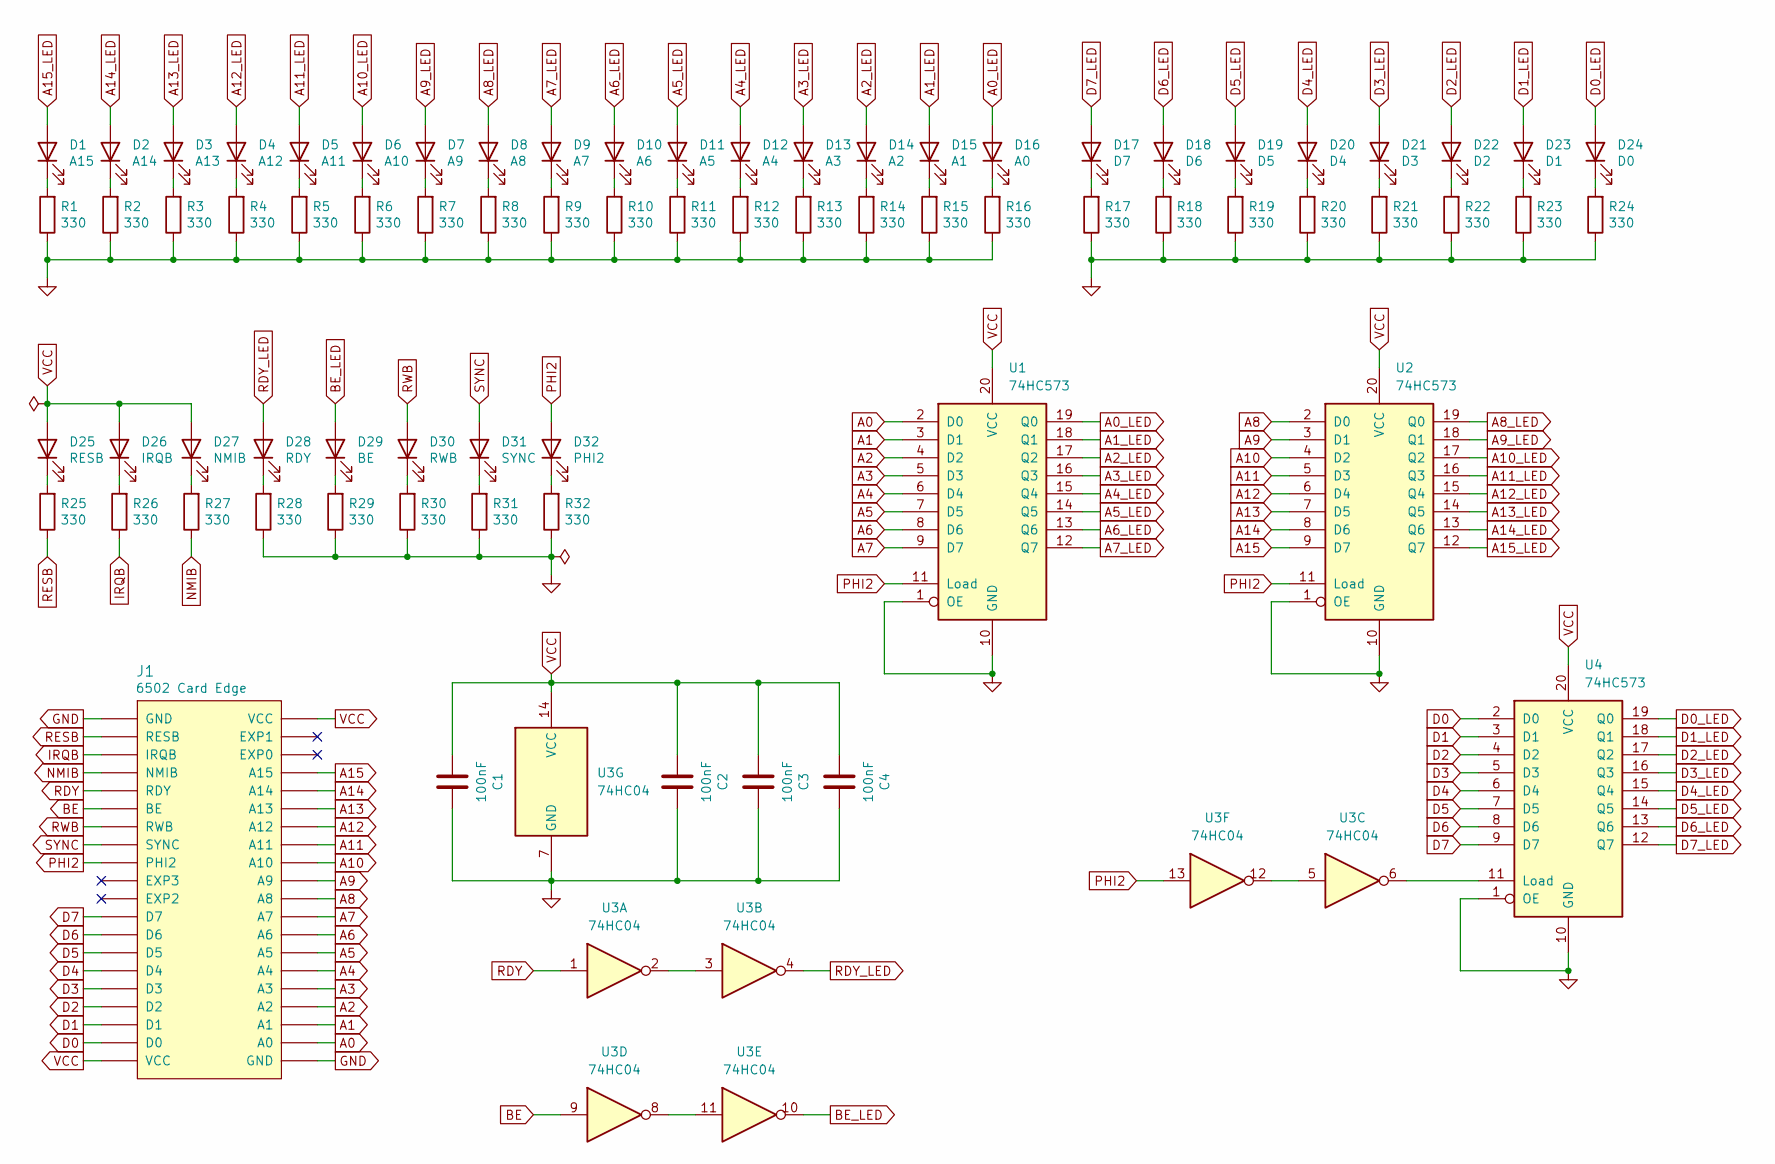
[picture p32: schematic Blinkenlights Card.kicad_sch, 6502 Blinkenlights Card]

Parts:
C1, C2, C3, C4: 100nF; C_0805_2012Metric; LCSC C49678
D1: A15; LED_0805_2012Metric; LCSC C2297
D2: A14; LED_0805_2012Metric; LCSC C2297
D3: A13; LED_0805_2012Metric; LCSC C2297
D4: A12; LED_0805_2012Metric; LCSC C2297
D5: A11; LED_0805_2012Metric; LCSC C2297
D6: A10; LED_0805_2012Metric; LCSC C2297
D7: A9; LED_0805_2012Metric; LCSC C2297
D8: A8; LED_0805_2012Metric; LCSC C2297
D9: A7; LED_0805_2012Metric; LCSC C2297
D10: A6; LED_0805_2012Metric; LCSC C2297
D11: A5; LED_0805_2012Metric; LCSC C2297
D12: A4; LED_0805_2012Metric; LCSC C2297
D13: A3; LED_0805_2012Metric; LCSC C2297
D14: A2; LED_0805_2012Metric; LCSC C2297
D15: A1; LED_0805_2012Metric; LCSC C2297
D16: A0; LED_0805_2012Metric; LCSC C2297
D17: D7; LED_0805_2012Metric; LCSC C2297
D18: D6; LED_0805_2012Metric; LCSC C2297
D19: D5; LED_0805_2012Metric; LCSC C2297
D20: D4; LED_0805_2012Metric; LCSC C2297
D21: D3; LED_0805_2012Metric; LCSC C2297
D22: D2; LED_0805_2012Metric; LCSC C2297
D23: D1; LED_0805_2012Metric; LCSC C2297
D24: D0; LED_0805_2012Metric; LCSC C2297
D25: RESB; LED_0805_2012Metric; LCSC C2297
D26: IRQB; LED_0805_2012Metric; LCSC C2295
D27: NMIB; LED_0805_2012Metric; LCSC C2295
D28: RDY; LED_0805_2012Metric; LCSC C2296
D29: BE; LED_0805_2012Metric; LCSC C2296
D30: RWB; LED_0805_2012Metric; LCSC C2296
D31: SYNC; LED_0805_2012Metric; LCSC C2293
D32: PHI2; LED_0805_2012Metric; LCSC C2293
J1: 6502 Card Edge
R1, R2, R3, R4, R5, R6, R7, R8, R9, R10, R11, R12, R13, R14, R15, R16, R17, R18, R19, R20, R21, R22, R23, R24, R25, R26, R27, R28, R29, R30, R31, R32: 330; R_0805_2012Metric; LCSC C17630
U1, U2, U4: 74HC573; SOIC-20W_7.5x12.8mm_P1.27mm; LCSC C5608
U3: 74HC04; SOIC-14_3.9x8.7mm_P1.27mm; LCSC C5590

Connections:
A0: J1.A0, U1.2 (D0)
A0_LED: D16.2 (A), U1.19 (Q0)
A1: J1.A1, U1.3 (D1)
A1_LED: D15.2 (A), U1.18 (Q1)
A2: J1.A2, U1.4 (D2)
A2_LED: D14.2 (A), U1.17 (Q2)
A3: J1.A3, U1.5 (D3)
A3_LED: D13.2 (A), U1.16 (Q3)
A4: J1.A4, U1.6 (D4)
A4_LED: D12.2 (A), U1.15 (Q4)
A5: J1.A5, U1.7 (D5)
A5_LED: D11.2 (A), U1.14 (Q5)
A6: J1.A6, U1.8 (D6)
A6_LED: D10.2 (A), U1.13 (Q6)
A7: J1.A7, U1.9 (D7)
A7_LED: D9.2 (A), U1.12 (Q7)
A8: J1.A8, U2.2 (D0)
A8_LED: D8.2 (A), U2.19 (Q0)
A9: J1.A9, U2.3 (D1)
A9_LED: D7.2 (A), U2.18 (Q1)
A10: J1.A10, U2.4 (D2)
A10_LED: D6.2 (A), U2.17 (Q2)
A11: J1.A11, U2.5 (D3)
A11_LED: D5.2 (A), U2.16 (Q3)
A12: J1.A12, U2.6 (D4)
A12_LED: D4.2 (A), U2.15 (Q4)
A13: J1.A13, U2.7 (D5)
A13_LED: D3.2 (A), U2.14 (Q5)
A14: J1.A14, U2.8 (D6)
A14_LED: D2.2 (A), U2.13 (Q6)
A15: J1.A15, U2.9 (D7)
A15_LED: D1.2 (A), U2.12 (Q7)
BE: J1.BE, U3.9
BE_LED: D29.2 (A), U3.10
D0: J1.D0, U4.2 (D0)
D0_LED: D24.2 (A), U4.19 (Q0)
D1: J1.D1, U4.3 (D1)
D1_LED: D23.2 (A), U4.18 (Q1)
D2: J1.D2, U4.4 (D2)
D2_LED: D22.2 (A), U4.17 (Q2)
D3: J1.D3, U4.5 (D3)
D3_LED: D21.2 (A), U4.16 (Q3)
D4: J1.D4, U4.6 (D4)
D4_LED: D20.2 (A), U4.15 (Q4)
D5: J1.D5, U4.7 (D5)
D5_LED: D19.2 (A), U4.14 (Q5)
D6: J1.D6, U4.8 (D6)
D6_LED: D18.2 (A), U4.13 (Q6)
D7: J1.D7, U4.9 (D7)
D7_LED: D17.2 (A), U4.12 (Q7)
GND: C1.2, C2.2, C3.2, C4.2, J1.GND, R1.1, R2.1, R3.1, R4.1, R5.1, R6.1, R7.1, R8.1, R9.1, R10.1, R11.1, R12.1, R13.1, R14.1, R15.1, R16.1, R17.1, R18.1, R19.1, R20.1, R21.1, R22.1, R23.1, R24.1, R28.1, R29.1, R30.1, R31.1, R32.1, U1.1 (OE), U1.10 (GND), U2.1 (OE), U2.10 (GND), U3.7 (GND), U4.1 (OE), U4.10 (GND)
IRQB: J1.IRQB, R26.1
NMIB: J1.NMIB, R27.1
unnamed: D1.1 (K), R1.2
unnamed: D2.1 (K), R2.2
unnamed: D3.1 (K), R3.2
unnamed: D4.1 (K), R4.2
unnamed: D5.1 (K), R5.2
unnamed: D6.1 (K), R6.2
unnamed: D7.1 (K), R7.2
unnamed: D8.1 (K), R8.2
unnamed: D9.1 (K), R9.2
unnamed: D10.1 (K), R10.2
unnamed: D11.1 (K), R11.2
unnamed: D12.1 (K), R12.2
unnamed: D13.1 (K), R13.2
unnamed: D14.1 (K), R14.2
unnamed: D15.1 (K), R15.2
unnamed: D16.1 (K), R16.2
unnamed: D17.1 (K), R17.2
unnamed: D18.1 (K), R18.2
unnamed: D19.1 (K), R19.2
unnamed: D20.1 (K), R20.2
unnamed: D21.1 (K), R21.2
unnamed: D22.1 (K), R22.2
unnamed: D23.1 (K), R23.2
unnamed: D24.1 (K), R24.2
unnamed: D25.1 (K), R25.2
unnamed: D26.1 (K), R26.2
unnamed: D27.1 (K), R27.2
unnamed: D28.1 (K), R28.2
unnamed: D29.1 (K), R29.2
unnamed: D30.1 (K), R30.2
unnamed: D31.1 (K), R31.2
unnamed: D32.1 (K), R32.2
unnamed: U3.2, U3.3
unnamed: U3.8, U3.11
unnamed: U3.5, U3.12
unnamed: U3.6, U4.11 (Load)
PHI2: D32.2 (A), J1.PHI2, U1.11 (Load), U2.11 (Load), U3.13
RDY: J1.RDY, U3.1
RDY_LED: D28.2 (A), U3.4
RESB: J1.RESB, R25.1
RWB: D30.2 (A), J1.RWB
SYNC: D31.2 (A), J1.SYNC
VCC: C1.1, C2.1, C3.1, C4.1, D25.2 (A), D26.2 (A), D27.2 (A), J1.VCC, U1.20 (VCC), U2.20 (VCC), U3.14 (VCC), U4.20 (VCC)

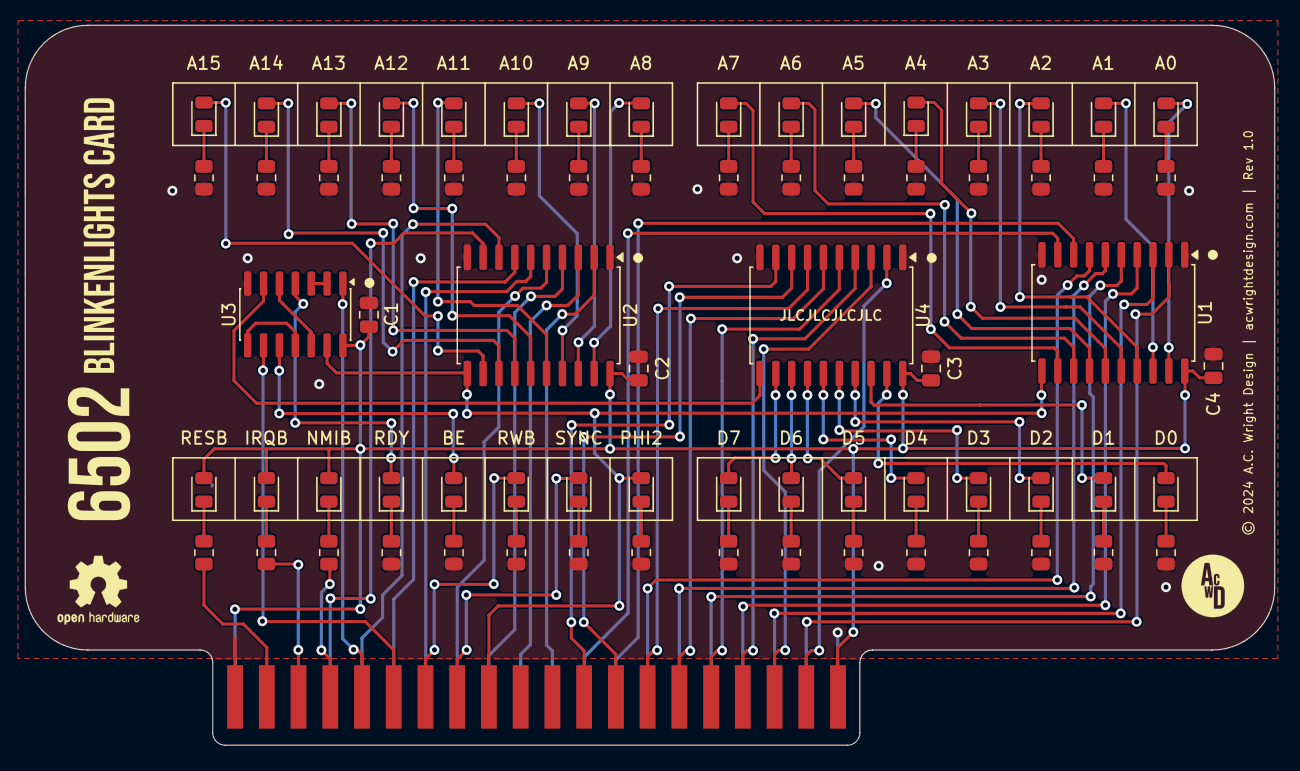
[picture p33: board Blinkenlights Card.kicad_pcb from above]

Board: 2 copper layers, 100.0 x 57.6 mm, 73 parts (0 on the bottom side), 96 nets.

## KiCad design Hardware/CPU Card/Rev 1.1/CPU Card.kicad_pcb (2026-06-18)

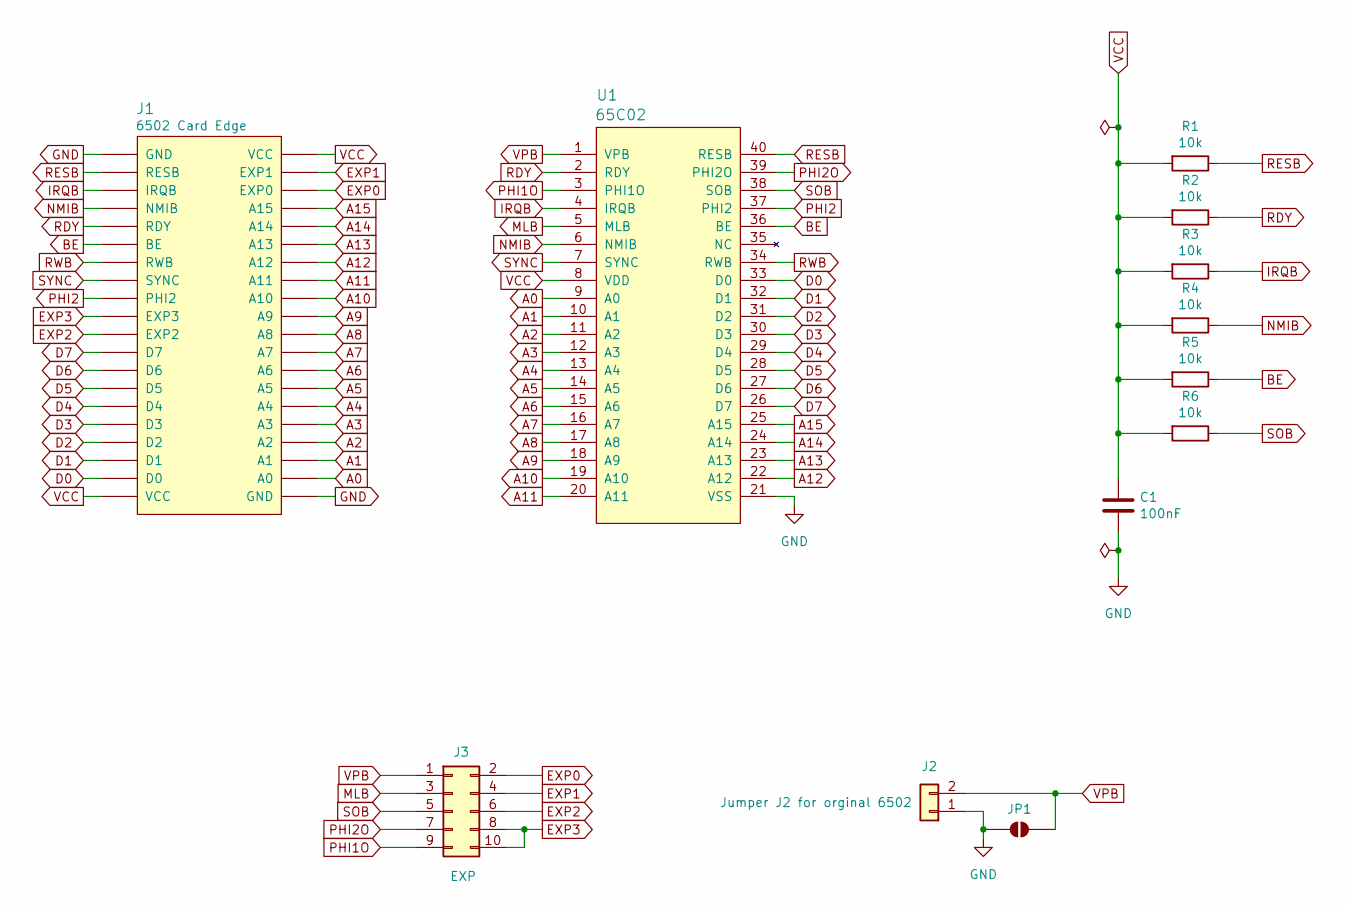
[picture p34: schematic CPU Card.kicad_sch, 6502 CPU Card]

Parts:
C1: 100nF; C_0805_2012Metric; LCSC C49678
J1: 6502 Card Edge
J2: Conn_01x02; PinHeader_1x02_P2.54mm_Vertical
J3: EXP; PinHeader_2x05_P2.54mm_Vertical
JP1: SolderJumper_2_Open; SolderJumper-2_P1.3mm_Open_RoundedPad1.0x1.5mm
R1, R2, R3, R4, R5, R6: 10k; R_0805_2012Metric; LCSC C2930231
U1: 65C02; DIP-40_W15.24mm_Socket_LongPads

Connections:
A0: J1.A0, U1.9 (A0)
A1: J1.A1, U1.10 (A1)
A2: J1.A2, U1.11 (A2)
A3: J1.A3, U1.12 (A3)
A4: J1.A4, U1.13 (A4)
A5: J1.A5, U1.14 (A5)
A6: J1.A6, U1.15 (A6)
A7: J1.A7, U1.16 (A7)
A8: J1.A8, U1.17 (A8)
A9: J1.A9, U1.18 (A9)
A10: J1.A10, U1.19 (A10)
A11: J1.A11, U1.20 (A11)
A12: J1.A12, U1.22 (A12)
A13: J1.A13, U1.23 (A13)
A14: J1.A14, U1.24 (A14)
A15: J1.A15, U1.25 (A15)
BE: J1.BE, R5.1, U1.36 (BE)
D0: J1.D0, U1.33 (D0)
D1: J1.D1, U1.32 (D1)
D2: J1.D2, U1.31 (D2)
D3: J1.D3, U1.30 (D3)
D4: J1.D4, U1.29 (D4)
D5: J1.D5, U1.28 (D5)
D6: J1.D6, U1.27 (D6)
D7: J1.D7, U1.26 (D7)
EXP0: J1.EXP0, J3.2
EXP1: J1.EXP1, J3.4
EXP2: J1.EXP2, J3.6
EXP3: J1.EXP3, J3.8, J3.10
GND: C1.2, J1.GND, J2.1, JP1.1 (A), U1.21 (VSS)
IRQB: J1.IRQB, R3.1, U1.4 (IRQB)
MLB: J3.3, U1.5 (MLB)
NMIB: J1.NMIB, R4.1, U1.6 (NMIB)
PHI1O: J3.9, U1.3 (PHI1O)
PHI2: J1.PHI2, U1.37 (PHI2)
PHI2O: J3.7, U1.39 (PHI2O)
RDY: J1.RDY, R2.1, U1.2 (RDY)
RESB: J1.RESB, R1.1, U1.40 (RESB)
RWB: J1.RWB, U1.34 (RWB)
SOB: J3.5, R6.1, U1.38 (SOB)
SYNC: J1.SYNC, U1.7 (SYNC)
VCC: C1.1, J1.VCC, R1.2, R2.2, R3.2, R4.2, R5.2, R6.2, U1.8 (VDD)
VPB: J2.2, J3.1, JP1.2 (B), U1.1 (VPB)

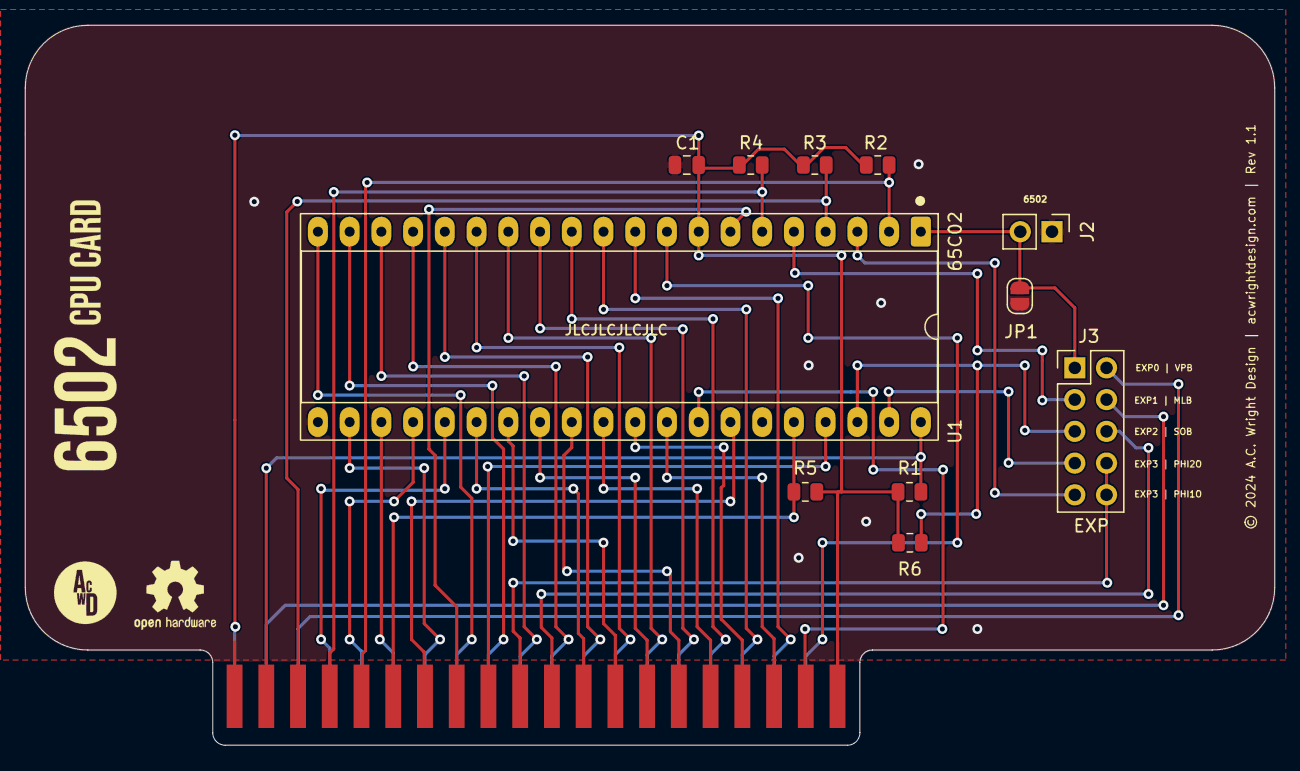
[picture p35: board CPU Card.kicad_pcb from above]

Board: 2 copper layers, 100.0 x 57.6 mm, 12 parts (0 on the bottom side), 43 nets.

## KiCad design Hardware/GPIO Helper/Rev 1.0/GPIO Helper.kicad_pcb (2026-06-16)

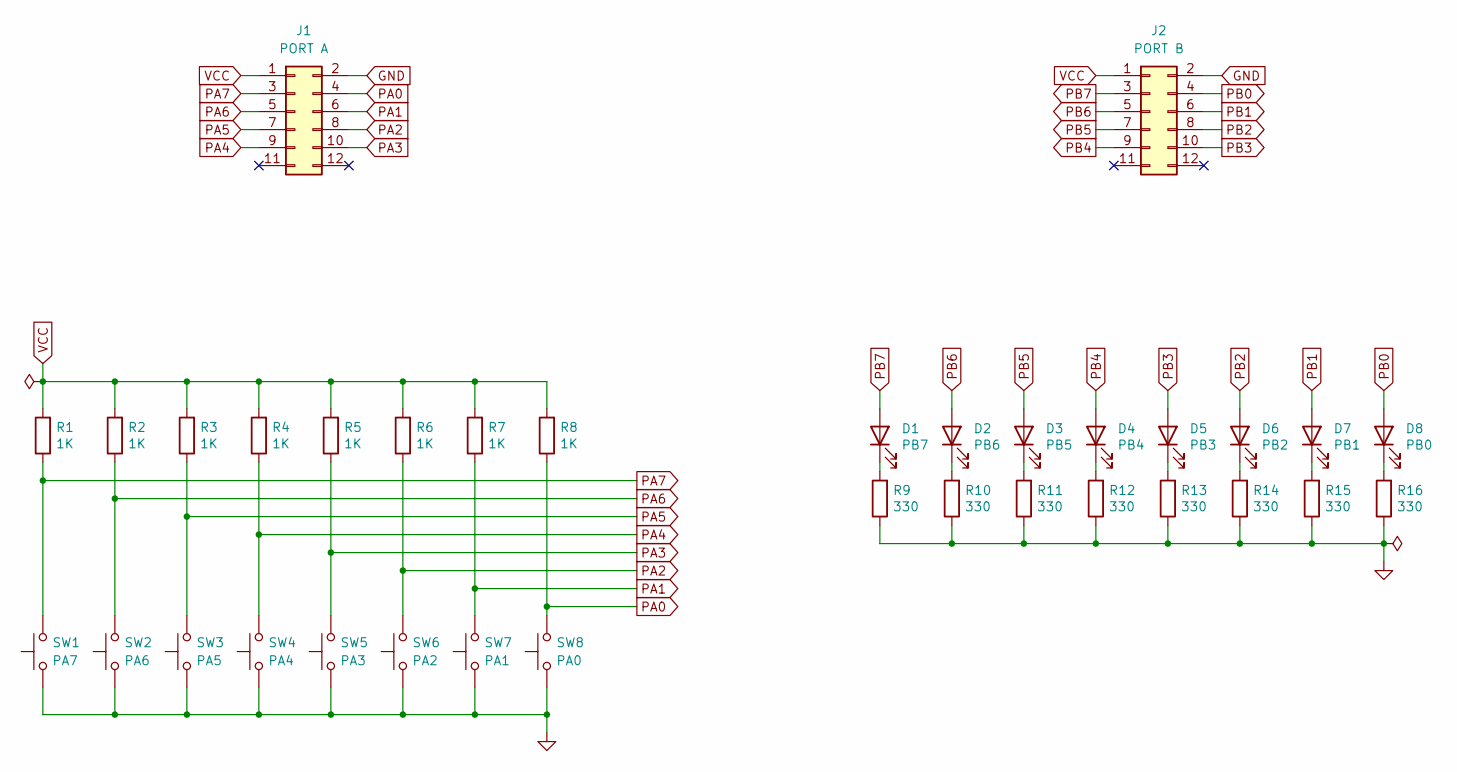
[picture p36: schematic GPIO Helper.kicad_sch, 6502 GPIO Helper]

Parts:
D1: PB7; LED_D3.0mm
D2: PB6; LED_D3.0mm
D3: PB5; LED_D3.0mm
D4: PB4; LED_D3.0mm
D5: PB3; LED_D3.0mm
D6: PB2; LED_D3.0mm
D7: PB1; LED_D3.0mm
D8: PB0; LED_D3.0mm
J1: PORT A; 6502 GPIO Connector
J2: PORT B; 6502 GPIO Connector
R1, R2, R3, R4, R5, R6, R7, R8: 1K; R_Axial_DIN0204_L3.6mm_D1.6mm_P5.08mm_Horizontal
R9, R10, R11, R12, R13, R14, R15, R16: 330; R_Axial_DIN0204_L3.6mm_D1.6mm_P5.08mm_Horizontal
SW1: PA7; SW_PUSH_6mm; Digikey 2223-TS02-66-50-BK-160-LCR-D-ND
SW2: PA6; SW_PUSH_6mm; Digikey 2223-TS02-66-50-BK-160-LCR-D-ND
SW3: PA5; SW_PUSH_6mm; Digikey 2223-TS02-66-50-BK-160-LCR-D-ND
SW4: PA4; SW_PUSH_6mm; Digikey 2223-TS02-66-50-BK-160-LCR-D-ND
SW5: PA3; SW_PUSH_6mm; Digikey 2223-TS02-66-50-BK-160-LCR-D-ND
SW6: PA2; SW_PUSH_6mm; Digikey 2223-TS02-66-50-BK-160-LCR-D-ND
SW7: PA1; SW_PUSH_6mm; Digikey 2223-TS02-66-50-BK-160-LCR-D-ND
SW8: PA0; SW_PUSH_6mm; Digikey 2223-TS02-66-50-BK-160-LCR-D-ND

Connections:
GND: J1.2, J2.2, R9.1, R10.1, R11.1, R12.1, R13.1, R14.1, R15.1, R16.1, SW1.1, SW2.1, SW3.1, SW4.1, SW5.1, SW6.1, SW7.1, SW8.1
unnamed: D1.1 (K), R9.2
unnamed: D2.1 (K), R10.2
unnamed: D3.1 (K), R11.2
unnamed: D4.1 (K), R12.2
unnamed: D5.1 (K), R13.2
unnamed: D6.1 (K), R14.2
unnamed: D7.1 (K), R15.2
unnamed: D8.1 (K), R16.2
PA0: J1.4, R8.1, SW8.2
PA1: J1.6, R7.1, SW7.2
PA2: J1.8, R6.1, SW6.2
PA3: J1.10, R5.1, SW5.2
PA4: J1.9, R4.1, SW4.2
PA5: J1.7, R3.1, SW3.2
PA6: J1.5, R2.1, SW2.2
PA7: J1.3, R1.1, SW1.2
PB0: D8.2 (A), J2.4
PB1: D7.2 (A), J2.6
PB2: D6.2 (A), J2.8
PB3: D5.2 (A), J2.10
PB4: D4.2 (A), J2.9
PB5: D3.2 (A), J2.7
PB6: D2.2 (A), J2.5
PB7: D1.2 (A), J2.3
VCC: J1.1, J2.1, R1.2, R2.2, R3.2, R4.2, R5.2, R6.2, R7.2, R8.2

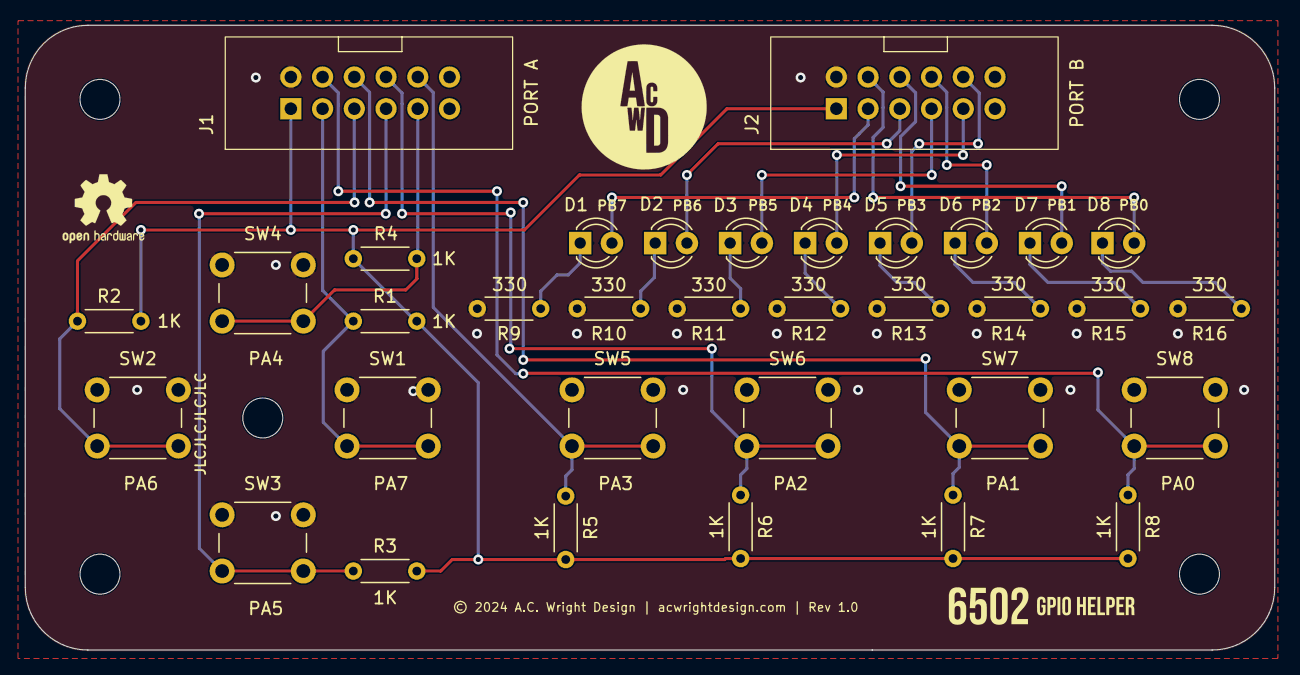
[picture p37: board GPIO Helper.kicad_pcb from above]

Board: 2 copper layers, 100.0 x 50.0 mm, 39 parts (0 on the bottom side), 26 nets.

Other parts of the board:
H1, H2, H3, H4, H5: MountingHole; MountingHole_3.2mm_M3

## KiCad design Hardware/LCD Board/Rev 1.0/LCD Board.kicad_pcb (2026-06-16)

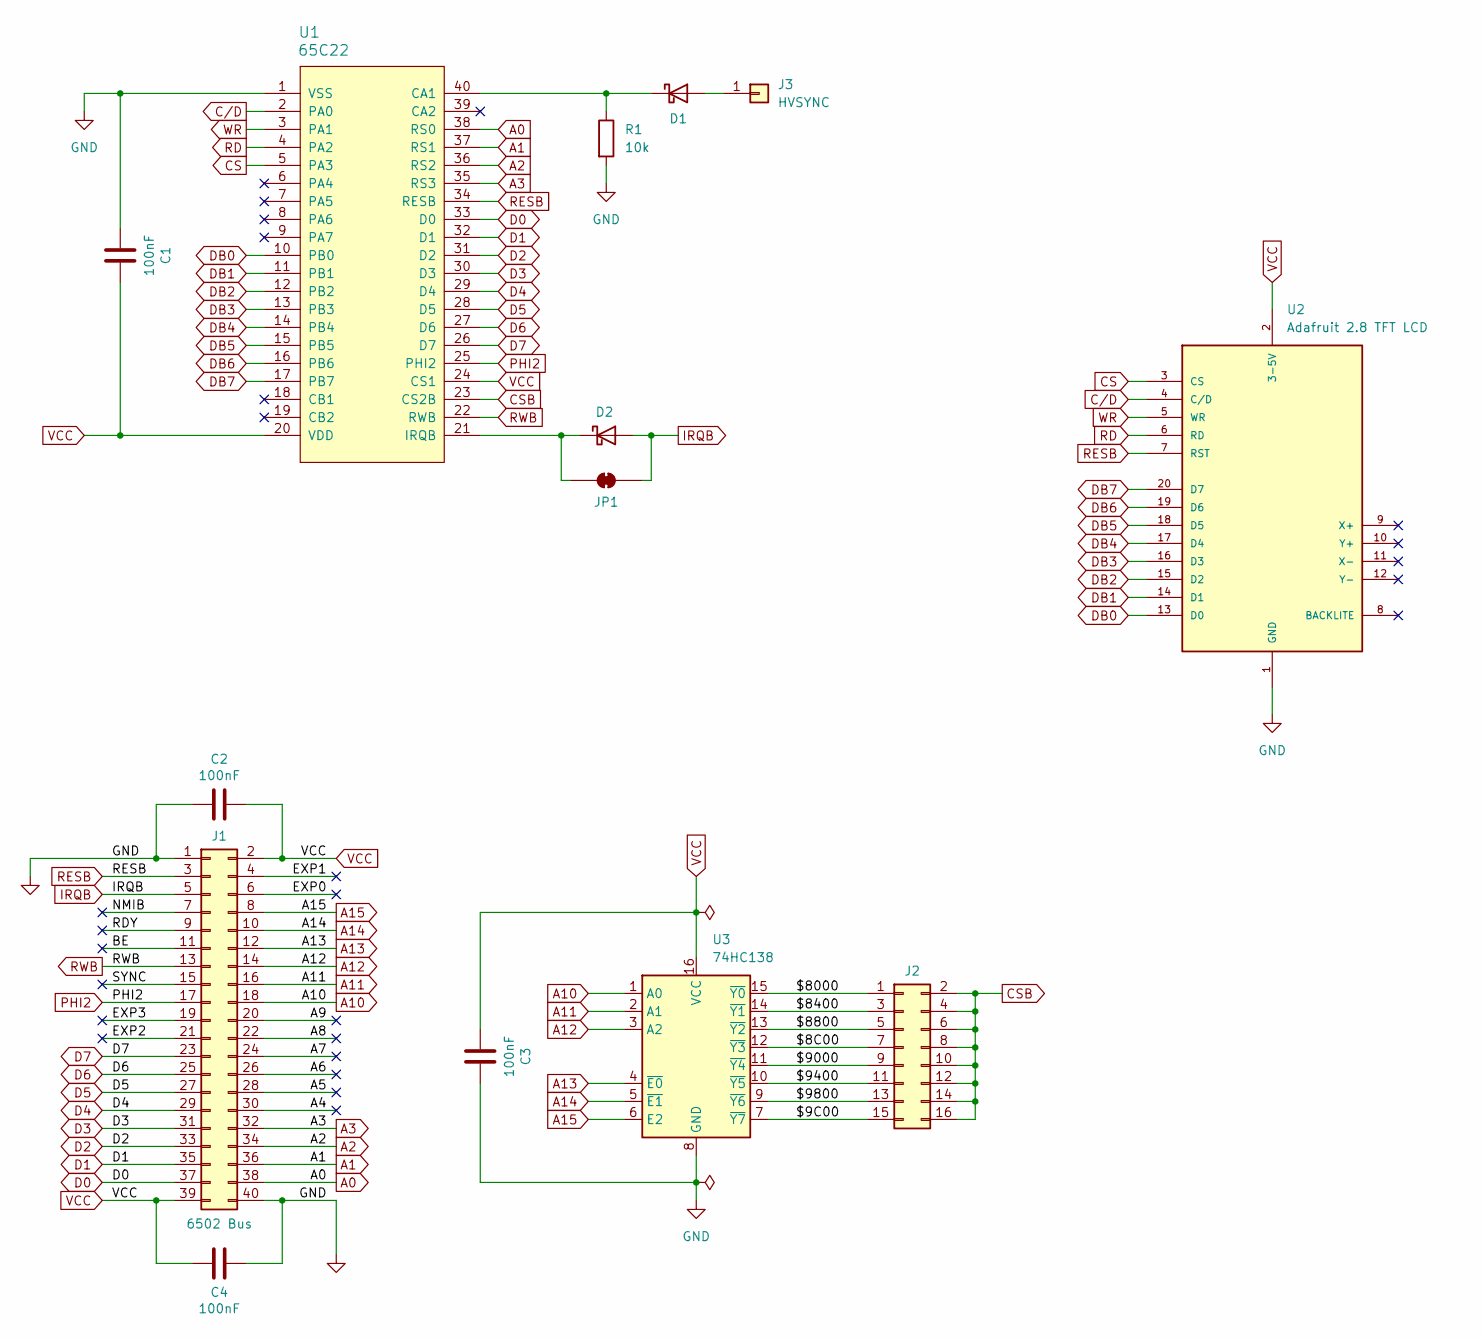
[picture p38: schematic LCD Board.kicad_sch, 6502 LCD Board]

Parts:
C1, C2, C3, C4: 100nF; C_Disc_D5.0mm_W2.5mm_P2.50mm
D1, D2: D_Schottky; D_DO-35_SOD27_P7.62mm_Horizontal
J1: 6502 Bus; 6502 Bus Connector
J2: Conn_02x08_Odd_Even; PinHeader_2x08_P2.54mm_Vertical
J3: HVSYNC; PinHeader_1x01_P2.54mm_Vertical
JP1: SolderJumper_2_Bridged; SolderJumper-2_P1.3mm_Bridged_RoundedPad1.0x1.5mm
R1: 10k; R_Axial_DIN0204_L3.6mm_D1.6mm_P5.08mm_Horizontal
U1: 65C22; DIP-40_W15.24mm_Socket_LongPads
U2: Adafruit 2.8 TFT LCD
U3: 74HC138; DIP-16_W7.62mm_Socket_LongPads

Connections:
/$8C00: J2.7, U3.12 (~Y3)
/$9C00: J2.15, U3.7 (~Y7)
/$8000: J2.1, U3.15 (~Y0)
/$8400: J2.3, U3.14 (~Y1)
/$8800: J2.5, U3.13 (~Y2)
/$9000: J2.9, U3.11 (~Y4)
/$9400: J2.11, U3.10 (~Y5)
/$9800: J2.13, U3.9 (~Y6)
/A4: J1.30
/A5: J1.28
/A6: J1.26
/A7: J1.24
/A8: J1.22
/A9: J1.20
/BE: J1.11
/EXP0: J1.6
/EXP1: J1.4
/EXP2: J1.21
/EXP3: J1.19
/NMIB: J1.7
/RDY: J1.9
/SYNC: J1.15
A0: J1.38, U1.38 (RS0)
A1: J1.36, U1.37 (RS1)
A2: J1.34, U1.36 (RS2)
A3: J1.32, U1.35 (RS3)
A10: J1.18, U3.1 (A0)
A11: J1.16, U3.2 (A1)
A12: J1.14, U3.3 (A2)
A13: J1.12, U3.4 (~E0)
A14: J1.10, U3.5 (~E1)
A15: J1.8, U3.6 (E2)
CS: U1.5 (PA3), U2.3 (CS)
CSB: J2.2, J2.4, J2.6, J2.8, J2.10, J2.12, J2.14, J2.16, U1.23 (CS2B)
C/D: U1.2 (PA0), U2.4 (C/D)
D0: J1.37, U1.33 (D0)
D1: J1.35, U1.32 (D1)
D2: J1.33, U1.31 (D2)
D3: J1.31, U1.30 (D3)
D4: J1.29, U1.29 (D4)
D5: J1.27, U1.28 (D5)
D6: J1.25, U1.27 (D6)
D7: J1.23, U1.26 (D7)
DB0: U1.10 (PB0), U2.13 (D0)
DB1: U1.11 (PB1), U2.14 (D1)
DB2: U1.12 (PB2), U2.15 (D2)
DB3: U1.13 (PB3), U2.16 (D3)
DB4: U1.14 (PB4), U2.17 (D4)
DB5: U1.15 (PB5), U2.18 (D5)
DB6: U1.16 (PB6), U2.19 (D6)
DB7: U1.17 (PB7), U2.20 (D7)
GND: C1.1, C2.2, C3.2, C4.1, J1.1, J1.40, R1.2, U1.1 (VSS), U2.1 (GND), U3.8 (GND)
IRQB: D2.2 (A), J1.5, JP1.2 (B)
unnamed: D1.2 (A), J3.1 (Pin_1_1)
unnamed: D1.1 (K), R1.1, U1.40 (CA1)
unnamed: D2.1 (K), JP1.1 (A), U1.21 (IRQB)
PHI2: J1.17, U1.25 (PHI2)
RD: U1.4 (PA2), U2.6 (RD)
RESB: J1.3, U1.34 (RESB), U2.7 (RST)
RWB: J1.13, U1.22 (RWB)
VCC: C1.2, C2.1, C3.1, C4.2, J1.2, J1.39, U1.20 (VDD), U1.24 (CS1), U2.2 (3-5V), U3.16 (VCC)
WR: U1.3 (PA1), U2.5 (WR)

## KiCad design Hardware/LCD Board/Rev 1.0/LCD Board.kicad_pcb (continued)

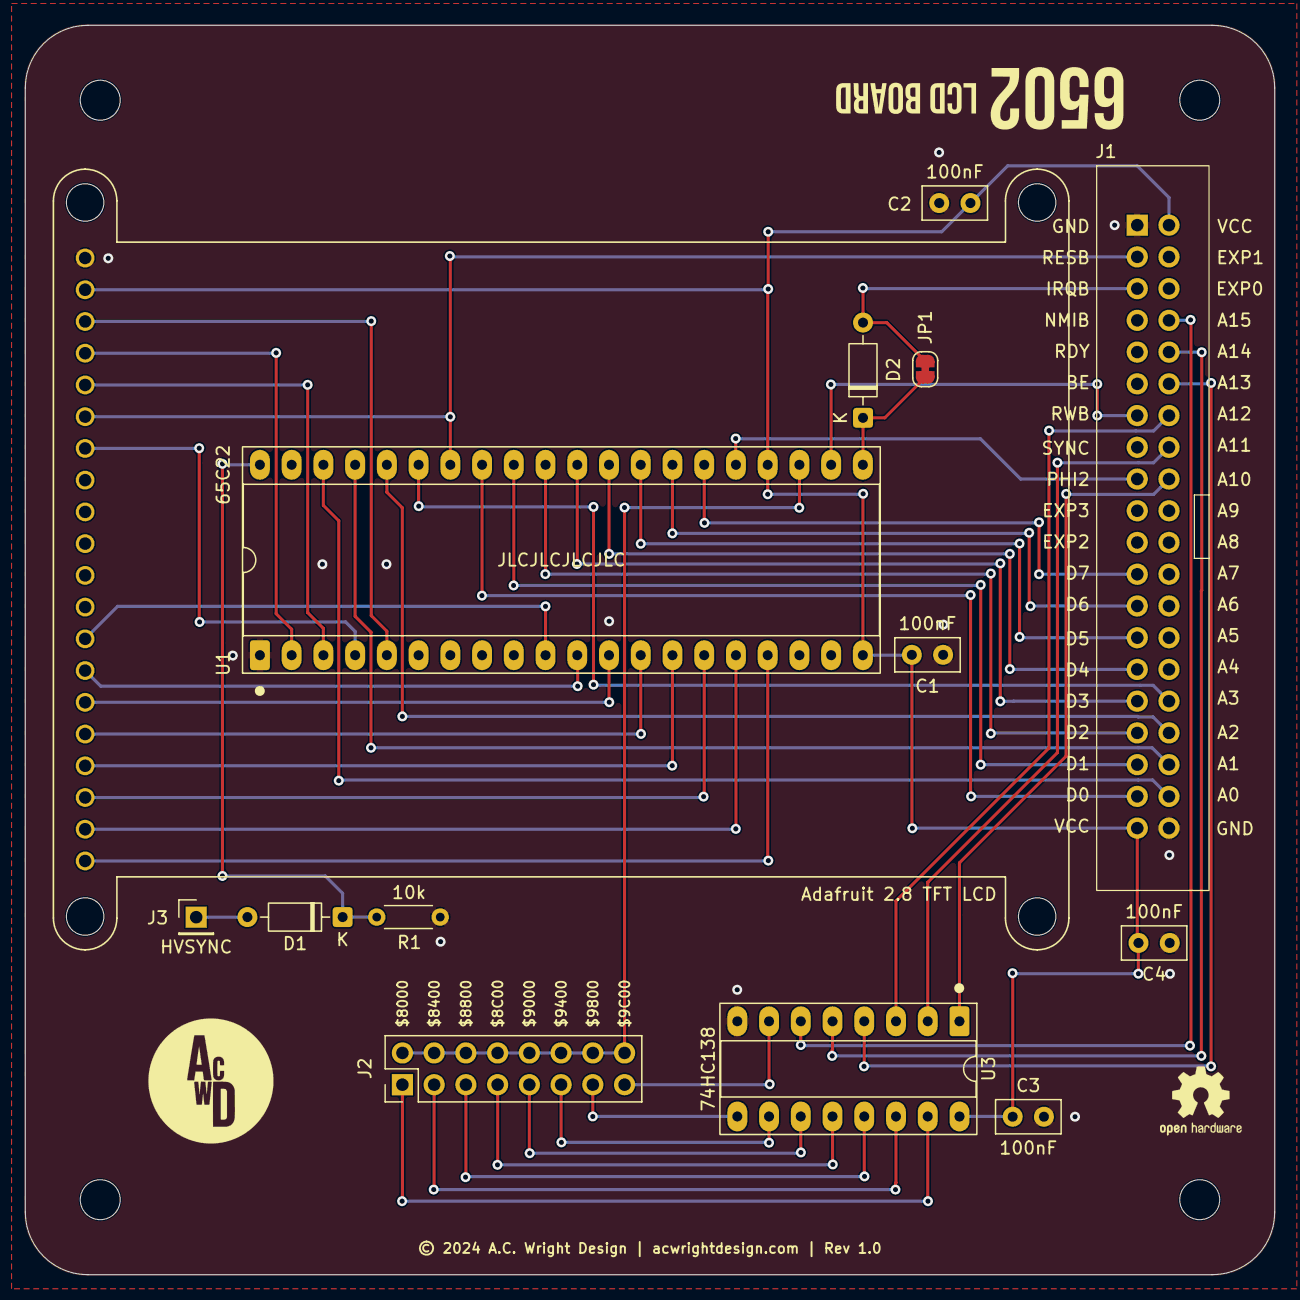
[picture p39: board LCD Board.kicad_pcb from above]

Board: 2 copper layers, 100.0 x 100.0 mm, 18 parts (0 on the bottom side), 48 nets.

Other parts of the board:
H1, H2, H3, H4: MountingHole; MountingHole_3.2mm_M3

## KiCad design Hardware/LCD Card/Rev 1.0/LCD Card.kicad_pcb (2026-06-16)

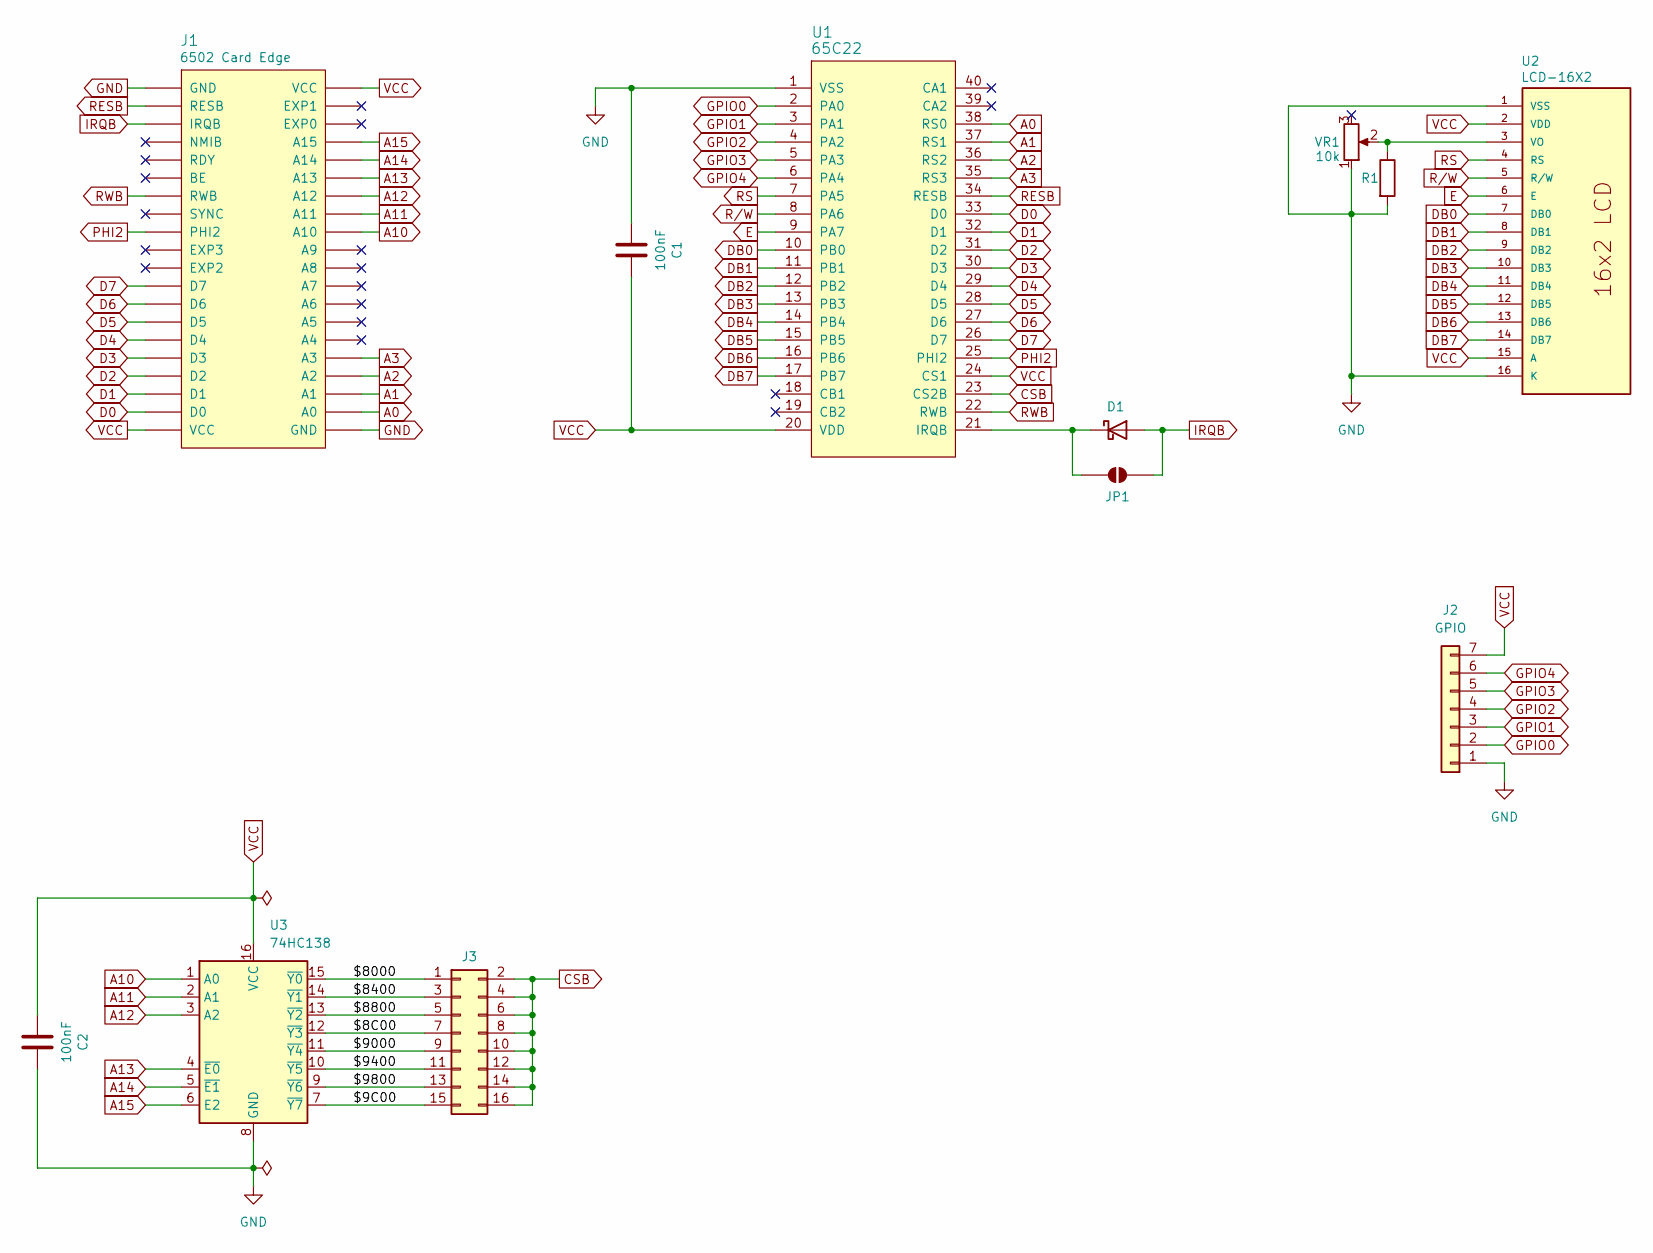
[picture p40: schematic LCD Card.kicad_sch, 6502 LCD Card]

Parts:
C1, C2: 100nF; C_0805_2012Metric; LCSC C49678
D1: D_Schottky; D_DO-35_SOD27_P7.62mm_Horizontal
J1: 6502 Card Edge
J2: GPIO; PinHeader_1x07_P2.54mm_Horizontal
J3: Conn_02x08_Odd_Even; PinHeader_2x08_P2.54mm_Vertical
JP1: SolderJumper_2_Bridged; SolderJumper-2_P1.3mm_Open_RoundedPad1.0x1.5mm
R1: R; R_Axial_DIN0204_L3.6mm_D1.6mm_P5.08mm_Horizontal
U1: 65C22; DIP-40_W15.24mm_Socket_LongPads
U2: LCD-16X2
U3: 74HC138; SOIC-16_3.9x9.9mm_P1.27mm; LCSC C5602
VR1: 10k; 3386F-1-103LF; Digikey 3386F-103LF-ND

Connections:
/$8C00: J3.7, U3.12 (~Y3)
/$9C00: J3.15, U3.7 (~Y7)
/$8000: J3.1, U3.15 (~Y0)
/$8400: J3.3, U3.14 (~Y1)
/$8800: J3.5, U3.13 (~Y2)
/$9000: J3.9, U3.11 (~Y4)
/$9400: J3.11, U3.10 (~Y5)
/$9800: J3.13, U3.9 (~Y6)
A0: J1.A0, U1.38 (RS0)
A1: J1.A1, U1.37 (RS1)
A2: J1.A2, U1.36 (RS2)
A3: J1.A3, U1.35 (RS3)
A10: J1.A10, U3.1 (A0)
A11: J1.A11, U3.2 (A1)
A12: J1.A12, U3.3 (A2)
A13: J1.A13, U3.4 (~E0)
A14: J1.A14, U3.5 (~E1)
A15: J1.A15, U3.6 (E2)
CSB: J3.2, J3.4, J3.6, J3.8, J3.10, J3.12, J3.14, J3.16, U1.23 (CS2B)
D0: J1.D0, U1.33 (D0)
D1: J1.D1, U1.32 (D1)
D2: J1.D2, U1.31 (D2)
D3: J1.D3, U1.30 (D3)
D4: J1.D4, U1.29 (D4)
D5: J1.D5, U1.28 (D5)
D6: J1.D6, U1.27 (D6)
D7: J1.D7, U1.26 (D7)
DB0: U1.10 (PB0), U2.7 (DB0)
DB1: U1.11 (PB1), U2.8 (DB1)
DB2: U1.12 (PB2), U2.9 (DB2)
DB3: U1.13 (PB3), U2.10 (DB3)
DB4: U1.14 (PB4), U2.11 (DB4)
DB5: U1.15 (PB5), U2.12 (DB5)
DB6: U1.16 (PB6), U2.13 (DB6)
DB7: U1.17 (PB7), U2.14 (DB7)
E: U1.9 (PA7), U2.6 (E)
GND: C1.1, C2.2, J1.GND, J2.1, R1.2, U1.1 (VSS), U2.1 (VSS), U2.16 (K), U3.8 (GND), VR1.1
GPIO0: J2.2, U1.2 (PA0)
GPIO1: J2.3, U1.3 (PA1)
GPIO2: J2.4, U1.4 (PA2)
GPIO3: J2.5, U1.5 (PA3)
GPIO4: J2.6, U1.6 (PA4)
IRQB: D1.2 (A), J1.IRQB, JP1.2 (B)
unnamed: D1.1 (K), JP1.1 (A), U1.21 (IRQB)
unnamed: R1.1, U2.3 (VO), VR1.2
PHI2: J1.PHI2, U1.25 (PHI2)
RESB: J1.RESB, U1.34 (RESB)
RS: U1.7 (PA5), U2.4 (RS)
RWB: J1.RWB, U1.22 (RWB)
R/W: U1.8 (PA6), U2.5 (R/W)
VCC: C1.2, C2.1, J1.VCC, J2.7, U1.20 (VDD), U1.24 (CS1), U2.2 (VDD), U2.15 (A), U3.16 (VCC)

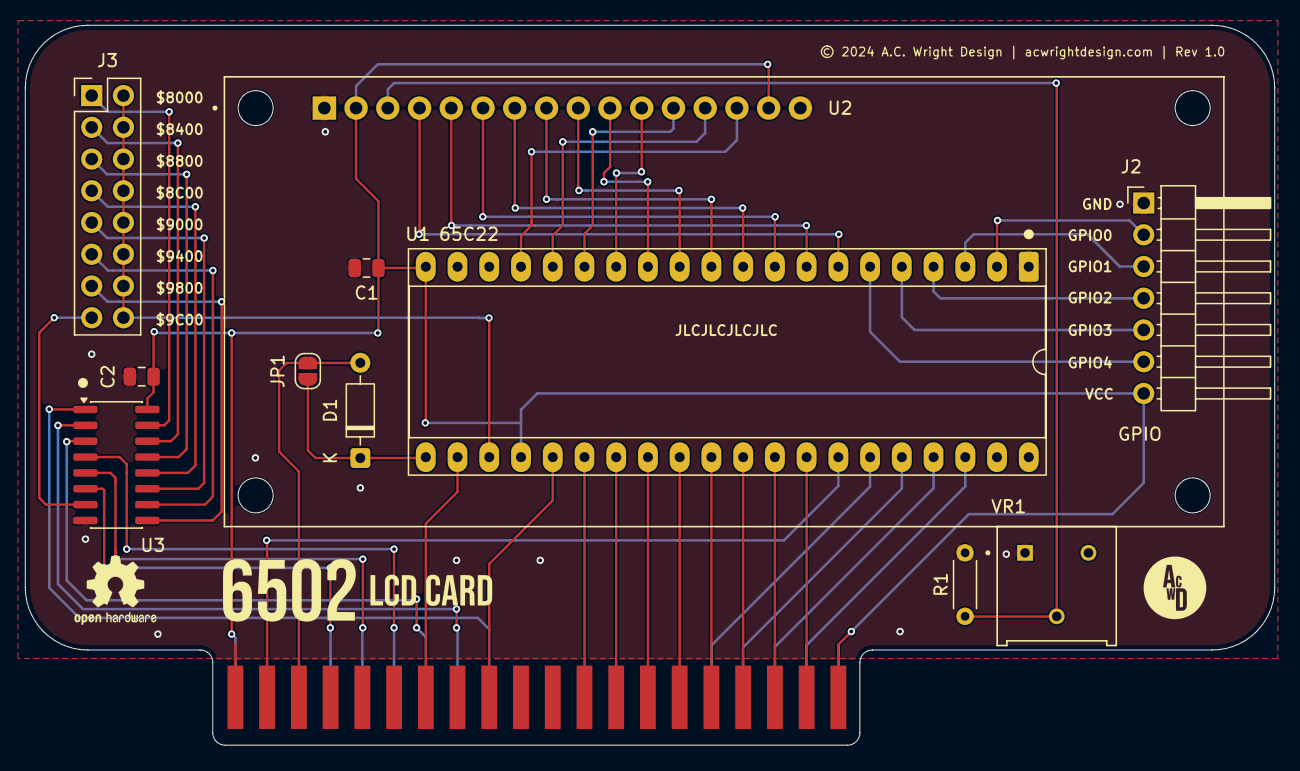
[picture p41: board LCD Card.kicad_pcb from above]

Board: 2 copper layers, 100.0 x 57.6 mm, 12 parts (0 on the bottom side), 51 nets.

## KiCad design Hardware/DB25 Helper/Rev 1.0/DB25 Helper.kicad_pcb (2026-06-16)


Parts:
J1: PORT A; 6502 GPIO Connector
J2: PORT B; 6502 GPIO Connector
J3: KEYBOARD; DSUB-25_Pins_Horizontal_P2.77x2.84mm_EdgePinOffset7.70mm_Ho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; MPN D25P33E4GX00LF; Digikey 609-1505-ND

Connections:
CA1: J1.11, J3.19
CA2: J1.12, J3.6
CB1: J2.11, J3.20
CB2: J2.12, J3.8
GND: J1.2, J2.2, J3.7, J3.14, J3.25, J3.SH (PAD)
PA0: J1.4, J3.2
PA1: J1.6, J3.15
PA2: J1.8, J3.3
PA3: J1.10, J3.16
PA4: J1.9, J3.4
PA5: J1.7, J3.17
PA6: J1.5, J3.5
PA7: J1.3, J3.18
PB0: J2.4, J3.12
PB1: J2.6, J3.24
PB2: J2.8, J3.11
PB3: J2.10, J3.23
PB4: J2.9, J3.10
PB5: J2.7, J3.22
PB6: J2.5, J3.9
PB7: J2.3, J3.21
VCC: J1.1, J2.1, J3.1, J3.13


Board: 2 copper layers, 100.0 x 50.0 mm, 7 parts (0 on the bottom side), 22 nets.

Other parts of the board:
H1, H2, H3, H4: MountingHole; MountingHole_3.2mm_M3

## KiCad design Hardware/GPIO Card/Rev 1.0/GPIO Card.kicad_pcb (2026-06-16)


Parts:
C1, C2: 100nF; C_0805_2012Metric; LCSC C49678
D1: D_Schottky; D_DO-35_SOD27_P7.62mm_Horizontal
J1: 6502 Card Edge
J2: Conn_02x08_Odd_Even; PinHeader_2x08_P2.54mm_Vertical
J3: PORT A; 6502 GPIO Connector
J4: PORT B; 6502 GPIO Connector
JP1: SolderJumper_2_Bridged; SolderJumper-2_P1.3mm_Bridged_RoundedPad1.0x1.5mm
U1: 74HC138; SOIC-16_3.9x9.9mm_P1.27mm; LCSC C5602
U2: 65C22; DIP-40_W15.24mm_Socket_LongPads

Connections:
/$8C00: J2.7, U1.12 (~Y3)
/$9C00: J2.15, U1.7 (~Y7)
/$8000: J2.1, U1.15 (~Y0)
/$8400: J2.3, U1.14 (~Y1)
/$8800: J2.5, U1.13 (~Y2)
/$9000: J2.9, U1.11 (~Y4)
/$9400: J2.11, U1.10 (~Y5)
/$9800: J2.13, U1.9 (~Y6)
A0: J1.A0, U2.38 (RS0)
A1: J1.A1, U2.37 (RS1)
A2: J1.A2, U2.36 (RS2)
A3: J1.A3, U2.35 (RS3)
A10: J1.A10, U1.1 (A0)
A11: J1.A11, U1.2 (A1)
A12: J1.A12, U1.3 (A2)
A13: J1.A13, U1.4 (~E0)
A14: J1.A14, U1.5 (~E1)
A15: J1.A15, U1.6 (E2)
CA1: J3.11, U2.40 (CA1)
CA2: J3.12, U2.39 (CA2)
CB1: J4.11, U2.18 (CB1)
CB2: J4.12, U2.19 (CB2)
CSB: J2.2, J2.4, J2.6, J2.8, J2.10, J2.12, J2.14, J2.16, U2.23 (CS2B)
D0: J1.D0, U2.33 (D0)
D1: J1.D1, U2.32 (D1)
D2: J1.D2, U2.31 (D2)
D3: J1.D3, U2.30 (D3)
D4: J1.D4, U2.29 (D4)
D5: J1.D5, U2.28 (D5)
D6: J1.D6, U2.27 (D6)
D7: J1.D7, U2.26 (D7)
GND: C1.2, C2.1, J1.GND, J3.2, J4.2, U1.8 (GND), U2.1 (VSS)
IRQB: D1.2 (A), J1.IRQB, JP1.2 (B)
unnamed: D1.1 (K), JP1.1 (A), U2.21 (IRQB)
PA0: J3.4, U2.2 (PA0)
PA1: J3.6, U2.3 (PA1)
PA2: J3.8, U2.4 (PA2)
PA3: J3.10, U2.5 (PA3)
PA4: J3.9, U2.6 (PA4)
PA5: J3.7, U2.7 (PA5)
PA6: J3.5, U2.8 (PA6)
PA7: J3.3, U2.9 (PA7)
PB0: J4.4, U2.10 (PB0)
PB1: J4.6, U2.11 (PB1)
PB2: J4.8, U2.12 (PB2)
PB3: J4.10, U2.13 (PB3)
PB4: J4.9, U2.14 (PB4)
PB5: J4.7, U2.15 (PB5)
PB6: J4.5, U2.16 (PB6)
PB7: J4.3, U2.17 (PB7)
PHI2: J1.PHI2, U2.25 (PHI2)
RESB: J1.RESB, U2.34 (RESB)
RWB: J1.RWB, U2.22 (RWB)
VCC: C1.1, C2.2, J1.VCC, J3.1, J4.1, U1.16 (VCC), U2.20 (VDD), U2.24 (CS1)


Board: 2 copper layers, 100.0 x 57.6 mm, 10 parts (0 on the bottom side), 54 nets.

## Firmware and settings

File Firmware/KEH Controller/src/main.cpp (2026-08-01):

#define CIRCULAR_BUFFER_INT_SAFE

#include <Arduino.h>
#include <CircularBuffer.hpp>

// ============================================================================
// Keyboard Matrix Mapping 
// ============================================================================
// Rows: PA0-PA7 (VIA Port A)
// Columns: PB0-PB7 (VIA Port B)
//
//      PB0    PB1    PB2    PB3    PB4    PB5    PB6    PB7
// PA0:  `      1      2      3      4      5      6      7
// PA1:  8      9      0      -      =      BS     ESC    TAB
// PA2:  q      w      e      r      t      y      u      i
// PA3:  o      p      [      ]      \      INS    CAPS   a
// PA4:  s      d      f      g      h      j      k      l
// PA5:  ;      '      ENTER  DEL    SHIFT  z      x      c
// PA6:  v      b      n      m      ,      .      /      UP
// PA7:  CTRL   GUI    ALT    SPACE  FN     LEFT   DOWN   RIGHT
//
// Notes:
// - BS = Backspace (0x08), ESC = Escape (0x1B), TAB (0x09)
// - INS = Insert (0x1A), DEL = Delete (0x7F), ENTER (0x0D)
// - Arrow keys: UP (0x1E), LEFT (0x1C), DOWN (0x1F), RIGHT (0x1D)
// - Function keys F1-F10 are mapped as FN + number keys 1-0
// ============================================================================

// ATMega1284 PORT A / 6522 VIA PORT A
#define VIA_PA0 24
#define VIA_PA1 25
#define VIA_PA2 26
#define VIA_PA3 27
#define VIA_PA4 28
#define VIA_PA5 29
#define VIA_PA6 30
#define VIA_PA7 31

// ATMega1284 PORT B / 6522 VIA PORT B
#define VIA_PB0 0
#define VIA_PB1 1
#define VIA_PB2 2
#define VIA_PB3 3
#define VIA_PB4 4
#define VIA_PB5 5
#define VIA_PB6 6
#define VIA_PB7 7

#define VIA_CA1 8
#define VIA_CA2 9
#define PS2CLK  10
#define PS2DATA 11
#define VIA_CB1 12
#define VIA_CB2 13

#define BUFFER_SIZE 16

CircularBuffer<uint8_t, BUFFER_SIZE> ps2Buffer;  // Buffer for PS/2 keyboard data
CircularBuffer<uint8_t, BUFFER_SIZE> matrixBuffer;  // Buffer for matrix keyboard data

// PS/2 keyboard state
bool ps2Enabled = false;
bool shiftPressed = false;
bool ctrlPressed = false;
bool breakCodeNext = false;
bool extendedCodeNext = false;

// Matrix keyboard state
bool matrixEnabled = false;
bool matrixShiftPressed = false;
bool matrixCtrlPressed = false;

// Matrix key debouncing
uint8_t matrixKeyState[8][8] = {0};  // Current state of each key
uint8_t matrixKeyLast[8][8] = {0};   // Last state of each key
unsigned long matrixLastScan = 0;
uint8_t matrixScanRow = 0;   // Next row to scan; an interrupted sweep resumes here
#define MATRIX_SCAN_INTERVAL 10  // Scan every 10ms
#define MATRIX_DEBOUNCE_COUNT 2  // Key must be stable for 2 scans

// ============================================================================
// Joystick State
// ============================================================================
// The two sticks share the sixteen VIA port lines with the key matrix:
// JOYSTICK A on PA0-PA7 (the matrix rows) and JOYSTICK B on PB0-PB7 (the
// columns). Every signal is active low -- the switches close to ground -- so an
// untouched stick leaves its lines pulled high.
//
// Nothing about the sticks is sent to the 6502 from here. The 6502 reads them
// itself: Kernal KBDisable takes both encoders offline, this ATmega goes
// high-impedance, and the 6502 reads the raw ports with the sticks the only
// things pulling on them. That is the same arrangement a C64 has, it needs no
// wire protocol, and it is the only way both sticks can be read reliably --
// anything this encoder drives onto a port is fighting the switches wired to
// those same eight lines.
//
// What the firmware does need is to know which lines a stick is holding down.
// A held signal pins its line low for as long as it is held, and every key
// along that row or column then reads as pressed. These masks keep the sticks
// out of the matrix scan.
uint8_t joyRowMask = 0;   // PA lines JOYSTICK A is holding low -> unscannable rows
uint8_t joyColMask = 0;   // PB lines JOYSTICK B is holding low -> unscannable columns

void onInterrupt();
void enablePS2();
void disablePS2();
void enableMatrix();
void disableMatrix();
void ps2ToAscii(uint8_t scancode);
bool scanMatrix();
uint8_t mapMatrixToAscii(uint8_t row, uint8_t col);
void serviceEncoderEnables();
bool settleBetweenCharacters();
bool matrixRowConflict();
bool writePortA(uint8_t value);
bool writePortB(uint8_t value);
void sampleJoystickMasks();

// ============================================================================
// VIA Port Access
// ============================================================================
// On the MightyCore "standard" pinout VIA_PA0-PA7 are D24-D31, which is exactly
// ATmega PORTA bits 0-7, and VIA_PB0-PB7 are D0-D7, which is exactly PORTB bits
// 0-7. Nothing else on this board lives on either register, so the whole port
// can be manipulated in a single instruction.
//
// That matters in two places. The encoder must let go of a port within 100 us
// of being asked, because that is how the 6502 reads the joysticks at all and
// Kernal KBDisable waits exactly that long before reading. So the release path
// has to be effectively instantaneous, and the scan loop has to be able to
// check for a release request without paying ~4 us per Arduino call.
// Everything that is not on that path keeps using pinMode/digitalRead.
//
// If the VIA_Px pin defines above ever change, these must change with them.

// CA2 (PD1) and CB2 (PD5) are the 6502 asking for a port back, active high.
#define CA2_RELEASE_REQUESTED() (PIND & _BV(PD1))
#define CB2_RELEASE_REQUESTED() (PIND & _BV(PD5))

// True when the 6502 has asked an encoder that is currently enabled -- and so
// currently driving a port -- to release it.
static inline bool releaseRequested() {
  return (matrixEnabled && CB2_RELEASE_REQUESTED()) ||
         (ps2Enabled && CA2_RELEASE_REQUESTED());
}

// ============================================================================
// Keyboard Matrix to ASCII Mapping Table
// ============================================================================
// Maps each matrix position [row][col] to its base ASCII code (no modifiers)
// Special values: 0xFF = no key, 0xFE = modifier key (handled separately)
const uint8_t matrixMap[8][8] PROGMEM = {
  // PA0/Row 0: PB0    PB1    PB2    PB3    PB4    PB5    PB6    PB7
  {             0x60,  0x31,  0x32,  0x33,  0x34,  0x35,  0x36,  0x37 },  // ` 1 2 3 4 5 6 7
  // PA1/Row 1
  {             0x38,  0x39,  0x30,  0x2D,  0x3D,  0x08,  0x1B,  0x09 },  // 8 9 0 - = BS ESC TAB
  // PA2/Row 2
  {             0x51,  0x57,  0x45,  0x52,  0x54,  0x59,  0x55,  0x49 },  // Q W E R T Y U I
  // PA3/Row 3
  {             0x4F,  0x50,  0x5B,  0x5D,  0x5C,  0x1A,  0xFF,  0x41 },  // O P [ ] \ INS (ign) A
  // PA4/Row 4
  {             0x53,  0x44,  0x46,  0x47,  0x48,  0x4A,  0x4B,  0x4C },  // S D F G H J K L
  // PA5/Row 5
  {             0x3B,  0x27,  0x0D,  0x7F,  0xFE,  0x5A,  0x58,  0x43 },  // ; ' ENTER DEL SHIFT Z X C
  // PA6/Row 6
  {             0x56,  0x42,  0x4E,  0x4D,  0x2C,  0x2E,  0x2F,  0x1E },  // V B N M , . / UP
  // PA7/Row 7
  {             0xFE,  0xFF,  0xFF,  0x20,  0xFF,  0x1C,  0x1F,  0x1D }   // CTRL (ign) (ign) SPACE (ign) LEFT DOWN RIGHT
};

void setup() {
  pinMode(VIA_CA1, OUTPUT);
  pinMode(VIA_CA2, INPUT_PULLUP);
  pinMode(VIA_CB1, OUTPUT);
  pinMode(VIA_CB2, INPUT_PULLUP);
  pinMode(PS2CLK, INPUT_PULLUP);
  pinMode(PS2DATA, INPUT_PULLUP);

  digitalWrite(VIA_CA1, HIGH);
  digitalWrite(VIA_CB1, HIGH);
  
  attachInterrupt(digitalPinToInterrupt(PS2CLK), onInterrupt, FALLING);
}

void loop() {
  // Bring both encoders into whatever state CA2/CB2 are asking for
  serviceEncoderEnables();

  // Scan matrix keyboard if enabled. A scan that reports back false was
  // abandoned because the 6502 asked for a port, so service that immediately
  // and start a fresh pass rather than running the output blocks first.
  if (matrixEnabled && !scanMatrix()) {
    serviceEncoderEnables();
    return;
  }

  // Handle PS/2 keyboard output on Port A. The character is only consumed once
  // it has actually been strobed, so one abandoned mid-write cannot be lost.
  if (ps2Enabled && !ps2Buffer.isEmpty()) {
    if (!writePortA(ps2Buffer.first())) {
      serviceEncoderEnables();
      return;
    }
    ps2Buffer.shift();
    if (!settleBetweenCharacters()) {
      serviceEncoderEnables();
      return;
    }
  }

  // Handle matrix keyboard output on Port B
  if (matrixEnabled && !matrixBuffer.isEmpty() && !matrixRowConflict()) {
    if (!writePortB(matrixBuffer.first())) {
      serviceEncoderEnables();
      return;
    }
    matrixBuffer.shift();
    if (!settleBetweenCharacters()) {
      serviceEncoderEnables();
      return;
    }
  }
}

// Poll CA2/CB2 and bring each encoder into the state the 6502 is asking for.
// Called at the top of loop() and again the moment any longer-running section
// notices a release request, so a port is never held past its budget just
// because the firmware was busy elsewhere.
void serviceEncoderEnables() {
  // Check PS/2 enable/disable (CA2)
  int ps2EnableState = digitalRead(VIA_CA2);
  if (ps2EnableState == LOW && !ps2Enabled) {
    enablePS2();
  } else if (ps2EnableState == HIGH && ps2Enabled) {
    disablePS2();
  }

  // Check matrix enable/disable (CB2)
  int matrixEnableState = digitalRead(VIA_CB2);
  if (matrixEnableState == LOW && !matrixEnabled) {
    enableMatrix();
  } else if (matrixEnableState == HIGH && matrixEnabled) {
    disableMatrix();
  }
}

// The settle gap the 6502 needs between strobes. Spent in short slices with a
// release check between each, rather than blocking for the whole 100 us, so a
// request arriving just after a strobe is still answered on time. Returns false
// if one arrived, in which case the caller must stop what it is doing.
bool settleBetweenCharacters() {
  for (uint8_t i = 0; i < 10; i++) {
    if (releaseRequested()) {
      return false;
    }
    delayMicroseconds(10);
  }
  return true;
}

// When two keys on the same row are held simultaneously, their switches bridge
// Port B columns through the shared row wire.  This corrupts anything driven on
// Port B because the ATmega's output drivers fight each other through that
// path.  Output is deferred until no row has multiple pressed keys.
bool matrixRowConflict() {
  for (uint8_t row = 0; row < 8; row++) {
    uint8_t count = 0;
    for (uint8_t col = 0; col < 8; col++) {
      if (matrixKeyState[row][col] >= MATRIX_DEBOUNCE_COUNT) {
        if (++count >= 2) {
          return true;
        }
      }
    }
  }
  return false;
}

// Drive a byte onto Port A and strobe CA1. Matrix scanning parks the row lines
// as inputs, so the direction has to be re-asserted on every write.
//
// Returns false if the 6502 asked for the port before the strobe went out, in
// which case nothing was signalled and the caller must keep the byte queued.
// This matters more than it looks: BASIC evaluating JOY() disables the encoders
// every time, so a release landing in the middle of a character write is a
// routine event rather than a rarity. Strobing a port that is about to be
// released would leave the 6502's ISR reading joystick lines and buffering them
// as a keystroke.
bool writePortA(uint8_t value) {
  // Nothing has been committed to the wire yet, so bail before touching the
  // port at all if the 6502 has already asked for it
  if (releaseRequested()) {
    return false;
  }

  // Value before direction: while the port is still an input this only sets
  // pullups, so the byte is never half-driven on its way out
  PORTA = value;
  DDRA = 0xFF;

  if (releaseRequested()) {
    return false;
  }

  digitalWrite(VIA_CA1, LOW); // Signal that data is ready
  delayMicroseconds(5);
  digitalWrite(VIA_CA1, HIGH);
  return true;
}

// Drive a byte onto Port B and strobe CB1. Port A (the row lines) is parked
// high-impedance first, so a single pressed key cannot short a driven column
// back into a driven row through its switch. Returns false without strobing if
// the 6502 asked for the port first -- see writePortA.
bool writePortB(uint8_t value) {
  if (releaseRequested()) {
    return false;
  }

  // Park the row lines as pulled-up inputs first
  DDRA = 0x00;
  PORTA = 0xFF;

  // Value before direction -- see writePortA
  PORTB = value;
  DDRB = 0xFF;

  if (releaseRequested()) {
    return false;
  }

  digitalWrite(VIA_CB1, LOW); // Signal that data is ready
  delayMicroseconds(5);
  digitalWrite(VIA_CB1, HIGH);
  return true;
}

void enablePS2() {
  ps2Enabled = true;

  // Set Port A as output for PS/2 data. PORTA already reads 0xFF from the
  // released state, so the lines idle high rather than briefly presenting
  // whatever was last driven.
  DDRA = 0xFF;
}

void disablePS2() {
  ps2Enabled = false;

  // Release Port A unconditionally: CA2 going high is the 6502 asking for the
  // port, and it is not conditional on what the matrix is doing. scanMatrix()
  // drives the row lines itself and parks them between passes, so there is
  // nothing here worth preserving for it -- whereas the old `if (!matrixEnabled)`
  // guard meant that with the matrix enabled this path never let go of Port A
  // at all.
  //
  // Parked with the internal pullups on, not bare, because this is exactly the
  // state the 6502 reads the joysticks in. Only the ACE Board carries the 1k
  // port pullups itself; on COB and VCS they arrive with a helper board, so a
  // port with nothing fitted would otherwise float and read as noise instead of
  // as an untouched stick. ~30k is far too weak to fight a joystick switch, or
  // a cartridge driving its own matrix rows.
  //
  // Straight at the registers: this is the tail of the release path the 6502
  // waits on, and eight pinMode() calls would add ~36 us to it for no reason.
  DDRA = 0x00;
  PORTA = 0xFF;
}

void enableMatrix() {
  matrixEnabled = true;

  // Port B carries column reading and data output; idle driving high
  PORTB = 0xFF;
  DDRB = 0xFF;

  // Port A is left as pulled-up inputs rather than driven. scanMatrix() takes
  // it a row at a time and writePortB() parks it, so nothing here needs it as
  // an output -- and driving it would put either all rows high against a
  // joystick holding one low, or all rows low against the columns.
  if (!ps2Enabled) {
    DDRA = 0x00;
    PORTA = 0xFF;
  }

  // Start a fresh sweep rather than resuming one abandoned before the matrix
  // was last disabled
  matrixScanRow = 0;
}

void disableMatrix() {
  matrixEnabled = false;

  // Release Port B, parked with the internal pullups on so the 6502 reads an
  // untouched stick as all-ones even on a board with no external pullups
  // fitted, and straight at the registers so the release is immediate (see
  // disablePS2 for both).
  DDRB = 0x00;
  PORTB = 0xFF;

  // Release Port A too if PS/2 is not using it
  if (!ps2Enabled) {
    DDRA = 0x00;
    PORTA = 0xFF;
  }
}

// ============================================================================
// Matrix Keyboard Scanning
// ============================================================================

// Put the ports back where the rest of the firmware expects them when a scan is
// abandoned part way through. The row lines are only ever driven during a scan
// so they are always safe to drop; the columns are only released if Port B is
// what the 6502 actually asked for, otherwise they go back to idling high.
static inline void abandonScanPorts() {
  DDRA = 0x00;    // Rows -> input, pullups on
  PORTA = 0xFF;

  if (CB2_RELEASE_REQUESTED()) {
    DDRB = 0x00;  // Columns -> input, pullups on; the 6502 wants Port B
    PORTB = 0xFF;
  } else {
    PORTB = 0xFF; // Columns -> back to driving idle high
    DDRB = 0xFF;
  }
}

// Scan the keyboard matrix for key presses. Returns false if the sweep was
// abandoned because the 6502 asked for a port back, in which case the caller
// must service that before doing anything else.
bool scanMatrix() {
  // An abandoned sweep resumes from the row it stopped on rather than starting
  // over. That matters because the 6502 now takes the ports every time BASIC
  // evaluates JOY(): a tight polling loop would restart the sweep indefinitely
  // and no keystroke would ever be detected. Resuming also keeps the debounce
  // arithmetic exact -- still one update per key per completed sweep, however
  // many pieces the sweep ended up in.
  if (matrixScanRow == 0) {
    // Throttle the *start* of a sweep to MATRIX_SCAN_INTERVAL
    unsigned long currentTime = millis();
    if (currentTime - matrixLastScan < MATRIX_SCAN_INTERVAL) {
      return true;
    }
    matrixLastScan = currentTime;
  }

  // Phase 1: Scan all rows, update debounce state only.
  //
  // Row and column bits are carried as rolling masks rather than recomputed as
  // (1 << n) each time. The AVR has no barrel shifter, so a variable shift
  // compiles to a loop -- and one inside the eight-column loop cost ~30 us per
  // row, which would have dominated the release latency this whole section
  // exists to bound.
  uint8_t rowBit = (uint8_t)(1 << matrixScanRow);

  for (uint8_t row = matrixScanRow; row < 8; row++, rowBit <<= 1) {
    // Give the port up the moment the 6502 asks for it instead of finishing the
    // sweep first -- this is what bounds the release latency Kernal KBDisable
    // waits on. The checks are spread through the row so that no single stretch
    // of Arduino pin calls can run long between two of them.
    if (releaseRequested()) { matrixScanRow = row; abandonScanPorts(); return false; }

    // A row whose PA line JOYSTICK A is holding low reads as every key on that
    // row being pressed. Skip those rows rather than believe them -- this is
    // where the phantom keystrokes came from.
    if (joyRowMask & rowBit) {
      continue;
    }

    // Drive only the active row LOW; all others high-Z with their pullups off,
    // so no current leaks through pressed keys on inactive rows (ghosting).
    // PORT before DDR, always: enabling the driver first would briefly put the
    // previous contents of PORTA onto lines a joystick may be holding low.
    PORTA = 0x00;
    DDRA = rowBit;

    if (releaseRequested()) { matrixScanRow = row; abandonScanPorts(); return false; }

    // Columns to inputs with pullups for reading
    DDRB = 0x00;
    PORTB = 0xFF;

    // Small delay to let signals stabilize. Sized for the weak case -- a port
    // with no external pullup fitted, charging the bus through the ~30k
    // internal one -- and it is a physical wait, not an instruction count.
    delayMicroseconds(10);

    if (releaseRequested()) { matrixScanRow = row; abandonScanPorts(); return false; }

    // One read gets all eight columns (LOW = pressed, HIGH = not pressed).
    // Both it and the mask are shifted down a bit per iteration so the loop
    // stays constant-time -- see the note above the row loop.
    uint8_t cols = PINB;
    uint8_t colBits = joyColMask;

    for (uint8_t col = 0; col < 8; col++, cols >>= 1, colBits >>= 1) {
      // A column JOYSTICK B is holding low reads as every key in it being
      // pressed, exactly as a held row does. Skip those too.
      if (colBits & 1) {
        continue;
      }

      bool pressed = ((cols & 1) == 0);

      // Debounce logic
      if (pressed) {
        if (matrixKeyState[row][col] < MATRIX_DEBOUNCE_COUNT) {
          matrixKeyState[row][col]++;
        }
      } else {
        if (matrixKeyState[row][col] > 0) {
          matrixKeyState[row][col]--;
        }
      }
    }

    // This row's debounce update is complete, so resume from the next one
    if (releaseRequested()) { matrixScanRow = row + 1; abandonScanPorts(); return false; }

    // Restore columns to driving idle high, ready for data transmission
    PORTB = 0xFF;
    DDRB = 0xFF;
  }

  matrixScanRow = 0;  // Sweep complete

  // Release all row lines after scanning, pullups on
  DDRA = 0x00;
  PORTA = 0xFF;

  // Phase 2: Update modifier states from current debounce results
  matrixShiftPressed = (matrixKeyState[5][4] >= MATRIX_DEBOUNCE_COUNT);
  matrixCtrlPressed  = (matrixKeyState[7][0] >= MATRIX_DEBOUNCE_COUNT);
  
  // Phase 3: Fire key events with up-to-date modifier state
  for (uint8_t row = 0; row < 8; row++) {
    for (uint8_t col = 0; col < 8; col++) {
      bool keyPressed = (matrixKeyState[row][col] >= MATRIX_DEBOUNCE_COUNT);
      bool keyWasPressed = matrixKeyLast[row][col];
      
      // Detect key press event (transition from not pressed to pressed)
      if (keyPressed && !keyWasPressed) {
        uint8_t ascii = mapMatrixToAscii(row, col);
        if (ascii != 0xFF && ascii != 0xFE) {  // 0xFF = no key, 0xFE = modifier
          matrixBuffer.push(ascii);
        }
      }
      
      matrixKeyLast[row][col] = keyPressed;
    }
  }

  // Phase 4: Work out which lines the joysticks are holding down
  sampleJoystickMasks();

  return true;
}

// ============================================================================
// Joystick Sampling
// ============================================================================
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

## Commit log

2026-04-30 Schematic fix
    [Storage Card.kicad_pcb, Storage Card.kicad_sch]
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2026-06-21 Silkscreen fix
    [Blinkenlights Card.kicad_pcb]
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2026-08-04 Link the documentation site, and retire the ASSETS pointer
    Adds the guide backlink near the top and replaces 6502-ASSETS with 6502-DOCS in
    the software table, ahead of ASSETS being archived.
    Every reference designator in this README was checked against the schematic of
    the same name, revision by revision, and they agree. (The ACE's did not, and
    were corrected separately.)
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2026-10-27 README: notes for building the older revisions on sale
    What a builder should know before fitting each board, and how to fix it
    by hand: the CPU Card Rev 1.0's pull-ups, the Backplane Pro's RESB
    pull-up (R3 on Rev 1.0, R5 on Rev 1.1) and Rev 1.1's lack of
    reverse-polarity protection, the Blinkenlights Card's LEDs on the shared
    lines, the open-drain rule for Mega Helper firmware, the RAM Card Rev
    1.0's J3 jumpers and single bank latch, and cutting the VGA Card's JP1.
2026-10-27 Backplane Pro Rev 1.2: no RESB pull-up, reverse-polarity protection
    Rev 1.1 is made and in stock, so its fixes go into a new revision, drawn
    now and ordered once the older stock is sold. Two changes from Rev 1.1:
    - R5, the 1k RESB pull-up, is removed. It sat in parallel with the CPU
    Card's 10k; the CPU Card's pull-up is the only one a COB needs, and the
    reset circuit only pulls RESB low, through Q1. Its VCC branch and via
    go with it; the RESB trace ran past its pad and stays.
    - D2, a 1N5819 (DO-41), sits in series between the barrel jack (J1) and
    the power switch (SW1), anode at the jack: the same part and place as
    on the ACE Rev 1.1 and the KIM Board.
    No decoupling capacitors ar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
2026-10-27 Add the Clock Card Rev 1.0
    The Backplane Pro's clock, reset and power on a card, so a COB can be
    built on the passive Backplane, which has neither:
    - Clock: a DIP-14 can (1 MHz, the AC6502's standard PHI2, socketed so a
    builder may fit another) to PHI2 through the clock-enable header J3,
    with JP1 open as made, so the Clock Helper's single-step and halt
    still work.
    - Reset: the 555 power-on and push-button reset, pulling RESB low
    through Q1 only. No RESB pull-up: the CPU Card's is the only one.
    - Power: the barrel jack, a 1N5819 in series and the power LED. No
    power switch.
    - C4 and C5 decouple X1 and U1: every card decouples its own chips.
    The schematic is drawn from the Backplan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
2026-11-03 Clock Card Rev 1.0: put the oscillator and the JST headers on the BOM
    X1, J3 and J4 were marked exclude from BOM, so bom.csv had no oscillator.
    They are on it now, in the schematic and the PCB, the same fix the KIM Board
    had in 0c58b27. J1, JP1, TP1 and TP2 stay excluded.
    Only these flags change. The copper, silkscreen, mask and outline exports are
    identical before and after, so the boards already ordered still match. DRC
    with parity reports 0 violations, 0 unconnected items and 0 parity issues.
2026-11-03 Production: add the CSV files the CPU Card Rev 1.0 and VERA Helper Rev 1.0 never had
    Their exports were never committed and no longer exist, so these come from
    Fabrication Toolkit's own table generator, run on the PCB without saving it.
    The same run reproduces the KIM Board's, the Clock Card's and the ACE's CSV
    files byte for byte. Every pad in a regenerated netlist.ipc sits at the same
    position as in the committed one, so these describe the board as produced.
    The VERA Helper has no bom.csv, because nothing on it is marked for the BOM,
    like the Breadboard Helper and the Keyboard Helper.
2026-11-03 Production: bring four bom.csv files up to date with their PCBs
    The Prototype Card, Serial Card, Storage Card Pro and Video Card exports were
    older than their PCBs. Re-exported with Fabrication Toolkit's own generator,
    which adds the parts they were missing and drops none.
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2026-11-04 Four more helpers: Rev 1.0 is what was made, corrected holes become Rev 1.1
    Clock Helper (order Y74), DB25 Helper (Y65), GPIO Helper (Y66) and Keyboard
    Encoder Helper (Y72) got the same treatment as 8547d58. JLCPCB's copies of the
    orders are byte-identical to earlier exports, and all four predate d3ee3bf
    and its GPIO Helper counterpart, so the boards on hand have the old holes.
    Rev 1.0 returns to each order. Regenerated from the PCBs, copper, mask,
    outline and drill locations match JLCPCB's files, and the silk text is the
    same. Parity is 0. The hole move is the only change between the two
    revisions, apart from one logo moved beside the holes. Rev 1.1 holds it, with
    the holes 6 mm from each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
2026-11-04 Five more COB boards back to their orders, and every order's zip in place
    CPU Card (order Y18), Prototype Card (Y22) and LCD Card (Y27) return to what
    JLCPCB made, proven the same way as 8547d58. Copper, mask, outline and hole
    positions regenerate to JLCPCB's files, and the silk text is the same.
    Prototype Card's Rev 1.0 file was damaged, not improved: a152108 ("Project
    restructuring") moved and rotated J2 without its tracks, which gave it 4
    unconnected nets, clearance errors and a production zip that disagreed with
    it. Restoring it clears all of that, so it gets no Rev 1.1.
    LCD Card's later edit, JP1 open as made, becomes Rev 1.1. CPU Card's Rev 1.1
    already held its later edits; the READM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
2026-11-04 VERA Helper Rev 1.1: the mounting holes at the standard 6 mm
    Rev 1.0's holes were never moved with the other helpers'. Rev 1.1 moves them by
    at most 0.68 mm, to 88 x 68 mm, with the zones refilled. DRC and parity report
    nothing, as on Rev 1.0. Drawn, not ordered.
    The COB's base plate is drilled for the corrected Keyboard Encoder Helper, so
    its mounting drawing now shows Rev 1.1, and the README says that Rev 1.0 stock
    doesn't fit those standoffs. The README's CAD wording is tidied.
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2026-11-04 Keyboard Encoder Helper Rev 1.0: how to fit it on the COB plate
    Rev 1.0 has 88 x 39 mm holes and the plate is drilled for 88 x 38 mm, so
    two plate holes are drilled out to 5 mm. README, the plate mounting drawing
    and REVISIONS now say so. The plate itself doesn't change.
    Also record that CPU Card Pro's title block credit is deliberate, and that
    Joystick Helper Rev 1.1's courtyard overlap with J2 has been reviewed.
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2026-11-04 Board images: every revision rendered the same way
    Front and back, at 2400 x 1600, on white and with no background, in the black solder
    mask and white silkscreen the boards are made with. They replace images that came from
    two methods, in nine different sizes.
2026-11-05 BOM: one set of part numbers across AC6502
    Writes the shared parts catalogue into every schematic and PCB. Each part now
    has the same Digikey, Mouser, Jameco, LCSC and Other fields. Junk fields imported
    with library parts are gone, and so is MPN, because the Fabrication Toolkit
    falls back to it and put it in bom.csv's LCSC column.
    bom.csv is now an accurate BOM. Only card edges, solder jumpers and test points
    are excluded. A blank LCSC cell means JLCPCB doesn't place the part.
    Where the silk doesn't print it, Value says what to fit: BAT85, R6551AP, 33pF and
    so on. A do-not-fit resistor says so. Made boards whose silk prints an old value
    keep it, and the known issues in BOM.md will cover th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
2026-11-05 BOM.md: every part, by revision, with known issues and cart files
    BOM.md has a parts list for every revision, with Digi-Key, Mouser and other
    sources, how to tell which revision you have, and the known issues that change
    what to buy or fit. BOM/ holds a Digi-Key and a Mouser file for each revision.
    Revisions with soldered parts also have through-hole files that leave them out.
    The README's old BOM tables disagreed with the schematics, so they now link here.
    Revision histories and build notes stay in the README.
    Where the build notes say to fit something else, the lists now order that: 10k
    pull-ups on ACE Board 1.0, CPU Card 1.0, DEV Board 1.0 and Main Board 1.0 and 1.1,
    and no RESB pull-up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
2026-11-05 VERA Helper 1.1: 2.5 mm capacitors; everything derived brought up to date
    VERA Helper 1.1 was never produced, so C1 and C2 move to the family's 2.5 mm
    footprint. Pad 1 of each stays put, and pad 2 reaches GND through the pour. DRC
    shows no violations, nothing unconnected and no parity issues. Its production
    files, STEP, images, BOM and schematic PDF are regenerated.
    Video Card Pro and VGA Card Pro were never ordered, and their production zips were
    older than their PCBs, so both are regenerated. Video Card Pro's silk now names
    the ATmega1284.
    Board images are re-rendered for every revision whose silk or fitted parts changed.
    The revision histories say what changed on the silk. 3D model path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
2026-11-05 VGA Card 1.1: socket footprint for U1; 40-pin sockets in the BOM
    U1 moves to DIP-40_W15.24mm_Socket_LongPads. Copper, mask and drill are
    unchanged; silk, fab and courtyard gain the socket outline. Zip, bom.csv,
    STEP and images regenerated.
    BOM.md and carts: 40- and 32-pin socket rows had no part numbers, because
    the generator looked up the wrong catalogue id.
    CherryMX model: stem is blue, matching MX2A-E1NA in the BOM. Keyboard
    Helper's images and STEP re-exported.
2026-11-05 Barrel jack: Same Sky PJ-102AH replaces the obsolete DCJ200-10-A-K1-K
    The manufacturer's footprint, rotated 180 degrees, has the same pad
    positions and body as BarrelJack_Horizontal. Only part fields, BOM.md and
    cart files change: Gerbers and drill files are identical. Not yet fitted
    to a board.
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2026-11-05 Library parts named for what they are, not a part number
    Footprints, symbols and 3D models in "6502 Parts" are named for their
    function and shape (RJ45 Jack LED, CR2032 Holder, 6502 Card Slot, Power
    Switch, SID, ACIA 6551, PIA 6521), so a replacement part with the same
    footprint needs no rename. Every repo carries the same copy of each part,
    re-saved by KiCad 10, and each symbol library holds every symbol its
    schematics use. VCS's 65C02 and 65C22 had wrong pin types; ACE's are now
    in all five. Unused DS01C-254-L-08BE and Mini-Black removed.
    Every revision's Gerbers and drill files export the same before and after.
    DRC is unchanged; ERC loses six missing-symbol warnings. Production files
    for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
2026-11-06 Serial Card Rev 1.1: the silk says SERIAL (DCE) and R6551AP
    Rev 1.0's silkscreen says DB9 FEMALE (DCE) at J2 and 6551 at U3. Rev 1.1
    changes only those two labels, the revision on the copyright line and the
    title blocks. Every Gerber layer but the front silkscreen exports the same
    as Rev 1.0's. Production files, schematic PDF, STEP, images and BOM are
    generated; REVISIONS.md has the History entry.
    REVISIONS.md's footer no longer says the audit last ran on 2026-11-04: it
    gives that date for the order check, and says what each run rechecks.
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2026-11-06 README: shared lines
    A Shared lines section, the same in all five KiCad repos: one 10k pull-up
    on each of RESB, IRQB, NMIB, RDY and BE, on the board with the CPU, and none
    on any other board, so two never sit in parallel. A board's own reset
    circuit pulls RESB low but never carries the pull-up.
2026-11-06 Schematics: bus connectors drawn one way; README: extra pins and HRDB
    Every 6502 bus, cart and card connector on every schematic, made revisions
    included, is drawn one way: a short wire and a global label on each used
    pin, a no-connect flag on each unused one, GND and VCC as global labels,
    and label shapes fixed per signal as the CPU sees it. Bus lines, bus
    entries and local labels for the bus are gone, which clears every "local
    and global labels have same name" ERC warning. Labels match the silk.
    Where bus pins 4 and 6 carry EXP1 and EXP0, or a cartridge grounds them, a
    note on the schematic says what HRDB (High ROM disable bar) does with them.
    The README's new Extra pins section explains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
2026-11-07 Schematics: label shapes follow the signal
    Every global label's shape now shows which way the signal flows at the
    pin it is drawn on: output where it is driven, input where it arrives,
    bidirectional where both, passive for VCC and GND. A bus connector takes
    the board's view: on a board that drives the bus (a CPU board, a
    backplane) the addresses, RWB, SYNC, PHI2 and RESB flow into it and the
    interrupt and control lines come out; on a card a signal flows into the
    edge only if the card drives it (a clock, a reset, an interrupt through
    its diode and jumper) and out of it otherwise.
    The connector redraw had given each label one shape per signal name, so
    address, RWB and PHI2 labels at chip inpu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
2026-11-07 Schematics: keyboard circuit, 74C922 and level shifter labels by signal flow
    The keyboard circuit around the ATmega1284 is labelled as on the ACE
    wherever it appears: the ATmega strobes the matrix on PB and reads PA,
    drives CA1 and CB1 and reads CA2 and CB2; the VIA's port pins and the
    headers carrying its port are bidirectional; a KEYBOARD header takes PB
    in and gives PA out at the encoder, and the reverse at the keyboard's end.
    The 74C922's Y1 and Y2 are inputs: it scans on X and reads on Y.
    VGA Card Pro: INTB_3V3 at Q1's source is an input, from the Pico, which
    drives the interrupt. The check had read Q1's pins in the wrong place.
    No connection changed: each netlist and ERC result is t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
2026-11-07 Schematics: drawn as KiCad draws by default
    - Every GND symbol shows its name, 3.81 mm below it, as KiCad places a new
    one: 128 hid it and most sat at 5.08 mm, an older default. Three moved
    aside by hand stay; one on the DEV Board sits left to clear a label.
    - A global label at 270 degrees is right-justified, as KiCad writes it, so
    the cart GND labels no longer lie over their own tie wire (ROM Cart,
    Flash Cart, Keypad Card).
    - CPU Card 1.0, 1.1 and Main Board 1.0: "Jumper ... for original 6502" is
    text on the sheet, spelled right, not a field on the jumper; the field
    is gone from the schematic and the PCB footprint. The schematic-to-PCB
    check is unchanged and every Gerber layer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
2026-11-07 README, BOM, REVISIONS: which revision to make, and the off-board headers
    Every revision now carries one of three labels, with a one-line reason:
    Tested, Proven design (not built at this revision, but its circuit is a
    tested revision's) or Untested. REVISIONS.md shows it in place of the old
    Tested column, BOM.md beside each revision, and a new README section,
    "Which revision to make", gives each board's newest revision and its label.
    All three are generated from one data file, so they can't disagree.
    A new README section, "Off-board headers", says what the small headers such
    as RESET SW, CLOCK ENBL SW, POWER LED and VCC are for: building a board into
    a case, with the case's parts wired to t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
2026-11-07 Tools/cad/: generate a machine's plate, mounting drawing and STL
    make.py writes CAD/Bases/Plate.svg, the mounting drawing and Plate.stl
    from CAD/Assembly.json, and --check, run by derived-check.py, fails when
    any is out of date. setup.sh makes the build123d venv the STL needs. This
    repository has no assembly file yet (CAD.md C7).
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2026-11-08 Tools/cad/: openings for ribbon-cable box headers; no loose acrylic
    Every box header for a ribbon cable (bus or GPIO) gets a 1.5 mm opening, as
    its plug comes up through the top (owner). A piece of a top that would hold
    no mounting hole is dropped into the opening round it, with a note.
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2026-11-09 Tools/cardedge/: one card edge for every card and cart (KICAD.md K28a) standard.json says it once: the card and cart outlines, placed by the fingers; a cart's four shell holes, each pair centred; no 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
    The library's 6502 Card Edge loses F.Paste and B.Paste, so n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
2026-11-09 Tools/cardedge/: cart holes at 5.0 and 13.0 mm; refilled pours are Proven
    The owner's ruling (KICAD.md K28): a cart's M3 holes go 5.0 mm from the top
    edge and the sides, its M2 holes 13.0 mm from the sides, each pair centred.
    They were 4.849 and 4.95 mm from the sides, a slip in Fusion 360. Proven
    design now covers pours refilled with DRC and the netlist check passing, as
    moving a card's outline refills its pours.
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2026-11-09 The 12 drawn, never-made cards: one card edge (KICAD.md K28b)
    Blinkenlights, CPU, LCD, Serial, Serial Pro, Sound, Storage Pro, VGA and
    Video Card 1.1, and CPU, VGA and Video Card Pro 1.0, fixed in place by
    Tools/cardedge/: no solder mask on the tab, front or back, from the
    fillets' ends down, so the fingers seat and make contact better; no paste
    on the fingers; the outline redrawn to the one card shape around the
    fingers, moved by up to 0.1 mm. The VGA Card 1.1's jack notch stays where
    it was. No track, pad, via or hole moved (gproof.py --no-fill against the
    last commit); the pours are refilled. DRC and parity are as before. Labels,
    History, the CPU and VGA Card build notes and every derived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
2026-11-09 Board images: bare FR4 in its own colour, so a card's bare tab shows
    render.py drew the core with no colour, so KiCad showed bare board almost
    as dark as the black mask, and the cards' new mask-free tabs couldn't be
    seen. The core is now FR4 natural, which shows wherever there's no mask: a
    card's tab, and the thin ring where the mask stops short of a pad. Every
    image is rendered again; the masked areas are unchanged.
2026-11-09 Seven cards: a new Rev 1.1 for one card edge (KICAD.md K28c)
    Clock, GPIO, Memory, Prototype, RTC, Storage and RAM Card 1.1, each a copy
    of its made (or, for the Clock Card, ordered) Rev 1.0 with Tools/cardedge/
    applied: no solder mask on the tab, front or back, from the fillets' ends
    down, so the fingers seat and make contact better; no paste on the
    fingers; the outline redrawn to the one card shape around the fingers,
    moved by 0.04-0.11 mm (the RTC Card's 5.011 mm corners now 5 mm). No
    track, pad, via or hole moved: gproof.py --no-fill against Rev 1.0 shows
    copper, drill and back silk unchanged, the mask changed only over the tab,
    and the paste only at the fingers. DRC: no errors, nothing u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
2026-11-09 Interrupt jumpers: every unmade revision ships by one rule
    An audit of every board's IRQB and NMIB, traced from the PCB nets: an
    open-drain source ships its jumper bridged with the diode fitted; a source
    that drives high ships it open, so the diode stays in the line. Four
    revisions never made broke the rule, and are fixed in place by
    Tools/revision-audit/jumper.py:
    - LCD Card 1.1, JP1 open -> bridged: the W65C22N is open-drain, as on
    Rev 1.0 and every other VIA board. Rev 1.1 is now the card edge alone.
    - VERA Helper 1.1, JP2 bridged -> open: the VERA module drives its
    interrupt high and low (vera-module top.v, extbus_irq_n).
    - VGA Card Pro 1.0, JP2 bridged -> open: the Pico drives its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
2026-11-09 flow.py: a jumper to a rail sets a level; it drives nothing
    The card-edge PHI2 label on the Video Card pointed the wrong way, and
    derived-check passed it. flow.py took any jumper to VCC or GND for a
    source: JP2, which can tie U4's enable to VCC, sits behind JP1 on the
    PHI2 net, so the card seemed to drive PHI2 out to the bus. A jumper to a
    rail is now a pull-up or -down, as a resistor is, whether it ships open or
    bridged; a switch to a rail (a reset button) still drives. The rule in
    KICAD.md K25 is unchanged.
    That flipped both PHI2 labels on every card with a PHI2-enable jumper
    pair, made revisions included: COB RTC Card, VERA Helper and VGA Card
    1.0 and 1.1, VGA Card Pro 1.0, Video Card 1.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
2026-11-09 Video Card 1.1: drop the test jumpers JP1-JP6 (fixed in place)
    JP1-JP6 were for testing the first cards: JP1/JP2 chose PHI2 or VCC for
    U4's enable, JP3-JP6 one or three of U8's inverters for the column
    latch's clock. The tested cards run as Rev 1.0 ships them, so Rev 1.1 is
    wired that way and gives a builder nothing to set: PHI2 straight to U4
    pin 6, /CAS through three inverters to U6 pin 11.
    Schematic: the six jumpers, JP2's VCC and JP3's GND stubs and their
    junctions removed; PHI2 and COL drawn short, COL beside ROW and WR.
    PCB: the six footprints removed; the three that shipped bridged are 0.2 mm
    tracks where their copper strip was; JP5's stubs and the via that served
    only it are gone; p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
2026-11-09 The cards' PHI2 jumper pairs: gone from the revisions not yet made
    Each card's 74HC138 (74LVC138 on the VGA Card Pro) turns RWB and the card
    select into its read and write strobes, and one jumper fed PHI2 to its
    enable E2 while the other could tie E2 high. PHI2 there, as every card
    ships and was tested, keeps the strobes inside PHI2 high, when the
    6502's address and data are valid; tied high they would span the whole
    cycle and glitch while the address settles. So the revisions not yet made
    wire PHI2 straight to E2, with jumper.py remove: the bridged jumper is a
    track where its copper strip was, the open one goes with its feed from
    the supply, and the PHI2 label sits beside E2. Netlist, DRC,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
2026-11-11 Serial Cards: JP2 and JP3 also serve a Rockwell R65C51P1/P2
    The crystal note on the Serial Card and Serial Card Pro, Rev 1.0 and 1.1, now reads
    "Close JP2 & JP3 for WDC W65C51 or Rockwell R65C51P1/P2", moved up one grid step so
    its second line clears the capacitor's reference. On 2026-11-11 an R65C51P2 on a
    Serial Card 1.0 with JP2 and JP3 closed ran clean in an ACE: 6.3 million register
    reads and 100 XMODEM loads. On a bare crystal its oscillator doesn't start.
    The README's jumper advice says the same (Tools/data/jumpers.json). The schematic
    PDFs are regenerated. Only the notes changed: no copper, and no production file.
2026-11-11 Memory Card 1.1: U5, the RB/WB gate, is a 74HCT00
    P11 (2026-11-11): the same gate on the ACE, the KIM and the VCS Main Board, which takes
    a 74HCT00 in every new revision where it drives a RAM. Fixed in place: Rev 1.1 is drawn
    and never made, and Rev 1.0 keeps its 74HC00. TI SN74HCT00DR, LCSC C6764. Same
    footprint; no track moved. Still Proven design: a part value is within that label.
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2026-11-12 Helpers 1.1: the mounting holes exactly 6 mm from the edges
    The DB25, GPIO, Joystick, Keyboard Encoder and PS2 Helper Rev 1.1s were
    drawn, never made, so each is fixed in place and keeps its Proven design
    label. Their holes sat up to 0.084 mm off the 6 mm standard; each moved
    to its nominal place, and the GPIO Helper's H5 to 19 x 31.5 mm. DRC and
    parity are clean, no track or pad moved, and the pours are refilled.
    The Joystick Helper's reviewed courtyard exclusions are re-keyed at the
    holes' new places. Every top still fits.
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2026-11-13 Silkscreen: no JLCPCB order-number marker on the boards not yet made
    JLCPCB stopped printing order numbers in May 2026, and its help page now asks
    for no JLCJLCJLCJLC text on the silkscreen. The text is removed from all 29
    revisions not yet made, the three never-made Pro cards included; Gerbers prove
    only F_Silkscreen changed. Made revisions keep theirs, which JLCPCB ignores.
    Tools: audit.py fails on the marker on a revision not made or ordered,
    table.py shows it in CONSISTENCY.md's Names on silk, and newrev.py drops it
    when it copies a made revision.
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

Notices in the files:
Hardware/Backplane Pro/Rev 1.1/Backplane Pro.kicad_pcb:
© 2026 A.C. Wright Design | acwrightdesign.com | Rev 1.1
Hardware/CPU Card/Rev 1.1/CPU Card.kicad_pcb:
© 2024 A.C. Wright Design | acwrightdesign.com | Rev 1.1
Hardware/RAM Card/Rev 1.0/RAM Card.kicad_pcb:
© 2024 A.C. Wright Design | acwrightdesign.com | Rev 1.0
